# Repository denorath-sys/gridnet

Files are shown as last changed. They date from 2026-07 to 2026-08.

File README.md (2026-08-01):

<p align="center">
  
</p>

# GRIDNET — Powerline Mesh Terminal

> *Communicate over the power grid. No internet. No GSM. No servers.*


[]()
[]()
[]()
[]()

---

## What Is GRIDNET?

GRIDNET is an open hardware mesh communication terminal that uses **existing power line infrastructure** as its transmission medium. Plug the adapter into any wall outlet — the terminal connects to your neighborhood network instantly.

No internet required. No cell towers. No central servers. No accounts.

When grid power fails, the adapter runs from the Terminal's battery over a cable you plug in — the wire is still a conductor whether or not it's energised, so the network keeps working.

The Wi-Fi mesh is not a fallback for the powerline. The two carry to different places: PLC reaches **electrical** neighbours (the same distribution segment, and in practice the same phase), the mesh reaches **physical** ones (adjacent flats, through walls). A neighbour on another phase in the same building is often unreachable over the wire and one mesh hop away. Both run all the time and the router picks per destination — see [`docs/channels.md`](docs/channels.md).

```
Tether:      [Terminal] ←WiFi→ [its own PLC Adapter]      private link to your own modem
PLC:         [Adapter] ←powerline→ [Adapter]              same segment, same phase
Mesh:        [Adapter] ←ESP-NOW→ [Adapter]                physically adjacent, any phase
Outage mode: Grid is down — plug the Terminal into the adapter, network stays alive on battery
```

---

## Why Does This Exist?

Every year, earthquakes, floods, and infrastructure failures cut millions of people off from communication. The internet fails. Cell towers fail. But in most of these scenarios, one thing survives: **the physical power line wiring**.

GRIDNET turns that infrastructure into a resilient local network — inspired by Minitel (France's pre-web national terminal network), FidoNet (a global decentralized BBS built by hobbyists), and the ThinkPad design philosophy (tools built to last).

---

## Hardware Overview

The system consists of two units:

### Terminal
The user-facing device. ThinkPad-inspired clamshell form factor.

| Component | Details |
|---|---|
| **Processor** | GD32VF103CCT6 — RISC-V, 108MHz, 32KB RAM, 256KB Flash |
| **Wireless** | ESP32-C3-MINI-1U — Wi-Fi 2.4GHz mesh + Bluetooth 5.0 LE |
| **Display** | 5.0" TFT LCD, 800×480, RA8875 controller (onboard SDRAM frame buffer), 256 colors, amber-tinted backlight |
| **Keyboard** | 40-key mechanical (Kailh LP), amber LED backlight, red TrackPoint |
| **Right panel** | M1–M4 macro keys + 4×4 numeric keypad + speaker |
| **Speaker** | 1W / 8Ω + PAM8403 amplifier |
| **Storage** | 8MB SPI Flash (LittleFS) + microSD slot |
| **Battery** | 2× 18650, 3350mAh-class genuine cells (~6700mAh total), ~17h active use (screen on) / ~17.5 days standby (screen off, mesh-listen only) — see [`docs/firmware-arch.md`](docs/firmware-arch.md) Power Budget for the full breakdown |
| **Charging** | USB-C, ~4 hours |
| **Antenna** | External, ≤2.33 dBi, on a bulkhead SMA in the case wall — reached by an MHF III / W.FL pigtail from the module's own antenna jack, not by board copper (the module has no RF pad; see [`hardware/pcb/main-board`](hardware/pcb/main-board)) |
| **Dimensions** | 260 × 160 × 28mm, ~680g |
| **OS** | Zephyr RTOS, custom RISC-V BSP |

### PLC Adapter
Separate unit. Plugs directly into any wall outlet (Schuko). Connects to terminal over Wi-Fi — no cables in normal use; during a grid outage the user plugs a USB-C cable in to power it from the Terminal's battery. Replaceable independently.

| Component | Details |
|---|---|
| **PLC SoC** | ST7580 — CENELEC EN50065, OFDM/FSK (band selection under review, see [`docs/electrical-safety.md`](docs/electrical-safety.md)) |
| **Wireless** | ESP32-C3 — Wi-Fi AP for terminal connection |
| **Outage power** | USB-C inlet from the Terminal's battery + 1F supercapacitor hold-up |
| **PLC supply** | MT3608 boost, 5V → 12V for the ST7580's power amplifier |
| **Protection** | TVS P6KE250CA + MOV S20K275 (2 layers; the relay/optocoupler layer went with the inverter) |
| **Power** | HLK-5M05 SMPS, 230VAC → 5VDC |
| **Indicators** | 3× LED: Power / PLC / Wi-Fi |

**Prototype BOM cost: ~$150.22 USD** for one Terminal plus one Adapter — ~$104.35 and ~$45.87 respectively (single unit, retail component pricing). See [`hardware/bom.md`](hardware/bom.md) REV 0.10 for the full breakdown, including why the earlier ~$112 and ~$166.65 figures were both wrong.

---

## Architecture

### Communication Stack

```
┌─────────────────────────────────────────┐
│           APPLICATION LAYER             │
│   Messaging / Games / Forth Apps        │
├─────────────────────────────────────────┤
│           ROUTING LAYER                 │
│   Store-and-forward, 7-day retention    │
│   Mesh routing, automatic repeating     │
├─────────────────────────────────────────┤
│           CHANNEL LAYER                 │
│   Two interfaces, chosen per            │
│   destination by cost — not ranked      │
├─────────────────────────────────────────┤
│           PHYSICAL LAYER                │
│   ST7580 OFDM/FSK, EN 50065-1 limited   │
│   ESP32-C3 Wi-Fi 2.4GHz                 │
└─────────────────────────────────────────┘
```

### Packet Format

```
[AA AA AA][55][LEN 2B][SRC 4B][DST 4B][SEQ 4B][TYPE 1B][PAYLOAD][CRC16 2B]
 preamble  sync  len    source   dest    seq     type     data      checksum

TYPE byte:  [7] SIGNED   [6] RELAYED   [5:0] type code
```

### Addressing

Hierarchical 4-byte address — no central registry required:

```
[CITY 1B][DISTRICT 1B][BUILDING 1B][UNIT 1B]
  01         03           07          12       →  01.03.07.12
```

### Outage Operation

The wire is a conductor whether or not the grid is energising it, so PLC
signalling works during an outage. What stops is the adapter's own power:
it runs from mains, and there is no battery inside it.

So during an outage the adapter runs from the Terminal's battery over a
USB-C cable the user connects. A supercapacitor in the adapter holds it up
long enough to tell the Terminal that mains has gone, so the Terminal can
prompt for the cable. Roughly 5–6 hours of operation with the screen on,
~9 hours with it off.

Nothing is injected onto the wire, and there is no arbitration between
adapters — every node transmits normally under CSMA/CA, exactly as it does
when the grid is up.

Earlier revisions specified a 24V "inverter mode" here instead. It was
removed: it could never have run (the adapter had no power source during
an outage) and it sat 5–24× outside EN 50065-1's signal limits. See
[`docs/plc-adapter-power.md`](docs/plc-adapter-power.md) for the full
analysis, and [`docs/electrical-safety.md`](docs/electrical-safety.md) for
the compliance correction.

### Software Architecture

- **RTOS:** Zephyr (RISC-V support, tickless idle, LittleFS)
- **Boot time:** < 500ms target
- **Tasks:** CHANNEL_MONITOR (0) → PLC_RX (1) → MESH_RX (2) → ROUTER (3) → KEYBOARD (4) → UI (5) → BACKGROUND (6)
- **Filesystem:** LittleFS on 8MB Flash + microSD

Boot screen (Commodore 64 homage):
```
**** GRIDNET OS V1.0 ****
64K RAM SYSTEM  8192K FLASH  BLUETOOTH 5.0
PLC CHANNEL: ACTIVE [3 NODES FOUND]
WIFI BRIDGE: STANDBY  MICROSD: 32GB

READY.
█
```

### Forth VM — Application Platform

Users write and share applications in a sandboxed Forth interpreter (~2KB RAM). Apps are distributed peer-to-peer over the network — like the BBS era.

Security constraints: source address lock, rate limit (5 packets/sec), max 256 bytes/message, filesystem isolation per app.

Example — local market order system in ~15 lines (verified against the
reference VM in [`tools/forth-vm`](tools/forth-vm) — see that directory's
README for why `S"` and `KEY? IF KEY ...` are used instead of the shorter
but non-functional `"` / `KEY? SEND-MSG` you might expect):
```forth
: HEADER
  0 0 S" ╔═══════════════╗" WRITE
  0 1 S" ║  CORNER SHOP  ║" WRITE
  0 2 S" ╚═══════════════╝" WRITE ;

: ORDER
  HEADER
  0 4 S" 1. Bread  2. Milk" WRITE
  KEY? IF KEY S" 01.03.07.99" SEND-MSG THEN ;

: MAIN BEGIN ORDER 1000 WAIT AGAIN ;
MAIN
```

---

## Electrical Safety

GRIDNET puts a low-voltage signal on the mains through a transformer. It does not energise the wire.

- **Signal level is bounded by EN 50065-1**: 5 Vrms at 9 kHz falling to 1 Vrms at 95 kHz. The ST7580's power amplifier delivers 14 V p-p (4.95 Vrms) — ST sized the part to land on that limit — and the adapter adds a hardware current limit as a backstop.
- **PLC signals sit at 95–148.5 kHz**, roughly 2000–3000× the grid frequency. Every household power supply filters that band out; the signal is invisible to their power circuits. Same principle as HomePlug and smart metering, deployed in millions of homes for two decades.
- **Galvanic isolation is mandatory and load-bearing.** The ST7580 reaches the line only through the coupling transformer, and the HLK-5M05 is an isolated supply. The USB-C cable to the Terminal sits on that isolated secondary — the user handles it while the adapter is in a wall socket, so this barrier is what stands between them and the mains.
- **Two protection layers**: TVS (P6KE250CA) for transients, MOV (S20K275) for sustained overvoltage.

⚠️ **One open compliance item**: no EN 50065-1 conformance claim is justified until a conducted-emission sweep is run on a prototype. The band allocation itself is settled — the A-band (9–95 kHz) is reserved for electricity suppliers, so GRIDNET uses B (95–125 kHz) and C (125–140 kHz), and the hardware commits to that choice through Board 1's coupling network ([`docs/plc-coupling.md`](docs/plc-coupling.md), [`docs/protocol.md`](docs/protocol.md)). What remains is the measurement, which needs hardware that does not exist yet. See [`docs/electrical-safety.md`](docs/electrical-safety.md) REV 0.6, which also corrects an earlier claim in this project that a 24V injection was within EN 50065 limits. It was not.

---

## Use Cases

| Scenario | Description |
|---|---|
| 🏚 Disaster response | Coordinate with neighbors when grid, internet, and cell are all down |
| 🏘 Neighborhood messaging | Hyperlocal communication without internet subscriptions |
| 🛒 Local commerce | Shops write their own order systems in Forth — no cloud, no monthly fee |
| 🎮 Games | Turn-based strategy and text adventures played over the power grid |
| 🔒 No cloud | No accounts, no logs, no servers — nothing leaves the neighbourhood. Note that this is *not* the same as confidentiality: the protocol has no encryption yet, and store-and-forward means a message can sit in a relaying neighbour's device for up to 7 days in plaintext. See "Known Gaps" below |
| 👾 Retro / Hacker | Amber display, mechanical keyboard, Forth VM, RISC-V. It boots to READY. |

---

## Project Status

| Component | Status |
|---|---|
| Hardware architecture (dual-board design) | ✅ Complete |
| Communication protocol stack | 🔄 **Under revision — was marked complete, and wasn't.** Three separate design faults are now documented: it does not scale ([`docs/routing.md`](docs/routing.md) — twenty nodes on one segment spend 30.7% of the channel on routing advertisements), it has no authentication of any kind ([`docs/threat-model.md`](docs/threat-model.md)), and its channel model ranks the Wi-Fi mesh as a fallback for the powerline when the two reach different sets of nodes ([`docs/channels.md`](docs/channels.md)). Each has a decided design; none is implemented, and [`docs/protocol.md`](docs/protocol.md) still specifies the old behaviour alongside notices of what replaces it |
| PLC Adapter power architecture ([`docs/plc-adapter-power.md`](docs/plc-adapter-power.md)) | ✅ Complete — adapter runs off the Terminal's battery during an outage; the 24V inverter and its master-election protocol were removed (never able to run, and outside EN 50065-1) |
| Protection circuit (TVS + MOV) | ✅ Complete — two layers, not three: the relay/optocoupler layer went with the inverter. Parts selected ([`hardware/bom.md`](hardware/bom.md)) and now drawn — `P6KE250CA` and `S20K275` are in Board 1's schematic and placed on its PCB |
| Main Board schematic + PCB layout ([`hardware/pcb/main-board`](hardware/pcb/main-board)) | ✅ Complete — custom parts datasheet-verified, PCB placed, routed, ground-poured on both layers, DRC clean (0 violations, 0 unconnected). REV 0.7 was a pre-fab design review that caught a refdes-drift bug placing parts in each other's positions (crystal load caps 51mm from the crystal), a boost-converter switching loop spread across 63mm, and every trace at 0.2mm including a 2.4A path. REV 0.8 found the antenna path was fiction — a phantom U.FL duplicating the module's own jack, a trace nothing could drive, and an invented `ANT` symbol pin — and that the "grid of stitching vias" was nine vias in one column, because `BOX2I.Inflate()` mutates in place (now 167, worst-case return path 55mm → 16.8mm) — see that directory's README |
| PLC/Power Board (BOM's Board 1, the PLC Adapter's PCB — see [`hardware/pcb/plc-board`](hardware/pcb/plc-board)) | ✅ REV 0.3 schematic complete, ERC-clean (350 warnings, 0 errors). Power architecture: Terminal USB-C inlet, Schottky ORing, supercapacitor hold-up, 5V→12V boost feeding the ST7580's `VCC`, hardware transmit-current limit. Line coupling now built too — transmit active filter around the ST7580's own PA, receive resonant filter, and the coupling transformer into the mains. Topology from ST's AN4068, values rescaled from its A-band reference design to GRIDNET's 95–140 kHz band ([`docs/plc-coupling.md`](docs/plc-coupling.md)). PCB placement complete (REV 0.5), now a **four-layer** board: L1/L4 signals, In1.Cu GND plane, In2.Cu +5V plane. Four layers because the ST7580's nine +5V pads on a 48-pin 0.5mm-pitch package need a plane, and two two-layer copper layers are already spoken for by ground and the mains barrier — see that directory's README for the four runs that established it. The 7.96mm isolation barrier cuts all four layers and only the AC-DC module and the coupling transformer cross it; verified geometrically on every pad, track, via and filled zone. Routing (REV 0.6) runs end to end: the autorouter gets 174 nets to 4-10 and the repair step closes most of the rest, but every attempt ends holding exactly one connection. Six defects were fixed getting there — QFN power fanout, pour-before-repair ordering, netclass-aware repair, a mains column too narrow for its own clearance rule, a keepout halo that made a pad unroutable, and a footprint hanging off the board edge. |
| Case design (CAD) | 📋 Planned — only target external dimensions exist (see Hardware Overview); no CAD model |
| Software architecture (Zephyr + Forth VM) | ⚠️ Complete on paper, with one known conflict — [`docs/threat-model.md`](docs/threat-model.md) found that Ed25519's 1–2KB working set does not fit the `ROUTER` task's 2048B stack, which is why the crypto moves to the ESP32-C3 and the node's identity ends up belonging to that module |
| Electrical safety analysis | ✅ Complete |
| Protocol & Forth VM reference prototypes ([`tools/`](tools/), Python, pre-hardware validation) | ✅ Complete — 90 tests pass. Note that `protocol-sim` implements the protocol as specified today, so the routing, authentication and channel revisions above will need to land there too before they mean anything |
| **PCB fabrication / Hardware prototype** | 🔄 Next step — Main Board has been through two design-review passes and is DRC-clean. RF layout is no longer on its list: there is no RF net on the board (the antenna is a cable assembly from the module's own jack). The stackup is no longer an open decision — it is now `STACKUP` in `build_pcb.py` (1.6mm FR-4, two layers, 1oz copper) and written into the board's own design rules, which turned up that KiCad's manufacturing minimums had been left at zero all along: every "0 violations" this project reported before that had been measured against no process limit at all. The board passes the real rules unchanged. What is left before fab is a return-path review of the SPI/I2C buses and a human eye on the autorouted copper (see [`hardware/pcb/main-board`](hardware/pcb/main-board) "What's not done yet"). Board 1 is further along than "schematic complete" — it is placed, four-layer, and routed end to end but for a single connection every attempt ends holding (REV 0.6). Before it is fabricated it needs that last net closed and the mains creepage/clearance treatment the Main Board never required; before any EN 50065-1 claim it needs a conducted-emission sweep |
| Embedded firmware (Zephyr, on real hardware) | 📋 Planned — starts after PCB prototype |
| **Link-budget survey** (rides along with the prototype) | 📋 Blocking four documented decisions — cross-phase attenuation, how much of a real segment hears itself, mesh reach through actual walls, and ESP-NOW throughput for small frames. Every routing and channel figure in this project is arithmetic from datasheet-class assumptions, not evidence. This is now the cheapest thing that would tell us whether the design is right |
| Field testing | 📋 Planned |

---

## Known Gaps

Things this design does not currently do. They are listed here rather than
left for a reader to discover, because two of them affect whether the
network can be trusted in the situation it exists for.

**There is no message authentication.** `SRC` is a plaintext field in the
packet header, and on a shared broadcast medium any node can set it to any
value. The sandbox rule in [`docs/protocol.md`](docs/protocol.md) —
"source address locked, app cannot spoof sender" — constrains a Forth app
running on its own device; it says nothing about a modified node. The
consequences follow directly:

- **ROUTE poisoning.** The routing layer is distance-vector with no
  authentication, so any node can advertise `hop_count 0` for an address it
  does not own and pull that traffic to itself.
- **Forged emergency broadcasts.** `BROADCAST 0x03` is flooded to the whole
  mesh and signed by nothing.
- **Storage exhaustion.** Store-and-forward holds messages for 7 days on
  behalf of unauthenticated senders.
- **Unverified code distribution.** `APP_DATA 0x10` moves Forth applications
  peer-to-peer, from peers whose identity is not established.

Firmware updates *are* signed — Ed25519, verified by the bootloader
([`docs/firmware-arch.md`](docs/firmware-arch.md)). The network layer has
no equivalent.

A threat model now exists for closing this: [`docs/threat-model.md`](docs/threat-model.md)
scopes the adversary as a hostile neighbour on the same wire, and records
the decisions — Ed25519 identity bound to an address by trust-on-first-use,
signing tiered so that routing, broadcasts and code are always signed while
ordinary messages are opt-in, and the crypto moved to the ESP32-C3 because
Ed25519's working set does not fit the `ROUTER` task's 2KB stack. **Nothing
is implemented**; the wire format above is still the unauthenticated one.

It is also explicit about what authentication does *not* fix — a signed
route advertisement proves who said it, not that the route exists — and
about what stays out of scope: device theft, traffic analysis and jamming.

**`ROUTE` does not scale, independently of security.** Twenty nodes on one
distribution segment would spend 30.7% of a 2.4 kbps channel on routing
advertisements alone. [`docs/routing.md`](docs/routing.md) redesigns it
around a property the original missed — a PLC segment is a broadcast domain,
so one-hop neighbours can be learned passively at zero airtime cost — which
takes the same case to 1.89%. That document also states, for the first time
in this project, what topology the network is assumed to have, and flags
that the assumption has never been measured.

**Duplicate addresses are not detected.** Addresses are self-assigned with
no registry, and `docs/protocol.md` currently attributes collision
detection to CSMA/CA. That is a media-access mechanism — it detects a busy
channel, not two nodes claiming `01.03.07.12`. Nothing in the protocol
notices the duplicate, and the routing table oscillates when it happens.

**No encryption.** Message contents are plaintext on the wire and plaintext
in every relaying device's store-and-forward queue.

---

## Repository Structure

```
gridnet/
├── README.md
├── LICENSE                    (CERN-OHL-W-2.0)
├── CONTRIBUTING.md
├── hardware/
│   ├── pcb/
│   │   ├── main-board/         (Board 2 — KiCad schematic + routed, ground-poured PCB, see its README)
│   │   └── plc-board/          (Board 1 — KiCad schematic + placed PCB, see its README)
│   └── bom.md                 (bill of materials)
├── docs/
│   ├── protocol.md            (full protocol stack)
│   ├── firmware-arch.md       (Zephyr + Forth VM)
│   ├── threat-model.md        (adversary scope, attacks, auth decisions)
│   ├── routing.md             (why ROUTE doesn't scale, and the redesign)
│   ├── channels.md            (PLC vs mesh: what each actually reaches)
│   ├── electrical-safety.md   (CENELEC compliance)
│   ├── plc-adapter-power.md   (adapter power architecture + EN 50065 analysis)
│   └── plc-coupling.md        (line coupling network: AN4068 retuned for B+C)
├── firmware/
│   └── README.md              (planned structure — embedded firmware not started)
├── tools/
│   ├── protocol-sim/          (Python reference implementation of docs/protocol.md)
│   └── forth-vm/              (Python prototype of the sandboxed Forth VM)
└── media/
    ├── logo-cyan.svg
    └── logo-silver.svg
```

Note: `hardware/case/` and `hardware/schematics/` (now just a pointer to
`hardware/pcb/`) aren't in the tree above because there's nothing under
either yet worth listing — see the Project Status table above.

---

## Looking For

- Hardware engineer with embedded systems / PCB experience
- Anyone with real-world ST7580 / PLC field experience
- Zephyr RTOS developers (RISC-V BSP, driver development)
- Forth enthusiasts — help design the VM standard library
- Beta testers willing to run a node in their building

Open an Issue or email directly if you're interested in collaborating.

---

## Inspiration

**Minitel** — France's pre-web national terminal network. A whole country connected, locally, before the internet existed.

**FidoNet** — A global decentralized BBS network built by hobbyists. Store-and-forward over phone lines. No servers. No company.

**ThinkPad** — A design philosophy: every detail intentional, built to last, keyboard first.

---

## License

Hardware designs and documentation: [CERN Open Hardware Licence v2 — Weakly Reciprocal (CERN-OHL-W-2.0)](https://ohwr.org/cern_ohl_w_v2.txt)

Firmware (when released): GPL-3.0

© 2026 Yasar — Open Hardware Project

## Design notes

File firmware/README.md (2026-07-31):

# GRIDNET — Firmware

**Status: Not started.** Firmware development begins after the hardware
prototype is complete and validated — see the top-level README's Project
Status table.

Two Python prototypes already exist and inform this planned structure:
[`tools/protocol-sim/`](../tools/protocol-sim/) validates the protocol/routing stack that `src/router/`
and `src/channel/` will implement, and [`tools/forth-vm/`](../tools/forth-vm/) validates the Forth
VM that `src/forth/` will implement. Neither is a substitute for real
firmware — see their own READMEs for what's actually been tested.

## Planned Structure

```
firmware/
├── README.md              ← this file
├── CMakeLists.txt         ← Zephyr build system
├── prj.conf               ← Kconfig project configuration
├── boards/
│   └── gridnet/           ← Custom Zephyr BSP
│       ├── gridnet.dts    ← Device Tree
│       ├── gridnet_defconfig
│       └── board.cmake
├── src/
│   ├── main.c             ← Entry point, task init
│   ├── plc/               ← ST7580 driver + protocol stack
│   ├── mesh/              ← Wi-Fi mesh (ESP32-C3 interface)
│   ├── router/            ← Mesh routing, store-and-forward
│   ├── ui/                ← LCD driver, screen rendering
│   ├── keyboard/          ← Key matrix, TrackPoint
│   ├── forth/             ← Forth VM + sandbox
│   ├── storage/           ← LittleFS + microSD
│   └── channel/           ← Automatic channel switching
└── bootloader/
    ├── main.c             ← Bootloader (microSD + DFU update)
    └── crypto/            ← Ed25519 signature verification
```

Note that `bootloader/crypto/` is the only cryptography in this tree. The
protocol layer that `src/router/` and `src/plc/` will implement has no
authentication designed for it yet — see [`docs/protocol.md`](../docs/protocol.md)
"Security — What Is Not Protected" before building on it.

## Build Requirements

- Zephyr RTOS v3.x
- West (Zephyr build tool)
- RISC-V GCC toolchain
- Optional: OpenOCD (JTAG debug)

## Contributing

If you have experience with Zephyr RTOS, RISC-V, or ST7580 PLC and want to contribute, please open an Issue or see [`CONTRIBUTING.md`](../CONTRIBUTING.md).

See [`docs/firmware-arch.md`](../docs/firmware-arch.md) for full architecture documentation.

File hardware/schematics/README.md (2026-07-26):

Schematics

This directory was a placeholder before either board had real schematic
work. Both now live under `hardware/pcb/`, alongside their PCB layout
(where one exists) rather than as separate PDF exports:

- `hardware/pcb/main-board/` — Board 2 (Main Board): KiCad schematic +
  routed, DRC-clean PCB.
- `hardware/pcb/plc-board/` — Board 1 (PLC/Power Board, the PLC
  Adapter's PCB): KiCad schematic for the well-specified parts; no PCB
  layout yet, see that directory's README for what's still missing.

This directory is kept as a pointer rather than removed, in case
something still links here.

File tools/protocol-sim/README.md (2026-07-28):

# GRIDNET Protocol Simulator

A pure-Python, hardware-independent reference implementation of
[`docs/protocol.md`](../../docs/protocol.md). It exists to validate the mesh
routing and store-and-forward logic *before* the hardware prototype exists — the firmware architecture doc lists the protocol
stack as "✅ Complete," but until now that meant "specified in prose,"
not "specified and exercised by running code."

No dependencies beyond the Python 3 standard library.

## What it implements

- **Packet framing** (`gridnet_sim/packet.py`) — the exact wire format from
  `docs/protocol.md`: preamble/sync/len/src/dst/seq/type/payload/CRC16, with
  encode/decode and CRC validation.
- **Hierarchical addressing** (`gridnet_sim/address.py`) — the 4-byte
  `CITY.DISTRICT.BUILDING.UNIT` scheme, including the broadcast address.
- **A discrete-event simulator** (`gridnet_sim/simulator.py`) — simulated
  time, not wall-clock time, so a "7-day" store-and-forward expiry costs
  nothing extra to run.
- **A shared-medium / CSMA-CA model** (`gridnet_sim/medium.py`) — one
  `Medium` per PLC segment or per WiFi mesh: carrier sensing, random backoff,
  and collisions between overlapping transmissions. Simplified (no PHY-level
  bit errors, no capture effect) — it's here to exercise the *link-layer
  contention* the protocol assumes, not to model CENELEC OFDM/FSK.
- **Mesh flooding + store-and-forward** (`gridnet_sim/node.py`) — a `Node`
  that floods unknown destinations, relays each `(src, seq)` exactly once,
  and retries undelivered messages until ACKed or expired.
- **ROUTE distance-vector routing** (`gridnet_sim/node.py`) — periodic
  table advertisements (own routes, hop-incremented) per
  `docs/protocol.md`'s REV 0.5 ROUTE Packet section, converging multi-hop
  reachability + next-hop info one hop per round, RIP-style hop-count cap
  and staleness pruning included.

## Running it

```bash
cd tools/protocol-sim
python3 run_demo.py --list
python3 run_demo.py master-failover
python3 -m unittest discover -s tests -v
```

Nine scenarios are in `gridnet_sim/scenarios.py`: `basic-exchange`,
`multihop-flood`, `routing`, `store-and-forward`, `channel-fallback`. 29
unit tests in `tests/` cover packet framing, flooding loop-prevention,
store-and-forward and distance-vector route convergence — all deterministic
(seeded RNGs), run in well under a second.

## Findings — and the fixes applied for them (REV 0.5)

Building and extending this surfaced three things about the *documented*
protocol (two REV 0.4 behavioral gaps, one packet type named but never
defined) and two bugs in the simulator's own code, one found while fixing
the other. All five were fixed.

> **Note on #1–3.** These concern the inverter master election protocol,
> which has since been **removed from GRIDNET entirely** — the PLC Adapter
> turned out to have no power source during a grid outage, so it could never
> have run an inverter, and the 24V injection the protocol arbitrated sat
> well outside EN 50065-1's limits. See
> [`docs/plc-adapter-power.md`](../../docs/plc-adapter-power.md). The
> corresponding code, tests and scenarios are gone from this simulator. The
> writeups are kept because the reasoning — about jitter, listen windows and
> shared RNG state — is worth having on the record, and because #5 in
> particular is a general lesson that outlived the feature that exposed it.

### 1. FIXED — Simultaneous grid loss reliably triggered split-brain, not just as an edge case

REV 0.4's initial listen delay was a flat 2 seconds with no jitter. The most
common real-world trigger — an entire building or block losing grid power at
once — meant every device on the segment hit that 2-second timeout at the
*same instant* and every one of them tried to become master simultaneously,
every run. Split-brain detection resolved it correctly (lower address wins),
but that made split-brain the *primary* path for the most common outage
pattern, not a rare fallback — working against the doc's own rationale for
avoiding simultaneous injection ("voltage conflict... signal corruption...
excess current").

**Fix**: `grid_lost()` now uses `LISTEN_DELAY + random(0, LISTEN_JITTER)`
(2s + up to 500ms). Whichever device draws the shortest delay usually
asserts first and the others just hear it — no split-brain needed for the
common case. `scenario_master_election` demonstrates the fixed convergence;
`scenario_master_election_worst_case` / `test_split_brain_still_resolves_ties`
force an exact jitter tie to prove split-brain still works as the residual
safety net, same as REV 0.4.

### 2. FIXED — A new device could steal mastership from a stable, already-elected master

REV 0.4 stated: *"A new device always listens first. If it hears
MASTER_ALIVE, it becomes a slave."* But it used the same 2s window for
joining as for a fresh grid failure — much shorter than the 10s
MASTER_ALIVE interval, so a device joining at an arbitrary moment only had
roughly a 20% chance of its listen window actually overlapping a heartbeat.
The other ~80% of the time, it heard nothing, timed out, and declared itself
master. If its address happened to be lower than the existing master's, it
won the resulting split-brain and forced an already up-and-running master to
step down and resign — a real service interruption caused purely by unlucky
join timing, not any actual fault.

**Fix**: joining is no longer routed through the same short delay as a
self-witnessed grid failure. New method `cold_join()` — for a device
powering on or rejoining while the grid is already off, which can't assume
no master exists — uses `JOIN_LISTEN_DELAY + jitter` (12s, i.e.
`MASTER_ALIVE_INTERVAL + 2s` margin), reliably spanning a full heartbeat
cycle. `scenario_cold_join` and
`TestColdJoin.test_reliably_hears_existing_master_regardless_of_join_timing`
(swept across four join offsets spanning the heartbeat cycle) demonstrate
it now converges every time.
`test_grid_lost_is_the_wrong_call_for_joining_an_existing_segment` is kept
as a regression guard on the API distinction: calling `grid_lost()` instead
of `cold_join()` for a join still reproduces the old bug, which is correct —
that method's short delay is only safe for the scenario it's meant for.

### 3. FIXED (simulator bug, not a protocol issue) — a float-rounding edge case could permanently skip failover

While stress-testing fix #1 across many runs, `_check_master_timeout`
occasionally never triggered failover at all, even 30+ seconds after the
master went silent. Cause: it recomputed `sim.now - last_master_alive_heard
>= MASTER_TIMEOUT`, and floating-point rounding could land that a hair under
30 (observed: `29.999999999999996`), even though the callback is only ever
scheduled for exactly `last_heard + MASTER_TIMEOUT`. Since nothing else ever
rechecked it, the node just stayed `INV_SLAVE` forever, pointing at a master
that was gone. The check was redundant anyway — a matching `_inv_epoch` (the
staleness guard already used everywhere else in this file) already
guarantees no newer heartbeat arrived — so it's removed rather than patched
with an epsilon. Confirmed via a 300-run stress loop with unseeded jitter
after the fix (0 failures, previously ~35% failure rate).

### 4. FIXED (protocol gap) — ROUTE (0x04) was named but never defined

`docs/protocol.md`'s message-type table listed `ROUTE 0x04 — Routing table
update` alongside the (then-present) MASTER_ALIVE and MASTER_RESIGN types,
but unlike those two — which had full C structs — ROUTE had zero payload
definition anywhere — and "Mesh Routing" claimed every device maintains "a
neighbor table (address, hop count, last seen)" with no mechanism specified
for how a hop count beyond 1 would ever be learned. The simulator's own
flooding logic only ever produced 1-hop `known_nodes` entries
(deliberately segment-scoped) — there was no path to actual
multi-hop reachability info anywhere in this codebase either.

**Fix**: `docs/protocol.md` REV 0.5 now defines ROUTE as a distance-vector
advertisement — `{address:4B, hop_count:1B}` entries, periodic (60s, chosen
for airtime reasons — see the doc), never flooded (each device re-advertises
its own table, RIP-style propagation), with a 15-hop cap and 3-interval
staleness window. Implemented in `Node._advertise_routes` /
`Node._on_route`; `scenario_routing` and `tests/test_routing.py` demonstrate
a 4-node/3-hop chain converging to correct hop counts and next-hops in both
directions.

### 5. FIXED (simulator bug, not a protocol issue) — a shared RNG silently broke already-seeded tests

Wiring up ROUTE's periodic advertisement needed a randomized startup stagger
(so devices booting together don't broadcast in lockstep forever). The first
version drew it from `self._rng` — the same RNG `grid_lost()`/`cold_join()`
use for listen-delay jitter, and the one tests seed for reproducibility. That
extra draw at construction time shifted every subsequent draw from that
stream, silently changing the jitter values the already-passing
then-present inverter-master tests depended on — `test_simultaneous_grid_loss_no_longer_reliably_collides`
started intermittently failing (split-brain rate crept from comfortably under
20% to 23%) with no change to that code at all. Fixed by
giving the ROUTE stagger its own independent `self._route_rng` — sharing a
stateful RNG across unrelated concerns is exactly the kind of coupling that's
invisible until something downstream reads the stream differently.

## Assumptions made where the docs didn't specify a value

- **CRC16 variant**: CCITT-FALSE (poly `0x1021`, init `0xFFFF`) —
  `docs/protocol.md` says "CRC16" without naming a polynomial. Swap
  `gridnet_sim/crc16.py` if firmware settles on something else; nothing else
  depends on the specific algorithm.
- **Dedup / relay window**: 15 seconds — how long a node remembers a
  `(src, seq)` it has already relayed, so it doesn't repeat itself. Not
  specified in `docs/protocol.md`; chosen shorter than the retry interval so
  a legitimate retry isn't mistaken for a duplicate and silently dropped by
  intermediate relays.
- **Store-and-forward retry interval**: 30 seconds — not specified; the doc
  only gives the 7-day total retention.
- **ROUTE advertisement interval**: 60 seconds, hop cap 15, staleness 3
  intervals (180s) — none specified before REV 0.5; see `docs/protocol.md`'s
  ROUTE Packet section for the airtime-cost rationale behind 60s.

## Repository layout

```
tools/protocol-sim/
├── README.md              (this file)
├── run_demo.py             CLI entry point
├── gridnet_sim/
│   ├── address.py          4-byte hierarchical addressing
│   ├── crc16.py             CRC16/CCITT-FALSE
│   ├── packet.py             wire framing, encode/decode
│   ├── medium.py              shared broadcast channel, CSMA/CA, collisions
│   ├── node.py                 flooding, store-and-forward, distance-vector routing
│   ├── scenarios.py             five runnable demonstrations
│   └── simulator.py              discrete-event core
└── tests/
    ├── test_packet.py
    ├── test_flooding.py
    ├── test_routing.py
    └── test_store_and_forward.py
```

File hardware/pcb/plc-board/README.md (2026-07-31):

GRIDNET — PLC/Power Board KiCad Schematic + PCB
REV 0.6 (Board 1, the PLC Adapter's own PCB — see "Board 1 is the PLC
Adapter's PCB" below.)

What changed in REV 0.6
------------------------

**The stackup is a rule now, not a sentence.** `STACKUP` in `build_pcb.py`
is written into the board's design settings: 1.6mm FR-4, four layers, 1oz
outer copper (0.5oz inner, which does not matter here — the inner layers carry
only planes and every current-carrying trace, the 1.0mm mains nets included,
is on an outer layer), 0.2mm minimum track and clearance, 0.6mm vias on 0.3mm
drills, 0.15mm annular ring, 0.25mm hole-to-hole.

This came out of closing the same item on the Main Board, where it exposed
something worse than an undocumented assumption: KiCad's minimums default to
zero, and both boards carried `m_TrackMinWidth = 0.0` and
`m_MinClearance = 0.0` through every DRC run this project has reported. A
0.05mm trace would have passed.

It caught something here immediately. The power fanout sends each of U4's
power pads 1.6mm straight out, and those pads are on a 0.5mm pitch — so their
vias landed on a 0.5mm pitch too, which with a 0.3mm drill is 0.2mm
hole-to-hole against the 0.25mm rule. Three pairs. The fanout now checks
hole spacing and steps a crowded neighbour further out.

A routing pass. It did not finish — every run still ends one connection
short — but what it found is worth more than the routing would have been:
six separate defects stood between this board and a routed one, and each was
invisible until the router hit it.

**The QFN's power pins had no fanout.** The ST7580 puts nine +5V pads on
three edges of a 48-pin 0.5mm-pitch package. Nothing passes between adjacent
pads there, so each escapes radially, and the router then has to bring nine
radial escapes back together around the outside of eleven others. Every run
this project had made died on that. `add_power_fanout()` now gives each power
pad a 1.6mm stub and a via at build time — what a person does by hand on a
QFN and what no autorouter does for itself.

**The pour ran after the repair, so the fanout vias were islands.** Planes
are what connect those vias; until the copper is poured they are isolated
points, and the repair router was being asked to tie them together — the
exact problem the fanout removes. `route.sh` now pours before repairing. This
is not the ordering the Main Board warns about: there the danger is pouring
before *routing*, which makes the autorouter treat GND as done. With those
two changes together, +5V stopped being a holdout at all.

**The repair router ignored netclasses.** It laid 0.2mm track at 0.2mm
clearance into the `Mains` class, which is 1.0mm at 2.5mm — on the mains side
that is not a style question, it is the live-to-neutral spacing. Seven
clearance errors in one run, every one on `/AC_L`, `/AC_N` or `/PLC_LINE`,
all laid by the step meant to be finishing the job. It now reads the rules
from the same table `build_pcb.py` writes into the project file: KiCad 9's
Python binding returns `GetNetClass()` as a bare object with no accessors, so
importing the source of truth is both simpler and harder to get out of step.

**Correcting that exposed a floorplan that could not satisfy it.** Four mains
nets at 1.0mm and 2.5mm need a 3.5mm pitch — about 16.5mm of channel with
margins — and the mains column had 9.7mm once the parts were in it. The
varistor lying flat is 22mm wide and blocked the column outright. `BARRIER_X`
moved from 30 to 36, the varistor and the X1 capacitor now stand on end, and
the isolated side gave up 6mm it was no longer short of.

**And then `/AC_N` still would not route — the repair router again.** It
stamped rule areas as obstacles inflated by the netclass clearance, which for
a mains net is a 3mm halo. The isolation band starts at x = 32.02, so the halo
reached 29.02 and swallowed T1's own mains pad at 30.92: that pad was
unroutable by construction. A keepout is a boundary, not a conductor — copper
may come up to its edge, it just may not cross. Stamping it with half the
track width instead closed `/AC_N` in two segments.

**A footprint was hanging off the board.** The JTAG header was moved to the
top edge without checking its height: 13.79mm upright, centred at y = 4.6, put
a third of it past y = 0. A whole routing run went by before anything noticed,
and what noticed was the repair router reporting an unconnected item at
y = −0.58. `check_on_board()` is now one line of arithmetic at placement time.

Where that leaves routing: the autorouter gets 174 nets down to 4–10, the
repair step closes most of the rest — eleven connections in one run — and each
attempt ends holding exactly one. The holdouts are now a different ordinary
signal every time (`/PLC_LED`, `/ST_CL`, `/ST_BR0`) rather than the systematic
`+5V` cluster they were before, which is the signature of a board at the edge
of what this toolchain does rather than of a defect. A ten-attempt run was
started to let nondeterminism land it; Freerouting hung on the first attempt
for 46 minutes and the run timed out. That hang is documented in the Main
Board's README too.

The board committed here is therefore placement, not routing: 62 components,
25 thermal vias, 11 power fanouts, two keepout zones, DRC clean at 0 errors.

What changed in REV 0.5
------------------------

**This is a four-layer board now**, and not for signal density — it could very
nearly be routed on two. It is four because of what has to be *planed*.

```
  L1  F.Cu    signals, all components
  L2  In1.Cu  GND plane      (4984 mm², isolated side only)
  L3  In2.Cu  +5V plane      (4960 mm², isolated side only)
  L4  B.Cu    signals
```

The ST7580 puts nine +5V pads on three edges of a 48-pin 0.5mm-pitch package.
Nothing passes between adjacent pads there — a 0.2mm track with 0.2mm
clearance needs 0.6mm and the gap is 0.25mm — so every pin escapes radially,
and those nine have to find each other around the outside of eleven other
escapes. **Four full two-layer routing runs failed on exactly that**, and
never on the same pad twice: (52.05, 6.70), (59.45, 11.25), (59.45, 8.25),
and twice on the pin 3 / pin 48 pair that wraps the top-left corner. A fifth
run with a filled +5V island on F.Cu routed cleanly — and was then broken by
its own ground pour, which chopped the island from 413 mm² to 109 mm² and
stranded eight connections. That net wants a plane, and on two layers both
copper layers are already spoken for by ground and the mains barrier.

**The barrier goes through all four layers.** An inner plane that crossed it
would bridge mains to SELV *inside the laminate*, where no inspection would
ever find it. Both keepout rule areas are on all four copper layers and both
planes stop at `SELV_MIN`; that is checked, not assumed — the filled polygons
start at exactly x = 33.98.

Two things the layer change taught, both recorded in `route.sh` so they are
not rediscovered:

- **Do not mark the inner layers `(type power)` in the DSN.** KiCad writes
  every copper layer as `(type signal)`, and rewriting the two inner ones does
  stop Freerouting laying signals across the planes — but it also stops it
  treating those planes as connecting GND and +5V, so it routes both as
  ordinary nets on two layers and fails badly: 52 unrouted against 7 without
  the change. The planes take some cutting from inner-layer signals; each is
  ~5000 mm² and the refill after routing closes around whatever crosses them.
- **The repair router had no idea planes existed.** It indexed a two-entry
  layer tuple with whatever layer it found a track on, and threw on the first
  inner-layer track. It now ignores inner-plane copper for its F.Cu/B.Cu
  occupancy grid, and can terminate a connection with a via down to a plane
  instead of a track to another pad — which on a planed net is usually the
  correct answer and is what Freerouting itself does.

Routing is **not finished**; see "What's not done yet".

What changed in REV 0.4
------------------------

The board has a PCB. `plc-board.kicad_pcb` places all 62 components inside
the 100×80mm outline, with thermal vias under both exposed pads and the
design rules written into `plc-board.kicad_pro`. Nothing is routed yet.

The thing that shapes this layout and did not exist on the Main Board is that
**half of this board is at mains potential**:

```
  x = 0                     BARRIER_X = 30                       x = 100
  |<----- mains side ------>|<-- 7.96mm -->|<--- isolated side --->|
  | J1 mains in, TVS, MOV,  |   no copper  | ST7580 + coupling     |
  | X1 cap, series inductor |  either side | filter, ESP32, power  |
  |                         |              | tree, USB-C to the    |
  |         U1 (HLK-5M05) --+--------------+-- Terminal, LEDs      |
  |         T1 (coupling) --+--------------+                       |
```

Only two parts cross that band, and each crosses it *inside its own body*,
where the manufacturer rather than this project is responsible for the
insulation: the HLK-5M05 (AC pins one end, DC pins 33.6mm away at the other)
and the coupling transformer. **The barrier's width is not a number this
project picked**: it is what T1's own land pattern leaves between primary and
secondary once the 2.2mm pads come off the 10.16mm pitch. Würth sized that
gap for a transformer whose entire job is to sit across a mains barrier.

Three mechanisms keep it that way, because placement alone would not:

- `check_isolation_barrier()` in `kicad_gen/build_pcb.py` tests **every pad of
  every net** on the board — not just the parts someone remembered to
  classify as mains — against the band, using pad bounding boxes rather than
  centres, since it is the copper edge that matters for creepage. It also
  asserts that exactly `U1` and `T1` have pads on both sides. The build
  refuses to write a board that fails either test; that refusal was checked by
  deliberately dragging `C17` across the barrier and confirming it fired.
- **The ground pour is clipped to the isolated side.** This is the one
  function that could not be reused from the Main Board unchanged. There the
  pour is the whole board; here a full-width pour would put GND copper
  straight through the barrier, and it would do it *silently*, because a zone
  is not a track and would not show up in a routing review. The mains side
  gets no plane at all, which is also correct on its own terms — there is no
  mains-referenced ground on this board, since the Schuko earth pin is unused.
- **The stitching-via grid starts at the barrier**, not at the board edge.

What the standards ask, and what is still open: reinforced insulation from
230V mains to a user-accessible SELV circuit is usually quoted around 5mm
creepage and 3–4mm clearance (IEC 60950-1 / 62368-1, pollution degree 2,
material group IIIa), with 8mm a common industry rule of thumb that includes
margin. 7.96mm sits in that band. The insulation here has to be *reinforced*
rather than basic, because the user physically handles the USB-C cable on the
isolated side while the adapter is in a wall socket. Confirming the exact
figure against the standard itself is listed under "What's not done yet" — it
is the one number in this layout taken from convention rather than from a
document this project has read.

Two findings came out of running DRC on the first placement, neither of which
a schematic pass could have surfaced:

- **The mains connector could not meet its own clearance rule.** The 2.5mm
  L-to-N spacing in the `Mains` netclass is the standards-derived figure; the
  5.08mm-pitch terminal block leaves 2.08mm between its own pads. The part was
  the placeholder, not the rule, so `J1` is now a 7.62mm-pitch Würth block.
- **The ST7580 footprint's built-in thermal vias are 0.2mm**, under the 0.3mm
  minimum in this project's board setup and JLCPCB's standard process, which
  hardware/bom.md's PCB line assumes. All 25 came back as `drill_out_of_range`.
  `U4` now uses the plain QFN footprint and `add_thermal_vias()` lays a 4×4
  array at 0.3mm — 4×4 because that is the array AN4068 measures the part's
  50 °C/W on, not a round number.

And one the DRC could not have found, which took rendering the board and
looking at it: **the ESP32-C3-MINI-1's antenna was in the middle of the
board.** The `-1` variant has an on-module PCB antenna and a real keepout
zone in its footprint (5.4 × 13.2mm, marked "Antenna Area", blocking copper
pour, tracks and vias), and the first placement had it surrounded by circuit
on all four sides. It is now at the right edge with the antenna facing out.
Note the asymmetry with the Main Board: that one carries the `-1U`, whose
datasheet Note A says explicitly it has *no* keepout zone because its radio
leaves on a cable. Same datasheet, same pin table, opposite layout rule.

What changed in REV 0.3
------------------------

The line coupling is built. That was the last open block on this board and
the reason its PCB layout had not started: the ST7580 datasheet specifies
the PA's pins but not the network hung off them, and AN4068 — which does —
could not be retrieved from this environment. It was eventually read, and
the whole section between `TX_OUT`/`PA_OUT` and the mains now exists.

The values are **not** AN4068's. Its reference design is a CENELEC A-band
node — receive filter on 80 kHz, coupling resonance on 85 kHz, sensitivity
specified at 86 kHz — and A-band is allocated to electricity suppliers.
GRIDNET sits in B+C, 95–140 kHz, which puts our entire band on the skirt of
their filters. Each resonance was rescaled to ~117 kHz holding AN4068's own
Q values and its own ratios between corner frequency and band edge; every
resistor keeps its reference value and only the reactive parts move.
[`docs/plc-coupling.md`](../../../docs/plc-coupling.md) has the arithmetic,
the cross-checks, and what the filters still do not do.

Also settled here: the coupling transformer. AN4068 names the part
(**Würth 750510231**), and its specification sheet meets every line of
AN4068's Table 4 except the withstanding-voltage row, where it quotes
2000 VAC for 1 s against Table 4's ≥4 kV — different tests, not necessarily
a conflict, but not something to assume about a galvanic barrier to 230 V.
It carries a custom symbol with the part's real terminal numbers (primary
1–4, secondary 10–7) rather than KiCad's generic 1/2–3/4 transformer, and a
footprint built from the sheet's own recommended land pattern.

What changed in REV 0.2
------------------------

REV 0.1 left three gaps and said they needed power-electronics design
this project's docs didn't specify: no supply for the ST7580's 8–18V
`VCC`, no gate driver for the IRF540N inverter, and no defined inverter
topology. Trying to answer them turned up two problems that made the
questions themselves wrong, both written up in **docs/plc-adapter-power.md**:

1. **The adapter had no power source during an outage at all.** Its only
   supply was the HLK-5M05, which needs 90–264V AC. When the grid fails
   the adapter stops — so it could never have run an inverter, and the
   24V it was supposed to inject could not have powered a neighbouring
   adapter either. The firmware protocol had already been written against
   a battery (`MASTER_ALIVE.battery_pct`) that the BOM never contained.
2. **The 24V injection is outside EN 50065-1.** The A-band limit is
   5 Vrms at 9 kHz falling to 1 Vrms at 95 kHz; 24V is 5–24× over it. The
   ST7580's own PA delivers 14 V p-p — 4.95 Vrms — because ST sized the
   part to land on that limit.

So REV 0.2 does two things. The adapter is now **powered from the
Terminal's battery** over a detachable USB-C cable, with a supercapacitor
covering the moment of grid loss. And the **inverter is gone**, replaced
by a proper 12V rail for the power amplifier that was always going to do
the actual signalling.

Two of the three original gaps were therefore closed rather than deferred.
The third — the coupling transformer and PA output network — waited on one
specific document rather than on open design questions, and REV 0.3 closed
it too.

What this is
------------

A KiCad 9 schematic (`plc-board.kicad_sch`) for the PLC Adapter's main
board: mains input protection, the HLK-5M05 AC-DC supply, the ST7580
power-line-communication modem, an ESP32-C3-MINI-1 as Wi-Fi AP + UART
host, status LEDs, and a programming header. Like the Main Board, it's
generated by Python scripts in `kicad_gen/` (reusing that directory's
`sexp.py`/`make_symbol.py`/`pinmap.py`/`schematic.py` verbatim — they're
generic, not Main-Board-specific) rather than hand-drawn.

No PCB layout exists yet for this board — this pass is schematic only,
same staging Main Board went through (schematic, then a separate
placement pass, then routing).

Board 1 is the PLC Adapter's PCB
----------------------------------

hardware/bom.md lists both "Board 1 — PLC/Power Board" and a separate
"PLC Adapter (Separate Unit)" section, which read as two different things
at a glance. They're not: the top-level README's Hardware Overview
describes only **two** physical products, the Terminal (Board 2 — Main
Board's system) and the PLC Adapter, which talk to each other over Wi-Fi
only — the Terminal has no powerline hardware at all. Board 1's component
list (ST7580, 2x IRF540N, TVS, MOV, relay, PC817, HLK-5M05) matches the
PLC Adapter's own hardware table in the top-level README line for line.
Board 1 *is* the PCB inside the PLC Adapter housing; the BOM's two
sections just cost out the same board from two different angles (bare
PCB + parts vs. the fully assembled product including enclosure, plug,
and LEDs).

Two BOM inconsistencies fell out of confirming this and were fixed in
hardware/bom.md as part of this pass (see that file's "Design Notes — REV
History" item 6 for the full writeup):
- The PLC Adapter's enclosure was spec'd at ~80×80×40mm, too small for
  Board 1's own 100×80mm PCB — a REV 0.4 estimate that never got
  reconciled against the PCB size, unlike the other stale REV 0.4 numbers
  already caught elsewhere in the BOM. Corrected to ~110×90×30mm.
- Board 1's `J1` connector was described as a "main board interface,"
  which read as if it connected to Board 2. It doesn't — Board 1 and
  Board 2 are different products that never connect to each other. `J1`
  is this board's own connector to the Adapter's Schuko-plug wiring and
  status LEDs (not present in the current schematic pass — see below).

What this covers, and what it deliberately doesn't
-----------------------------------------------------

This board builds every part of the circuit that's fully specified by a
primary source — a datasheet section, or an unambiguous line in this
project's own docs — and stops there rather than guessing at the parts
that aren't.

### The power architecture (REV 0.2)

Three sources feed one 5V rail, ORed with Schottky diodes:

```
  mains ──► HLK-5M05 ──┐
                       ├──►┤◄── +5V ──┬──► AMS1117-3.3 ──► +3V3
  Terminal ─► USB-C ───┘              │
                                      └──► MT3608 boost ──► +12V ──► ST7580 VCC
                                 10Ω ─┴─ 1F supercap
```

- **ORing with Schottkys** (`D5`/`D6`) rather than an ideal-diode
  controller, consistent with this BOM's price point. ~0.3V drop leaves
  ~4.7V, above the boost's input minimum and still enough headroom for
  the AMS1117 at the ~100mA it supplies.
- **`J4`, the Terminal inlet**, is a USB-C receptacle strapped as a sink
  (5.1k CC pull-downs), power-only — no USB data on this board. It sits
  on the HLK-5M05's *isolated secondary*. The user handles this cable, so
  the isolation barrier docs/electrical-safety.md calls non-negotiable is
  what stands between them and the mains side.
- **`C7`, the 1F supercapacitor**, charges through `R11` (~500mA inrush
  limit) and discharges through `D7`, keeping the resistor out of the
  discharge path. Its job is not to keep the adapter running — it is to
  keep the ESP32-C3 alive long enough to tell the Terminal over Wi-Fi
  that mains has gone, so the Terminal can put "connect the adapter
  cable" on screen. 6.4J per farad between 5V and the boost's ~3.5V
  minimum; a couple of seconds of Wi-Fi is well under 1J.
- **`U5`, the MT3608 boost**, is a real KiCad library part, not a custom
  symbol. Values from its own datasheet: `VREF` = 0.6V and
  `VOUT = VREF × (1 + R1/R2)`, so 12V needs R1/R2 = 19 — 19.1k/1k gives
  12.06V. 22µH inductor (its recommended 4.7–22µH range), 22µF ceramic in
  and out, plus 100µF bulk on 12V to ride transmit bursts. It's an
  asynchronous boost, so the rectifier `D8` is external.

12V was chosen for `VCC` because it sits mid-window in the datasheet's
8/13/18V range and well clear of the 6.1–7.5V undervoltage lockout.

### Transmit current limit

The ST7580 has a hardware output-current limit set by one resistor. It
mirrors 1/`CL_RATIO` of the PA output current through `RCL` to `VSS` and,
once that voltage passes `CL_TH`, walks `TX_GAIN` down a step at a time
until it's back under (datasheet Section 5.4):

```
RCL = CL_TH × CL_RATIO / I(PA_OUT) peak     CL_TH = 2.35V, CL_RATIO = 80
```

Checked against the datasheet's own Table 8: 1 A RMS FSK is 1.41 A peak →
2.35 × 80 / 1.41 = 133 Ω, exactly the tabulated value.

`R14` = 270R sets a 500 mA RMS ceiling, bounding what the Terminal's
battery has to supply. It's a backstop, not the operating point —
firmware sets `TX_GAIN` lower still on battery. `CL_SEL`, which would
switch `RCL` between FSK and PSK crest factors, is not used; one fixed
resistor means the effective ceiling differs slightly between
modulations, which is fine for a backstop, and it's a digital output so
leaving it open is safe.

What *is* built and ERC-clean:

- Mains input (`J1`) with Layers 1-2 protection: TVS (`D_TVS`,
  P6KE250CA) and MOV (`Varistor`, S20K275) across L/N.
- HLK-5M05 AC-DC supply, isolated 5V output.
- ST7580: every digital, control, clock, and power/ground pin that the
  datasheet fully specifies — UART to the ESP32, JTAG debug header,
  baud-rate selection, reserved-pin handling, the 8MHz crystal (no
  external load caps needed, both `XIN`/`XOUT` have them integrated),
  and the complete power/ground scheme from the datasheet's own Figure 8
  (supply structure) and Figure 9 (ground scheme) — reproduced exactly,
  not approximated.
- ESP32-C3-MINI-1 (on-module PCB antenna, no antenna connector): Wi-Fi AP, UART host
  for the ST7580, a UART0 programming header (without this or a USB
  connector there'd be no way to flash the module at all — an omission
  this pass caught and fixed, not something any existing doc specified).
- Status LEDs: Power (always-on), PLC (driven directly by the ST7580's
  `PL_TX_ON`), Wi-Fi (GPIO-driven, so firmware can blink it for real
  status rather than it being a second always-on LED).
- **The line coupling (REV 0.3)**: the transmit active filter around the
  ST7580's own power amplifier (`R15`/`C12` R-C pre-filter, then a
  Sallen-Key cell on `PA_IN±`/`PA_OUT`), the receive passive filter into
  `RX_IN`, and the coupling itself — DC block, `T1`, the series inductor
  and the X1 safety capacitor into `AC_L`/`AC_N`. Topology from AN4068
  section 7.1, values rescaled from its A-band centre to GRIDNET's B+C
  band. Every number in [`docs/plc-coupling.md`](../../../docs/plc-coupling.md).

Datasheet verification
------------------------

All three custom-built symbols were checked pin-by-pin against
primary-source datasheets before being written into
`kicad_gen/build_library.py`, same
standard as the Main Board's parts:

- **ST7580** — checked against STMicroelectronics' real datasheet
  (DocID022644 Rev 2, obtained via LCSC's CDN after ST's own site and
  several mirrors were unreachable from this environment — see the
  session history for what didn't work). Figure 2 (pinout diagram) and
  Table 2 (pin description) for all 48 pins + exposed pad; Figure 8/9 for
  the power and ground scheme; Section 7 for the crystal spec. This is a
  from-scratch symbol (ST7580 isn't in any KiCad bundled or
  community library found), so every pin was being verified for the
  first time, not checked against a prior (possibly wrong) version like
  the Main Board's parts were.
- **ESP32-C3-MINI-1** — same datasheet and Table 3-1 already used to
  verify the Main Board's ESP32-C3-MINI-1U, since both modules share one
  datasheet and pin table. Pin list is identical to that symbol, full
  stop: Table 3-1's 53 pads are the same for both variants and neither
  has an RF pad. This symbol has no `ANT` pin, and neither does the Main
  Board's any more — the one it used to have was invented, and the pad it
  claimed to name does not exist on either module (see
  ../main-board/README.md's "The antenna path never touched the board").
  The difference between the variants is only where the radio goes: an
  on-module PCB antenna here, an on-module W.FL/MHF III jack on the -1U.
- **Würth 750510231** (the coupling transformer) — terminals and every
  electrical parameter checked against Würth's own specification sheet
  (rev 6E, 8/22). It exists as a custom symbol for one reason: the real
  part's terminals are **1/4** (primary) and **10/7** (secondary), while
  KiCad's `Device:Transformer_1P_1S` numbers its pins 1/2 and 3/4. Using
  the generic symbol would have put a wrong pin number into the netlist
  and shown up, if at all, on the PCB — which is exactly how this project
  has lost two passes already. Its parameters against AN4068 Table 4 are
  tabulated in [`docs/plc-coupling.md`](../../../docs/plc-coupling.md);
  six of seven rows pass outright and the seventh (withstanding voltage)
  is an open question about test methods, not a failure.
- **Footprints**: ST7580 uses a bundled KiCad `QFN-48-1EP_7x7mm_P0.5mm`
  footprint sized to the datasheet's Table 14 exposed-pad dimensions
  (5.1×5.1mm typ., closest bundled option). ESP32-C3-MINI-1 uses the
  real footprint vendored from Espressif's official KiCad library into
  `gridnet_footprints.pretty/` (CC-BY-SA 4.0), same source and process as
  the Main Board's MINI-1U footprint — see that directory's README.md.
  `T1` uses a footprint built for this project from the "recommended P.C.
  pattern" on Würth's own sheet: four ⌀1.20mm holes on a 10.16 × 7.62mm
  rectangle, 14.22mm square body, 13.48mm high.

Real KiCad library parts used as-is (same confidence as any normal KiCad
design, no custom symbol needed): `Device:D_TVS`, `Device:Varistor`,
`Converter_ACDC:HLK-5M05` (exact bundled match for the BOM part),
`Regulator_Linear:AMS1117-3.3`, `Device:FerriteBead`, `Device:Crystal`,
`Device:R`/`C`/`LED`, and generic connectors.

ERC result
----------

```
kicad-cli sch erc plc-board.kicad_sch --format json -o /tmp/erc.json
```

**350 violations, 0 errors.** (This file said 212 until REV 0.3 re-ran it.
That figure predated the REV 0.2 pass which took the board from 29 to 47
components, and nobody re-counted; the categories and the reasoning below
were unchanged by either pass, only the off-grid endpoint count, which
grows by one per new pin.) Same benign categories as the Main Board's ERC
results, for the same reasons (see that board's README for detail):
`endpoint_off_grid` (345, cosmetic), `lib_symbol_issues` (3) and
`footprint_link_issues` (2) (this headless environment doesn't have
`gridnet_parts`/`gridnet_footprints` registered as project libraries;
both load and place correctly regardless).

Two ERC categories that came up during this pass and are worth naming
explicitly, since they're not just cosmetic noise silenced by rote —
each reflects a real judgment call:

- `power_pin_not_driven` on the mains connector's `AC_L`/`AC_N` pins and
  on the ST7580's internally-generated rails (`VDD` x2, `VDD_REG_1V8`,
  `VDD_PLL`, `VCCA`, `VSSA`). Both are legitimately not driven by
  anything *on this board* — mains power comes from the wall, and those
  ST7580 pins are fed by the chip's own internal regulators from `VDDIO`
  (datasheet Section 6: "not designed to supply external circuitry...
  accessible for filtering purposes only"). Each got a `PWR_FLAG`, with
  a comment citing the specific reason, rather than being silently
  wired to something to make the warning go away.
- `pin_not_connected` on the ESP32's `IO2`/`IO3` and (before the
  programming header was added) `U0RXD`/`U0TXD` — real omissions this
  pass caught while building, not intentional simplifications. Fixed
  (see above), not just flagged.

Net plan (high level)
----------------------

- **Mains protection:** `AC_L`/`AC_N` (from `J1`) — TVS and MOV both
  shunt across the pair, not in series with it.
- **Power:** `AC_L`/`AC_N` → HLK-5M05 → `+5V` (isolated secondary,
  becomes this board's logic ground reference) → AMS1117-3.3 → `+3V3`
  for the ESP32.
- **ST7580 UART:** `TXD`/`RXD` ↔ ESP32 `IO4`/`IO5` (a secondary UART on
  spare GPIOs, not the ESP32's own `U0RXD`/`U0TXD`, which are reserved
  for flashing the ESP32 itself via the programming header).
- **ST7580 control:** `RESETN` ↔ ESP32 `IO6`, `T_REQ` ↔ ESP32 `IO7`,
  `BR0`/`BR1` strapped high for 57600 baud (Table 3 of the datasheet).
- **ST7580 power/ground:** exactly Figure 8/9 of the datasheet — see
  "What is built" above.
- **Status LEDs:** Power → `+5V` direct. PLC → ST7580 `PL_TX_ON` direct.
  Wi-Fi → ESP32 `IO8` (active-low sink).

What's not done yet
--------------------

- **A conducted-emission measurement.** The coupling network is built and
  its arithmetic checks out, but harmonic suppression is inherently weaker
  in B+C than in the A band — a 95 kHz carrier puts its second harmonic at
  190 kHz, below the Sallen-Key corner, where the 3-pole network only takes
  off ~2.7 dB. The ST7580's own transmitter linearity (0.1–0.2 % THD,
  −70 dBc typical HD3) is doing most of the work. AN4068 earns its
  compliance claim with a LISN sweep (its section 8.2); GRIDNET needs the
  same before claiming EN 50065-1 conformance. See
  [`docs/plc-coupling.md`](../../../docs/plc-coupling.md).
- **The transformer's withstanding voltage.** Würth quotes 2000 VAC for
  1 s; AN4068 Table 4 asks for ≥4 kV, which comes from EN 50065-4-2's
  impulse test. Probably compatible, not demonstrably so — confirm with
  Würth before fabrication.
- **`ZC_IN` (zero-crossing)** — deliberately not built, not merely absent.
  The datasheet calls it optional, docs/protocol.md defines no
  mains-synchronous behaviour, and during an outage there is no mains to
  synchronise to. AN4068's circuit is recorded in docs/plc-coupling.md if
  it is ever wanted; note that its Figure 14 could not be read, so the
  block cannot be built from that list alone.
- **Routing.** The pipeline runs end to end and gets close — 152 unrouted
  down to 4-8 from the autorouter, with the repair step closing most of what
  is left (`+5V`, `/ST_PA_OUT`, `/AC_N`, `/PLC_LINE`, `/ST_TMS`,
  `/ST_VDD_REG_1V8` across runs) — but no run has produced a complete board.
  Each ends holding one connection.

  Two specific things stand in the way, both in `finish_routing.py` rather
  than in the design:

  - **`drop_via_to_plane()` reports success without checking it helped.** It
    stitched the same point three times in one run: it finds a legal via site,
    returns True, DRC reports the same pair unconnected, and it stitches
    again. It also chose a site 0.1mm from pin 48's pad — same net, so it
    added nothing. It needs to verify the reported connection actually closed,
    and to stitch the endpoint that is a *pad* rather than whichever end comes
    first.
  - **U4 pin 3 (VDDIO, left edge) has no reachable via site.** The pad sits
    directly over solid +5V plane copper — confirmed, the filled polygon
    contains its coordinates — so the connection it needs is a via, not a
    track. There is no legal site within the helper's 6mm search, which is a
    congestion problem on the QFN's left edge, not a search-radius one.

  Everything else the routing pass needed is in place and verified: the DSN
  carries the barrier as a `keepout` on all four layers, the repair router
  respects rule areas, and `check_isolation_barrier()` now runs on copper —
  pads, tracks, vias and filled zone polygons — where it has already caught
  one real defect (stitching vias hanging 0.3mm into the band, because the
  grid started at `SELV_MIN` and a via has a radius).
- ~~The pour sliver past the antenna keepout~~ — closed in REV 0.5. A second
  rule area now covers the strip between `U2`'s antenna keepout and the right
  board edge, on all four layers.
- **The creepage figure itself.** 7.96mm comes from T1's land pattern and
  sits inside the range convention quotes for reinforced insulation at 230V,
  but this project has not read IEC 60950-1 or 62368-1 directly. Every other
  number in this design traces to a datasheet; this one does not yet.
- **The Layer 3 protection circuit** is not deferred any more — it is
  **deleted**. Relay, optocoupler and voltage sensing existed only to
  isolate the inverter from the line, and there is no inverter. Layers
  1–2 (TVS, MOV) remain and are built.
- ~~**Which CENELEC band, in the protocol docs.**~~ Closed. The hardware was
  never undecided — the coupling network is tuned for B+C, 95–140 kHz, and
  changing that means changing four component values — and docs/protocol.md
  now describes that band throughout. What remains is the conducted-emission
  sweep any EN 50065-1 claim depends on, which needs a prototype.
- **`J1`'s replacement**: the BOM's `J1` (Schuko-plug + LED wiring) isn't
  in this schematic pass — the mains connector here (also called `J1` in
  the generated schematic, a coincidental naming collision, not the same
  connector) stands in for wherever the Adapter's own plug wiring
  attaches, and the status LEDs are wired directly to the board's power
  rails rather than through a separate interface connector.

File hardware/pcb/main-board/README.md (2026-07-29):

GRIDNET — Main Board KiCad Schematic
REV 0.8 (matches hardware/bom.md's Board 2 — Main Board bill of materials)

What this is
------------

A KiCad 9 schematic (`main-board.kicad_sch`) for the Main Board, covering
the full circuit from hardware/bom.md's "Board 2" line items: USB-C power
input, Li-ion charge/boost/regulation, the GD32VF103CCT6 MCU with clock/
reset/boot/SWD, SPI flash + SRAM + microSD + RTC, the ESP32-C3-MINI-1U
wireless module, and the off-board connectors for the display, keyboard
controller, keyboard backlight, and speaker. There is no antenna path on
this board and no RF net — see "The antenna path never touched the board".

Alongside it, `main-board.kicad_pcb` has every part placed within the
100x80mm board outline from hardware/bom.md, **fully routed** on 2
layers (F.Cu/B.Cu) with sized power traces, and **poured with ground on
both layers**. `kicad-cli pcb drc` comes back completely clean: 0
violations of any severity, 0 unconnected items.

REV 0.8 continues the pre-fab review with two findings that the REV 0.7
pass created the conditions to see, both about things the board *claimed*
to have and did not:

1. **The antenna path never touched the board.** A phantom U.FL connector
   (`J7`) duplicating one the module already carries, a fictional `/ANT_RF`
   trace to the SMA, and an invented `ANT` symbol pin behind both. All
   three are gone, and with them the RF layout gap that headed "What's not
   done yet". See "The antenna path never touched the board".
2. **The "grid of stitching vias" was one column of nine**, because
   `BOX2I.Inflate()` mutates in place. The pours were tied together only
   down the left edge: the worst-case point on the board was 55mm from the
   nearest GND via. Now 16.8mm. See "The stitching grid was one column of
   nine vias".

REV 0.7 was the pre-fabrication design-review pass over the routed board.
Four things came out of it, in rough order of how badly they would have
bitten:

1. A **reference-designator drift bug** that had silently moved a dozen
   components into each other's board positions — including the 8MHz
   crystal's load capacitors, which ended up 51mm and 34mm away from the
   crystal. See "Reference-designator drift" below.
2. The **IP5306's switching loop spread across the whole board** — the
   boost inductor sat 63mm from the IC. See "The IP5306 switching loop".
3. **Every trace on the board was 0.2mm**, including the boost path
   rated for 2.4A. See "Trace widths".
4. **No ground plane** — every ground connection was an ordinary routed
   trace. See "Ground pours".

A fifth finding is about the tooling rather than the board: Freerouting
reports success while silently dropping connections, so the flow now
verifies with DRC and repairs what is missing. See "Routing".

An earlier revision also regenerated this PCB after it had been routed
against a *wrong* netlist: the datasheet verification pass described
below fixed real pin-numbering bugs in three of the four custom parts,
which changed which schematic pin number carries which signal for the
MCU, the ESP32-C3 module, and the IP5306, so the old copper was not just
stale but actually wrong (see "Datasheet verification results").

Neither file is hand-drawn in the KiCad GUI: both are generated by the
Python scripts in `kicad_gen/` — the schematic places components at grid
coordinates and wires them via net-label stubs (the standard label-based
wiring pattern for busy schematics, rather than long point-to-point wires
across the sheet); the PCB script places real footprints using each
part's actual courtyard geometry (measured via `pcbnew`, not guessed) so
placement is collision-free from the start. `kicad_gen/route.sh` drives
the whole sequence end to end; see "Regenerating / validating" below.

The antenna path never touched the board
-----------------------------------------

"What's not done yet" used to open with RF layout: `/ANT_RF` ran from `U9`
to a U.FL pad (`J7`) and on to the edge-mount SMA (`J8`) at whatever width
Freerouting chose, and wanted a coplanar-waveguide geometry computed for
this stackup. Working out that geometry was the plan for this pass. The
first thing that turns up on opening the board is that **`/ANT_RF` has no
`U9` pad on it at all** — the net is two connectors wired to each other,
and nothing drives it.

The ESP32-C3-MINI-1U does not bring its radio out to a castellated pad.
Datasheet v2.2 Table 3-1 lists all 53 pads: pins 1, 2, 11, 14 and 36–53
are GND, and the rest are `3V3`, `EN` and IO. There is no ANT and no RF
pad anywhere in the list. The radio leaves the module through the antenna
jack **mounted on the module itself** — that is what the "U" in `-1U`
means. So:

- `kicad_gen/build_library.py`'s symbol had a pin whose *number* was the
  string `"ANT"`, matching no pad in the footprint. That is why the
  netlist quietly produced a two-connector net instead of an error: KiCad
  ties schematic pins to footprint pads by pin number, and a pin number
  that matches nothing simply contributes nothing.
- `J7` was a second, board-mounted U.FL duplicating the module's own. The
  schematic comment beside it said as much — "U.FL pad on the
  ESP32-C3-MINI-1U module itself" — but it was placed on the PCB as a real
  footprint at (80, 35.53) anyway.
- The trace from `J7` to `J8` was therefore 19mm of copper (three
  segments, 0.2mm wide) between two connectors and nothing else, which is
  what an RF review would have been asked to impedance-match.

Worse, an edge-mount SMA soldered to the board cannot be reached by a
pigtail in the first place: its centre pin *is* a board pad. hardware/bom.md
line items 13 and 14 described exactly that — an SMA connector plus a
"U.FL-to-SMA pigtail" to connect the module to it — which cannot be
assembled as written.

**And the pigtail was the wrong connector generation.** Datasheet section
10.2 specifies the module's jack as the *third generation* connector,
compatible with Hirose **W.FL**, I-PEX **MHF III** and Amphenol **AMC**,
with a body of 2.05 x 1.7 x 1.40mm (Figure 10-3). U.FL / MHF I is the
first generation and about 2.6mm across. A U.FL plug does not mate with it.
Every mention of "U.FL" in this project's Board 2 documentation was wrong
about the part on the module, independently of everything above.

What the board looks like now: `J7` and `J8` are gone from the schematic,
from `PLACEMENT` in `build_pcb.py` and from the PCB; the `ANT` pin is gone
from the symbol; `/ANT_RF` is gone as a net. The antenna is a cable
assembly and a case feature, not copper — an MHF III/W.FL plug-to-SMA-jack
pigtail from the module's own connector to a bulkhead SMA in the enclosure
wall, with the antenna screwing onto that. hardware/bom.md REV 0.6 carries
all three as Board 2 items 13–15, with the connector and pigtail marked as
enclosure/cable parts rather than parts that get placed on this PCB — and
with the antenna itself, which REV 0.5 never listed at all.

This removes the largest item from "What's not done yet" rather than
solving it: there is no controlled-impedance net on this board, no antenna
keepout to observe (datasheet Figure 3-1 Note A: the keepout zone applies
to the PCB-antenna `-1` variant, "the latter has no antenna keepout zone"),
and no RF corridor for via placement to respect. The antenna requirements
move to the cable and the case: 2.4GHz, 50Ω, and **maximum gain 2.33 dBi**,
which is the gain of the antenna Espressif certified the module with —
exceed it and the module's existing test reports no longer cover the
product (datasheet section 10.2).

The stitching grid was one column of nine vias
------------------------------------------------

"Ground pours" below describes a 5mm grid of stitching vias placed
"wherever one fits clear of every courtyard, pad and trace". Counting them
on the finished board: **nine, all at x = 1.1mm, running down the left edge
from y = 1.1 to y = 41.1**, then stopping. Nothing else on the board.

The cause is one line of `add_stitching_vias`:

```python
if any(bb.Inflate(clear).Contains(pt) for bb in courtyards):
```

`BOX2I.Inflate()` is not a pure function. It grows the box **in place** and
returns *itself*, so every candidate point that reached a given box grew
that box by another 0.6mm before testing it. `any()` short-circuits, so
the boxes early in the list grew fastest, and after a few dozen candidates
the first courtyards it tests cover the entire board and reject everything.
The scan walks x-then-y, which is why the survivors are one partial column
at the start of the walk.

Nothing downstream could catch this. DRC does not know how many vias were
*meant* to be there, and a board with too few stitching vias is
electrically legal — just a two-layer board whose return plane is tied to
its other half only along one edge. The pour that a signal on the right
side of the board returns through had to reach the left edge to change
layers.

The fix inflates each box once, up front, outside the candidate loop:

```python
keepouts = [box for _ref, box in courtyard_boxes(board)]
keepouts += [pad.GetBoundingBox() for fp in board.GetFootprints() for pad in fp.Pads()]
for box in keepouts:
    box.Inflate(clear)
```

| | before | after |
|---|---|---|
| GND vias on the board | 22 | 180 |
| of those, on the stitch grid | 9 | 167 |
| worst-case distance from any board point to a GND via | 55.1mm | 16.8mm |

Verified after the fact, since the whole point is that DRC cannot see it:
no stitching via lands inside any footprint's courtyard, and DRC stays at
0 violations / 0 unconnected with 158 more vias on the board.

The remaining 16.8mm worst case is at (18, 58), under the display and
keyboard-controller headers' courtyards, where the grid legitimately has
nowhere to put one. The usual rule of thumb is to stitch at λ/20 for the
fastest edge present. This board's fastest are the SPI buses and USB
full-speed; a 2ns edge puts the knee at 0.5/t_r = 250MHz, and at
v_p = c/√4.3 = 1.45e8 m/s in FR-4 that is λ = 579mm, so λ/20 = 29mm.
16.8mm is inside that. 55.1mm was not. Tightening `STITCH_PITCH` below
5mm would not improve the worst case, which is set by the headers'
footprints, not by the pitch.

Reference-designator drift
---------------------------

The worst finding of this pass, and the one that explains why the other
placement problems went unnoticed: **the schematic and the PCB disagreed
about which component each reference designator named**, and nothing
checked.

`build_schematic.py` used to auto-number reference designators by the
order in which parts were placed in the file, while `build_pcb.py`'s
`PLACEMENT` dict is keyed by reference designator. Adding the IP5306's
inductor and snubber (commit 615f5d2) inserted one resistor and two
capacitors into the middle of the power tree, which renumbered every
later R and C by +1 — and `PLACEMENT` was left with the old numbering,
plus three new entries (`R14`, `C4`, `C5`) for names that were already
taken. No error, no warning: the board simply built with a dozen parts
in each other's positions.

Measured on the board as committed before this pass:

| Part | What it actually is | Where it was placed | Distance from where it belongs |
|---|---|---|---|
| `C3`, `C4` | the 8MHz crystal's 20pF load caps | by the audio amp, and in open board below the MCU | **51mm** and **34mm** from `Y1` |
| `C1`, `C2` | the IP5306's 22uF snubber and VOUT caps | flanking the crystal | **51mm** and **54mm** from `U2` |
| `R14`, `C5` | the audio PWM filter's R and C | in open board below the MCU | **61mm** and **70mm** from `U10` |
| `R9`, `R11` | BOOT1 pull-down, I2C SDA pull-up | in the RTC and ESP32 clusters | ~30mm from the pins they strap |

Crystal load capacitors 34–51mm from their crystal do not work: the
oscillator sees the trace, not the capacitor. This was a dead board, and
it looked fine.

Fixed on both sides of the door:

- `build_schematic.py` now passes an explicit `ref=` for all 48
  components, and `schematic.py`'s `place()` refuses to place anything
  without one. Refdes is now a declaration, not a side effect of file
  order. (`#PWR`/`#FLG` virtual symbols stay auto-numbered — they never
  reach the netlist's component list.)
- `PLACEMENT` entries carry the component's expected value (`"20pF"`,
  `"IP5306"`, …), and `build_pcb.py` checks every one against the
  netlist before placing anything. If the two files ever disagree again,
  the build stops and names the parts instead of quietly producing a
  wrong board.
- `build_pcb.py` also now fails on any courtyard overlap and on
  `PLACEMENT` entries for parts that are not in the netlist.

The IP5306 switching loop
--------------------------

Independent of the drift above: even under the *intended* refdes
mapping, the inductor commit put `L1`, the RC snubber and the VOUT
decoupling cap in the open band below the MCU (y=62–68mm) rather than
next to the IP5306 at (11.5, 5.8). Its stated reason — that the CR2032
holder's real 27x24mm courtyard fills the power-tree column from y=50
down — is true but solved the wrong problem: the parts did not need to
be in that column, they needed to be next to the IC.

A 1uH boost inductor 63mm from its switching node is not a boost
converter. The `SW` node loop area and its parasitic inductance are set
by exactly that distance, and everything the snubber exists to damp gets
worse with it.

Re-placed tight around `U2`, whose BAT/SW/VOUT pins (6/7/8) are all on
its right-hand side:

- `L1` immediately to its right, ~1mm courtyard gap
- `C5` (VOUT decoupling), `R14` + `C4` (the SW-node snubber) on the row
  just below

`SW1` (the PWR_KEY button) moved out to the MCU column to make room. It
is a momentary switch on a static input, so distance costs it nothing —
which is exactly what made it the right thing to displace.

Trace widths
-------------

Every net on this board was routed at the 0.2mm default, including the
IP5306 boost path — flagged for review when the inductor was added, and
fixed here. Netclasses live in `main-board.kicad_pro`, written by
`build_pcb.py`'s `NETCLASSES` table (KiCad 7+ keeps netclasses in the
project file, not the board), so the widths are in place *before* the
board goes to the autorouter rather than being retrofitted onto finished
copper.

Sizing is IPC-2221's external-layer curve at 1oz copper and a 10°C rise:
0.2mm carries 0.74A, 0.4mm 1.23A, 0.8mm 2.03A.

| Class | Nets | Width | Why |
|---|---|---|---|
| `Power_Batt` | `/VBATT`, `/IP5306_SW` | 0.8mm | The board draws 355mA at 5V (docs/firmware-arch.md REV 0.6), ~545mA battery-side, ~0.7A peak with boost ripple, plus the MCP73831's 450mA charge current on the same net. Sized towards the IP5306's own 2.4A rating instead: 0.8mm carries 2.03A at 10°C and the full 2.4A at roughly 15°C |
| `Power_5V` | `+5V`, `VBUS` | 0.4mm | 355mA system plus the PAM8403's ~500mA peak into 1W/8Ω ≈ 0.9A design maximum |
| (default) | `GND`, `/+3V3_MCU`, `/+3V3_RF`, signals | 0.2mm | see below |

**Why the battery class is not 1.0mm** (the exact 2.4A/10°C width): `U2`
is an SOP-8 whose pads are only 0.60mm across the trace direction. A
1.0mm trace would have to neck down at both ends of the shortest and
most critical segment on the net. At 0.8mm, Freerouting necks to 0.601mm
for the last 1.4mm into the pad and runs full width everywhere else,
which is the right answer.

**Why GND and the 3V3 rails deliberately have no class.** GND's current
is carried by the pours, not the traces. `+3V3_MCU` carries ~150mA and
`+3V3_RF` peaks near 350mA on ESP32-C3 transmit — both well inside
0.2mm's 0.74A. A first cut of the table gave all three 0.4mm "for
margin" and **Freerouting could not route any of them**: `U5` is an
LQFP-48 on a 0.5mm pitch, and a 0.4mm trace leaving a 0.3mm pad there
comes within 0.15mm of the neighbouring pad, under the 0.2mm clearance
rule. The MCU's own GND and 3V3 pins were the failures both times.
Wider is not automatically safer — it has to fit the escape geometry at
both ends.

Ground pours
-------------

The board had no ground plane at all: every ground connection was an
ordinary routed trace. Both copper layers now carry a GND zone inset
0.5mm from the outline (`add_gnd_zones` in `build_pcb.py`), filling
6270mm² on F.Cu and 6727mm² on B.Cu.

- **Solid pad connections, not thermal reliefs.** Thermal spokes were
  tried first and left 11 pads "starved" — fewer than the two spokes
  KiCad requires, because a 0603 pad with a trace already attached has
  no perimeter left for a second one. Solid copper costs some
  hand-soldering convenience on ground pins and buys a lower-impedance
  return everywhere; this board is reflow-assembled, so that is the
  right trade.
- **Island removal on.** Copper that ends up connected to nothing is
  dropped rather than left floating for DRC to report.
- **Zone clearance matches the board rule (0.2mm) rather than exceeding
  it**, so the pour can reach between fine-pitch escape traces instead
  of stopping short and stranding copper.
- **Vias**: the 3x3 array under `U9`'s thermal pad (pin 49), which is
  what Espressif's hardware design guidelines actually ask for, plus a
  5mm grid of stitching vias (`STITCH_PITCH`) wherever one fits clear of
  every courtyard, pad and trace — 167 of them. Earlier revisions of this
  file said "9mm grid", which matched neither the constant nor the board:
  what was actually placed was nine vias in a single column, and only the
  count made that visible. See "The stitching grid was one column of nine
  vias".

Two ordering constraints, both learned the hard way:

- **Thermal vias go in at placement time, before routing.** Given the
  space, Freerouting will run B.Cu traces straight under the module;
  vias added afterwards land on top of them (`/AUDIO_SHDN` and
  `/KBL_DRAIN` were both shorted this way).
- **The pours go in after routing, not before.** Zones present at
  DSN-export time become Specctra planes, and the router then treats GND
  as already connected and lays no GND copper at all — which leaves every
  ground connection depending on the pour reaching that exact pad. On a
  dense two-layer board it does not: routing chops the F.Cu pour into
  islands, and DRC found 16 GND fragments and pads stranded that way.
  Routing GND as ordinary traces first and pouring on top gives
  connectivity the router can guarantee, with the pour's lower impedance
  and thermal path on top of it rather than instead of it.

What the pour does *not* yet include: a deliberate return-path review of
the SPI/I2C buses, and any thermal-relief exception for hand-rework.

Per-part confidence levels
---------------------------

Real, verified KiCad library parts — pin data came directly from KiCad's
own bundled symbol libraries, copied programmatically (not retyped), so
these carry the same confidence as any normal KiCad design:

- `Regulator_Linear:AMS1117-3.3` (both LDO rails)
- `Memory_Flash:W25Q32JVSS`, relabeled `W25Q64JVSSIQ` — the whole W25Qxx
  family shares one SOIC-8 pinout across densities (Winbond datasheet
  convention), so the pin assignment is correct even though the symbol's
  base name doesn't match the BOM part number
- `Timer_RTC:DS3231M`, substituted for the BOM's `DS3231SN` — see
  "Design assumptions" below
- `Battery_Management:MCP73831-2-OT`
- `Amplifier_Audio:PAM8403D`
- `Transistor_FET:2N7002` (extends `BSS138` in KiCad's library; flattened
  into a self-contained copy — see kicad_gen/schematic.py)
- All passives (`Device:R`, `Device:C`, `Device:Crystal`), switches
  (`Switch:SW_Push`), the USB-C receptacle, microSD socket, and generic
  pin-header connectors — all real KiCad library parts

Custom-built symbols — generic rectangle body, pins placed by function
name. All four have now been checked pin-by-pin against their real
manufacturer datasheets (see "Datasheet verification results" below);
three had wrong pin numbers and have been corrected in
`kicad_gen/build_library.py` + `kicad_gen/build_schematic.py`.

| Part | Confidence | Why |
|---|---|---|
| `23LC1024` | Verified | Checked against Microchip's real 23A1024/23LC1024 datasheet (DS20005142C) — all 8 pins were already correct, no changes needed |
| `GD32VF103CCT6` | Verified, was wrong | Checked against GigaDevice's real GD32VF103 datasheet (Rev1.6), Figure 2-4 "GD32VF103Cx LQFP48 pinouts" — **35 of 48 pins (14-48) were numbered wrong** and have been corrected; see below |
| `ESP32-C3-MINI-1U` | Verified, was wrong | Checked against Espressif's real datasheet (v2.2) Table 3-1 — **nearly all pin numbers were wrong** (the symbol had numbered its 19 signal pins 1-19 sequentially; the real module is 53 pins with GND/NC scattered through that range) and have been corrected; the placeholder WROOM-02U footprint has also since been replaced with the real MINI-1U footprint, see "Real ESP32-C3-MINI-1U footprint" below |
| `IP5306` | Verified, was wrong | Checked against Injoinic's real IP5306 datasheet (V1.3) — **all 8 pins were numbered wrong**, `LED3` and `SW` were missing from the symbol entirely, and two `GND` pins were invented that don't exist (the real part's only ground is the exposed PowerPAD); corrected, see below |

Datasheet verification results
-------------------------------

Each part's real pinout was pulled from its primary-source datasheet (not
a summary site) and compared pin-by-pin against what the generated
symbol had. Three of the four were substantially wrong:

- **GD32VF103CCT6.** Pins 1-13 were already correct. From pin 14 on,
  the symbol had inserted `VSS_1`/`VDD_1` two positions early, shifting
  every following pin by +2 (and a second such insertion at pins 37-38
  shifted the rest further) — the net effect: 35 of 48 pins named the
  wrong signal. The *real* pinout, once correctly transcribed, matches
  the well-known STM32F103C8/CB LQFP48 numbering exactly (the mirroring
  claim in the old description was directionally right; the symbol just
  didn't implement it correctly pin-for-pin). Fixed in
  `kicad_gen/build_library.py`.
- **ESP32-C3-MINI-1U.** The module has 53 physical pads (mostly GND and
  NC around the perimeter); the symbol had instead numbered its 19
  functional signal pins sequentially 1-19, which matches almost none of
  them. For example the old symbol's pin 8 ("IO4") is the real module's
  `EN` pin; the old pin 17 ("U0RXD") is a real `NC` pad. Every pin was
  re-numbered against Table 3-1 of Espressif's datasheet. The footprint
  was still the WROOM-02U placeholder at this point — fixed separately,
  see "Real ESP32-C3-MINI-1U footprint" below.
- **IP5306.** All 8 numbered pins were wrong, and the symbol was missing
  two of the part's real pins outright: `LED3` (pin 4) and `SW` (pin 7,
  the DCDC switch node). It had also invented two `GND` pins (old 3 and
  6) that don't exist — the real IP5306 only has one ground reference,
  the exposed PowerPAD, which is now modeled as pin 9. Fixing this
  surfaced a real design gap, not just a labeling one: **no inductor
  existed anywhere in this design**, and without one on `SW` the boost
  path (`BAT` -> `VOUT`) can't function. This has since been fixed — see
  "IP5306 boost inductor" below.
- **23LC1024.** Checked as a control/sanity case — it was already
  correct, all 8 pins matched Microchip's datasheet exactly.

**Regenerating the PCB against this fix.** Done in a follow-up pass: netlist
re-exported, `build_pcb.py` re-run (placement is driven by reference
designator + footprint, so component *positions* didn't move, but every
pad's *net assignment* on the MCU, the ESP32-C3 module, and the IP5306
came from the corrected netlist this time), then re-routed from scratch
— the old copper was routed against the old netlist and couldn't just be
relabeled in place. See "Routing" below for how that pass went.

IP5306 boost inductor
----------------------

Fixed as a follow-up to the pin-numbering bug above. The IP5306
datasheet's own "Typical Application Schematic" (Figure 7) shows the
boost/charge inductor bridging `SW` (pin 7) directly to `BAT` (pin 6) —
**not** to `VOUT` as an earlier read of this design guessed; the
`SW`-`BAT` inductor is shared between the buck charger and the boost
discharger, and `VOUT` (pin 8) is a separate internally-switched output.
Added per that reference circuit:

- **L1, 1uH** (`Inductor_SMD:L_6.3x6.3_H3` — a generic shielded power
  inductor footprint, not a specific vendor part; the datasheet doesn't
  specify one either) between `SW` and `BAT`/`/VBATT`.
- **R14 (0.5R) + C4 (22uF) in series**, from the `SW`/`L1` junction to
  GND — the datasheet's `R4`/`C2`, a small RC snubber damping switching
  ringing on the `SW` node. This carries only transient ringing current,
  not the inductor's main current, so a standard 0603/0805 pair is fine
  even though the inductor itself is a boost-converter-current part.
- **C5, 22uF** at `VOUT`/`+5V`, directly at the IC — the datasheet's
  figure uses a 4x22uF bank there; simplified to one cap here, the same
  simplification style already used for the mono audio path elsewhere in
  this design.

All three were new components when the inductor was added, and were
first placed in the open board area below the MCU cluster rather than in
the power-tree column, on the grounds that the CR2032 holder's courtyard
fills that column from y=50 down. That reasoning is what "The IP5306
switching loop" above unpicks: it put a boost converter's switching loop
63mm across the board. They now sit tight around `U2` — see that section
for the current positions.

Real ESP32-C3-MINI-1U footprint
--------------------------------

Fixed as a follow-up to the datasheet verification pass above, which
fixed the schematic symbol's pin *numbers* but left the PCB footprint as
the same-family `RF_Module:ESP32-C3-WROOM-02U` placeholder (a different,
smaller module standing in for placement purposes only — see the old
confidence table entry). Replaced with the real thing rather than
hand-transcribing dimensions off the datasheet's land-pattern drawing
(error-prone for a 53-pad castellated footprint, and exactly the kind of
mistake this whole verification pass exists to catch): Espressif
publishes an official KiCad library at
[espressif/kicad-libraries](https://github.com/espressif/kicad-libraries)
(CC-BY-SA 4.0, the same license terms as KiCad's own official libraries),
and its `ESP32-C3-MINI-1U.kicad_mod` is vendored unmodified into
`gridnet_footprints.pretty/` — see that directory's README.md for exact
provenance. `kicad_gen/build_pcb.py` gained a small `LOCAL_FOOTPRINT_LIBS`
lookup so it can load project-local footprints alongside the ones it
already pulls from KiCad's bundled libraries.

Verified before use (not just trusted because it's "official"): 53
distinct pad numbers, with pad 49 (`GND`) present as the expected 3x3
array of thermal-pad via pads under the module — matches Table 3-1 of
the datasheet the pin list was checked against.

**Effect on the board.** The real footprint's own hole spec resolved the
`drill_out_of_range` warnings that showed up in every DRC run so far in
this document (they were the WROOM-02U placeholder's own 0.2mm holes
against KiCad's 0.3mm minimum rule — never a placement or routing
problem, but real DRC errors regardless). Regenerating placement +
routing against it: **0 DRC violations, 0 unconnected items** — the
first fully clean `kicad-cli pcb drc` run this board has had.

**Update: the remaining GND pads are now grounded** (fixed as a
follow-up to the finding above). The custom symbol only drew 2 of the
module's real ~22 `GND` pin numbers (30 physical pads once the pin-49
thermal array's 9 copper islands are counted individually); Espressif's
hardware design guidelines for this module recommend tying all of them
to the ground plane for RF and thermal performance. `kicad_gen/build_library.py`'s
`ESP32-C3-MINI-1U` symbol now draws every real `GND` pin from Table 3-1
(`1, 2, 11, 14, 36-53`, pin 49 being the 3x3 thermal-pad array —
wiring that one symbol pin to `GND` grounds all 9 physical pads, since
they share the pad number in the footprint), all wired to `GND` in
`build_schematic.py`. Only the module's 14 genuinely `NC` pads
(`4, 7, 9, 10, 15, 17, 24, 25, 28, 29, 32-35`) are still undrawn — there's
nothing to connect them to.

Regenerated schematic (ERC clean) and PCB against this: **0 DRC
violations, 0 unconnected items**, all 30 of `U9`'s `GND` pads confirmed
on the `GND` net.

At the time that left the module's pads electrically grounded through
ordinary routed traces, which satisfies connectivity but not the
thermal-performance intent of Espressif's guidance. REV 0.7 finished the
job: both layers now carry a GND pour and the thermal pad has its 3x3
via array down to it — see "Ground pours" above.

Design assumptions (things this schematic decided that the BOM/docs didn't
spell out)
------------------------------------------------------------------------

- **DS3231M substituted for the BOM's DS3231SN.** Same SCL/SDA/VBAT/
  32KHZ/INT-SQW functionality; DS3231M is the version KiCad ships a real,
  verified symbol for. If REV 0.6 of the BOM should specifically source a
  DS3231SN, the footprint/ordering part number differs but the schematic
  pinout is unaffected (compatible pin function set).
- **USB D+/D- routed to the ESP32-C3's native USB (IO18/IO19), not the
  MCU.** The GD32VF103 has no native USB peripheral, so DFU-over-USB (per
  docs/firmware-arch.md) has to come through the ESP32-C3 module instead.
  This is a design assumption, not a documented requirement — confirm it
  matches the intended firmware update path before relying on it.
- **IP5306 VIN left unconnected; MCP73831 handles charging instead.**
  IP5306 is a combined boost + charge-management IC, but this design uses
  it only for its 5V boost path (BAT -> VOUT) and handles Li-ion charging
  separately with a dedicated MCP73831. IP5306's own charge-input pin
  (VIN) is marked `no_connect` rather than wired to VBUS, to avoid two
  charge controllers fighting over the same battery. The boost path
  itself runs through `L1`, a 1uH inductor on `SW` shared with the
  charger — see "IP5306 boost inductor" above.
- **Mono audio.** PAM8403D is a stereo amplifier, but hardware/bom.md
  specs one 1W/8Ω speaker. INL, INR, and VREF are all tied to the same
  filtered PWM node, and only the left channel output (LOUT+/LOUT-) is
  wired to the speaker connector; the right channel is `no_connect`.
- **CC1/CC2 strapped 5.1k to GND.** Fixed "UFP sink" strapping so any
  USB-C charger or host offers 5V — this board doesn't negotiate USB-PD.
- **BOOT0 has both a pull-down (default: boot from Flash) and a 2-pin
  override jumper** to force it high for factory/recovery reflashing
  without needing a bodge wire.

Net plan (high level)
----------------------

- **Power:** VBUS (from USB-C) -> MCP73831 -> VBATT (battery) -> IP5306
  boost -> +5V -> two AMS1117-3.3 rails: +3V3_MCU (MCU + all digital
  logic) and +3V3_RF (ESP32-C3 module, kept separate for RF supply
  cleanliness).
- **MCU (GD32VF103CCT6):** 8MHz crystal on OSC_IN/OSC_OUT, NRST with pull-up
  + reset button, BOOT0 pull-down + override jumper, BOOT1 pull-down, SWD
  header (SWDIO/SWCLK/+3V3_MCU/GND).
- **SPI1** (SCK/MISO/MOSI shared bus): W25Q64JVSSIQ flash (FLASH_CS),
  23LC1024 SRAM (SRAM_CS), microSD (SD_CS).
- **I2C1:** DS3231M RTC (SCL/SDA, 4.7k pull-ups each), with its own CR2032
  holder on VBAT_RTC (externally-sourced net, PWR_FLAG'd — see below).
- **USART1:** MCU <-> ESP32-C3-MINI-1U (cross-connected TX/RX).
- **SPI2:** MCU <-> RA8875 display module header (SCK/MISO/MOSI/CS/RESET/
  INT).
- **USART2:** MCU <-> CH552G keyboard-controller header.
- **PWM outputs:** KBD_BACKLIGHT_PWM (via 2N7002 low-side switch, drives
  external LED array) and AUDIO_PWM (via an RC filter into PAM8403D's
  audio input).
- Every otherwise-unused MCU/ESP32/RTC/microSD/amplifier pin is explicitly
  marked `no_connect` (not left dangling) — see the bottom of
  `kicad_gen/build_schematic.py` for the full list and why each one is
  unused.

Regenerating / validating
--------------------------

The schematic and its project-local symbol library are both generated,
not hand-edited. To rebuild from scratch:

```
cd hardware/pcb/main-board/kicad_gen
python3 build_library.py     # writes ../gridnet_parts.kicad_sym
python3 build_schematic.py   # writes ../main-board.kicad_sch
```

To validate (from `hardware/pcb/main-board/`):

```
kicad-cli sch erc main-board.kicad_sch --format json -o /tmp/erc.json
kicad-cli sch export svg main-board.kicad_sch -o /tmp/render/
```

Current ERC result (after the datasheet-verification pin fixes, the
IP5306 inductor addition, the real ESP32-C3-MINI-1U footprint, and
grounding its remaining GND pads above, and removing the antenna
connectors): **368 violations, 0 errors.**
All remaining warnings are benign / expected in a headless-generated
schematic without a full project sym-lib-table registered:

- `endpoint_off_grid` (353) — cosmetic, wire/pin endpoints not snapped to
  KiCad's visual grid
- `lib_symbol_issues` (10) — artifact of validating without this
  environment's full symbol-library table registered
- `pin_to_pin` (4) — intentional: each SPI flash/SRAM's `~WP`/`~HOLD` pins
  are tied directly to its own VCC pin (both real, both correct — not a
  wiring bug)
- `footprint_link_issues` (1) — same cause as `lib_symbol_issues`: this
  headless environment doesn't have `gridnet_footprints` registered as a
  project footprint library, so ERC can't confirm the link; the footprint
  itself loads and places fine (see "Real ESP32-C3-MINI-1U footprint"
  above and the DRC result below)

The PCB is a five-stage pipeline, all of it driven by
`kicad_gen/route.sh`:

```
cd hardware/pcb/main-board/kicad_gen
FREEROUTING_JAR=/path/to/freerouting.jar JAVA=/path/to/java-25 ./route.sh
```

which runs, in this order and for the reasons given in "Ground pours"
and "Routing":

1. `build_library.py` + `build_schematic.py` — symbols and schematic
2. `kicad-cli sch export netlist` — the netlist `build_pcb.py` reads
3. `build_pcb.py` — placement, `U9`'s thermal vias, and the netclasses
   written into `main-board.kicad_pro`
4. Specctra DSN out → Freerouting → SES back in, then
   `finish_routing.py` to verify and repair
5. `build_pcb.py --pour` — GND zones, stitching vias, fill

then runs DRC and fails if anything is an error or unconnected. If the
repair step cannot close a gap it throws that routing away and runs
Freerouting again (up to `ATTEMPTS`, default 3) rather than leaving a
hand-patched board that the next regeneration would lose.

Any stage can also be run on its own; they are ordinary scripts.

Current DRC result (routed and poured board): **0 violations, 0
unconnected items** — clean at every severity, including the
`drill_out_of_range` warnings that dogged earlier revisions (those
traced to the WROOM-02U placeholder footprint's 0.2mm holes and went
away with the real footprint). 46 footprints, 86 nets, 806 tracks, 239
vias, both GND pours filled (F.Cu 6385mm², B.Cu 6955mm²).

REV 0.8's board is the REV 0.7 board minus `J7`, `J8` and the three
`/ANT_RF` tracks, plus 158 stitching vias and a refill. That was done as
a subtractive edit rather than a full `route.sh` run: nothing about the
change asks the router to solve anything, and re-autorouting would have
reshuffled all 806 tracks and — per "Routing" below — not deterministically.
`build_schematic.py`, `build_library.py` and `build_pcb.py` were updated
first, so a full regeneration produces the same board content.

Routing
-------

`main-board.kicad_pcb`'s copper (F.Cu/B.Cu) was routed by
[Freerouting](https://www.freerouting.app/) v2.2.4 (the standard
open-source autorouter for KiCad, run via its CLI in headless mode — no
GUI, no manual click-routing) rather than by hand or left unrouted. This
environment ships neither Freerouting nor a Java runtime new enough to
run it, so both were fetched for this pass: Freerouting's jar from its
GitHub releases, and a Temurin JDK 25 (Freerouting 2.2.4 requires
class-file version 69, i.e. Java 25 — the environment's stock JRE was
Java 21).

The exchange is the standard KiCad-\<->Freerouting workflow, all via the
`pcbnew` Python API (no GUI needed for either direction):

```
python3 -c "
import pcbnew
board = pcbnew.LoadBoard('main-board.kicad_pcb')
pcbnew.ExportSpecctraDSN(board, 'main-board.dsn')
"
java -jar freerouting.jar -de main-board.dsn -do main-board.ses \
    --gui.enabled=false -mp 10
python3 -c "
import pcbnew
board = pcbnew.LoadBoard('main-board.kicad_pcb')
pcbnew.ImportSpecctraSES(board, 'main-board.ses')
board.Save('main-board.kicad_pcb')
"
```

**Freerouting reports success while dropping connections.** This is the
tooling finding of REV 0.7, and it invalidates how earlier revisions of
this document read its output. Across a dozen runs on this board:

- It printed "Auto-router session completed … 0 unrouted" and returned a
  session file with `/USART2_RX` **entirely absent** — no wire for the
  net at all.
- It routed one of `J1`'s two D- pads and not the other, and called the
  net finished. `J1` is a reversible USB-C receptacle, so D+ and D- each
  land on two pads with the *other* signal's pad physically between them
  on a 0.5mm pitch; whichever pair gets routed first takes the corridor.
- Which connections it drops **varies between identical runs**. Two runs
  on the same input dropped different nets.

The response is `kicad_gen/finish_routing.py`: after importing the
session, ask KiCad's DRC what is actually unconnected and route it.
Repair is a deterministic grid maze router (A* on a 0.05mm grid, both
copper layers, Manhattan heuristic, vias costed at 12 cells so it does
not stitch gratuitously), with rip-up-and-reroute as a fallback for
connections that cannot be finished around what the autorouter already
committed to. Anything it cannot close makes `route.sh` throw that
routing away and run the autorouter again.

The repair step earns its keep — in successive runs of this pass it
closed `/USB_DN`'s stranded pad, `/BOOT0`, `/SRAM_CS` and `/USART2_RX`,
none of which the autorouter admitted to leaving open.

Things that were tried and do not work, recorded so they are not tried
again:

- **Pre-routing the awkward connections so Freerouting has to work
  around them.** Reasonable in principle and standard practice by hand;
  in practice Freerouting v2.2.4 either hangs for over nine minutes or
  dies with a `NullPointerException` in its own
  `PolylineTrace.normalize`, reliably, whenever the pre-existing wiring
  lands on `J1`'s 0.5mm-pitch pads. Repair after the fact is the only
  order that works.
- **Re-running the autorouter on the partly-routed board** to let it
  finish what it missed. It reports the missing connections as unrouted
  and still cannot place them: by then `U5` pad 40 sits in a 2 x 5.6mm
  pocket of F.Cu with no via site anywhere in it. It routed itself into
  a corner and then said it was done.

Two details of the repair router worth keeping, because both were bugs
first:

- The grid is 0.05mm, not 0.1mm. `J1`'s pad rows sit on a 0.5mm pitch
  with centres at x.x5 coordinates, so a 0.1mm grid cannot land on a pad
  centre at all — and the escape lane between two neighbouring pads is
  exactly 0.45mm, exactly the clearance a 0.2mm trace needs. Half a grid
  cell of rounding closes it.
- Pads are modelled as rectangles. An earlier version used a stadium
  (a segment grown by the pad's short half-dimension), which tucks
  inside a rectangle's corners: a via placed diagonally off a 0603 pad
  passed the check and then failed DRC by 0.03mm.

**A note on trusting the previous `/USB_DN` write-up.** Earlier
revisions of this file described finishing `/USB_DN` by hand with three
F.Cu segments jogging east around the connector, and concluded the west
corridor was full. That analysis was sound for the placement it was
made against, but the placement has since changed — see "USB-C fan-out"
below.

**USB-C fan-out.** `R1` and `R2` (the CC pull-downs) used to sit at
y=30.6, directly east of `J1` between the D+ and D- pad rows, and
`/CC1`'s diagonal run to `R1` closed the only gap the D- pair had to
cross in. They now sit above and below the fan-out band — `R2` at y=27
near its own pad at 28.85, `R1` at y=34 near its own pad at 31.85 —
which is where they belonged anyway.

**Why `/DISP_CS` routed fine this time.** The earlier investigation
(previous PCB revision, see git history for the full writeup) spent
considerable effort diagnosing why `/DISP_CS` wouldn't route, and
concluded the real blocker was `/+3V3_MCU`'s routing elsewhere on the
board. That diagnosis turned out to be moot: the datasheet verification
pass found the MCU symbol's pin 27 was mislabeled `PB12` (the schematic's
`/DISP_CS`) when the real MCU's pin 27 is `PB14` — `PB12` is actually
pin 25. So that entire investigation was against a net that was never
really `/DISP_CS` to begin with; it was whatever the old, wrong netlist
happened to assign to pad 27. On the corrected netlist, the *real*
`/DISP_CS` (pad 25) sits in a different, apparently less congested
neighborhood and Freerouting completed it without issue.

PCB placement notes
--------------------

- **Footprint sizes, not guesses.** Every part's real courtyard geometry
  was measured via `pcbnew` (`build_pcb.py`'s courtyard-center correction,
  and the shelf-packing math behind the `PLACEMENT` dict in that file)
  before any coordinates were chosen. The first hand-placed attempt at
  laying this board out — done *before* checking real footprint sizes —
  produced 7 courtyard overlaps and several pad-to-pad net-shorting
  violations, most notably because the CR2032 holder's real footprint is
  27x24mm (not the few-mm size its schematic symbol suggests). Measure
  first, place second.
- **Footprint anchors aren't always courtyard centers.** Pin headers are
  anchored at pin 1, not the row's midpoint; the SMA edge-mount connector
  (`J8`, since removed — see "The antenna path never touched the board")
  had its body anchored well off to one side of its mounting pin.
  `build_pcb.py` places every footprint once, measures where its courtyard
  actually landed, and corrects the anchor so `PLACEMENT`'s coordinates
  consistently mean "courtyard center" regardless of the footprint's own
  quirks — a real, repeatable bug (not just a cosmetic one) found and
  fixed while placing the two on-board header rows.
- **`no matching net` is expected for `J5` and `J1`.** Each has a few
  real footprint pads (shield tabs, mechanical/detect pins) with no
  counterpart in the schematic's simpler symbol — harmless. `U9` (the
  ESP32-C3-MINI-1U) used to be in this list too, for 34 unmatched pads;
  now that every real `GND` pin is drawn and wired (see "Real
  ESP32-C3-MINI-1U footprint" above), only its 14 genuinely `NC` pads
  are unmatched, which is correct — there's nothing to wire them to.

What's not done yet
--------------------

REV 0.8 closed the item that used to head this list — RF layout around
the antenna path — by establishing that there is no RF net on this board
to lay out, and re-stitching the pours that REV 0.7 only appeared to
stitch. REV 0.7 before it closed trace widths on the boost path and the
ground pour itself. What is left:

- **Return-path continuity for the SPI/I2C buses.** The pours give every
  signal a return plane, but nothing has checked that a bus does not
  cross a slot in the pour where its return current would have to detour.
- ~~A stackup decision~~ — closed. It is now `STACKUP` in `build_pcb.py`,
  written into the board's own design rules rather than into prose: 1.6mm
  FR-4, two layers, 1oz copper, 0.2mm minimum track and clearance, 0.6mm
  vias on 0.3mm drills, 0.15mm annular ring, 0.25mm hole-to-hole.

  Writing it down turned up something worse than an undocumented
  assumption. **KiCad's minimums were left at their defaults, which are
  zero.** `m_TrackMinWidth` and `m_MinClearance` both read back as 0.0mm on
  the finished, DRC-clean board — so every "0 violations" this project has
  reported was measured against no process limit at all. A 0.05mm trace, a
  via with no annular ring, two holes touching: all would have passed.

  The values above are what the board already uses, promoted from
  convention to rule, so DRC now catches anything that drifts *below* what
  the design was drawn to. The routed board passes them unchanged: 0
  violations, 0 unconnected, same as before. That is the point — the rules
  describe this board, they do not reshape it.

  Still open, and a different question: whether these minimums suit the
  manufacturer actually chosen. They are this design's own floor, not a
  claim about anyone's process.
- **A human eye on the autorouted result before fab.** DRC-clean and
  netclass-correct is not the same as well laid out. The specific things
  a review should look at: the density of the escape fan under `U5`, and
  the 16.8mm stitching hole under the top-edge headers.
- A second schematic sheet (and PCB) for the PLC/Power Board and PLC
  Adapter (see hardware/bom.md's Board 1 and "PLC Adapter" sections) — out
  of scope for this pass, which covers Board 2 (Main Board) only.

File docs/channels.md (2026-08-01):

# GRIDNET — The Two Channels

**REV 0.1**

[`protocol.md`](protocol.md) ranks the channels: powerline first, Wi-Fi mesh
second, the mesh used when "line damaged or PLC failed". The README frames
the mesh the same way — a fallback.

That framing is wrong, and [`routing.md`](routing.md) is what exposed it. If
PLC stops at the distribution transformer, the mesh is not a backup for the
powerline; it is the only thing that joins anything the powerline cannot.

This document works out what each channel actually reaches, and what the
routing layer should do with two interfaces instead of a ranked pair.

Nothing here is implemented.

## Wi-Fi is doing two unrelated jobs

The README's diagram runs them together:

```
Normal mode:  [Terminal] ←WiFi→ [PLC Adapter] ←powerline→ [neighbor's adapter] ←WiFi→ [neighbor's Terminal]
```

Both arrows say "WiFi" and they are not the same thing.

**W1 — the tether.** A Terminal reaching its *own* Adapter. The Adapter is
an access point; the Terminal associates with it. This is a private
point-to-point link to the node's own modem, conceptually a cable that
happens to be radio. It carries no one else's traffic and it is not a
network interface for routing purposes.

**W2 — the mesh.** A node reaching *other people's* nodes over ESP-NOW.
This is a genuine second routing interface, and it is the one the README
calls a fallback.

Conflating them is why the mesh reads as an emergency measure. W1 is
always in use, so "Wi-Fi" looks like it is already accounted for.

## What each channel actually reaches

**PLC reaches electrical neighbours. The mesh reaches physical neighbours.
These are not the same set, and neither contains the other.**

That is the whole point, and it is why one cannot be a fallback for the
other.

### PLC's boundaries

| Boundary | Effect |
|---|---|
| **MV/LV distribution transformer** | CENELEC-band signals are attenuated heavily crossing it. Treat a segment as isolated; this design fits no transformer coupler. |
| **Phase** | LV distribution is three-phase and households sit on one of L1/L2/L3. This Adapter couples L-to-N through a Schuko plug, so it transmits on one phase. Cross-phase coupling exists — through the transformer and through connected loads — but with substantial additional attenuation, commonly cited in the 20–40 dB range and highly variable. |

The second one matters more than the first for the use case this project
describes. A transformer district in a European city typically covers a
street or several buildings, so "my neighbourhood" is often within one
segment. But **within a single building, the three phases can partition the
network into up to three groups that barely hear each other** — and the
flats in those groups are interleaved, not separated.

### The mesh's boundary

Physical distance and walls. ESP32-C3 at 2.4 GHz with a ≤2.33 dBi antenna
reaches adjacent and vertically-stacked flats; it does not reach the far end
of a street.

### Why they compose well

The most common way PLC connectivity fails inside a building is **the
neighbour is on another phase** — and that is exactly the case where
physical adjacency holds and the mesh works. The mesh's reach is not a
weaker version of PLC's; it is orthogonal to it, and it covers PLC's
most likely gap.

## The energy argument points the same way

During a grid outage the Adapter runs from the Terminal's battery, so both
channels draw from the same 24.8 Wh. Using [`plc-adapter-power.md`](plc-adapter-power.md)'s
own figures:

| | Power | Rate | Marginal energy per bit |
|---|---|---|---|
| PLC transmit, battery, reduced `TX_GAIN` | 2.7 W (0.5 W idle → 2.2 W marginal) | 2.4 kbps | ~0.92 mJ/bit |
| ESP32-C3 with traffic | ~0.4 W, **already being spent** | ESP-NOW, unmeasured | ≲0.004 mJ/bit |

Two to three orders of magnitude, and robust to pessimistic assumptions —
even charging the mesh its full 0.4 W and assuming only 100 kbps effective
throughput, it still comes out over 200× cheaper per bit.

The reason is that **the radio is already on**. W1 keeps the Adapter's
ESP32-C3 up as an access point at ~400 mW whether or not anyone meshes over
it, and that 400 mW is already the dominant term in the Adapter's 0.5 W
idle draw. Peering with neighbouring Adapters on the same radio adds
almost nothing.

So in an outage — the scenario this project exists for — the channel the
current design treats as an emergency fallback is the cheaper one to use,
and the expensive one is the default.

## Decisions

### C1 — The mesh belongs to the Adapter, not the Terminal

Both units have an ESP32-C3. The mesh should run on the Adapter's:

- **Its position is fixed and known.** It is in a wall socket. The Terminal is carried around, closed, and switched off.
- **Its radio is already an AP and already powered** for W1.
- **It is present when the Terminal is not**, which matters for a network whose store-and-forward relays traffic for seven days.

The Terminal reaches the mesh through its own Adapter over W1 either way, so
this costs the Terminal nothing.

### C2 — All Adapters use one fixed Wi-Fi channel

ESP-NOW peers must sit on the same Wi-Fi channel, and a device acting as an
AP has its channel fixed by that role. If every Adapter picks its own
channel, W1 and W2 cannot both work: two Adapters serving their Terminals on
channels 6 and 11 cannot peer with each other.

So the Adapter's AP channel is a network-wide constant, not a per-device
choice.

The cost is real and should be stated: in a dense building every GRIDNET
Adapter contends on one 2.4 GHz channel, alongside whatever else is there.
GRIDNET's own traffic is kilobits, so this is tolerable, but it is a
deliberate trade rather than a free choice.

### C3 — Two interfaces, one router — not a priority list

This replaces `protocol.md`'s Automatic Channel Selection table.

A node has two routing interfaces, `PLC` and `MESH`. Neighbours are
discovered independently on each — passively, per [`routing.md`](routing.md)
— and a neighbour may appear on one, the other, or both. Destination
selection is per destination, by metric. There is no global ranking, and no
"the wire is damaged" state to detect: a PLC path that stops working simply
stops being advertised, and the mesh path wins on its own.

This is also what makes [`routing.md`](routing.md)'s per-interface split
horizon meaningful — there are now genuinely two interfaces for it to apply
to.
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

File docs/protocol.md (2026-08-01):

# GRIDNET — Communication Protocol Stack

## Overview

GRIDNET uses a custom lightweight protocol designed for low-bandwidth, high-latency powerline communication. Every device is both a node and a repeater.

## Physical Layer

| Parameter | Value |
|---|---|
| Technology | PLC (Powerline Communication) |
| Chip | ST7580 (STMicroelectronics) |
| Standard | CENELEC EN50065, bands B+C (A-band is utility-only, see [`electrical-safety.md`](electrical-safety.md)) |
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

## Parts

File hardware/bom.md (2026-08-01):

# GRIDNET — Bill of Materials (BOM)

**REV 0.10 — Prototype (Single Unit, Retail Pricing)**
*(revision ten, following 0.9 — not 0.1)*

> **REV 0.10 note:** `J1` is no longer an estimate. It is Würth 691311400102,
> the part the PCB footprint has been using all along
> (`TerminalBlock_Wuerth_691311400102_P7.62mm`) — WR-TBL 3114, 2-pole, 7.62mm,
> 300V / 20A (UL), $0.42 at single quantity.
>
> Pricing it surfaced a gap the estimate had been covering: **it is a
> pluggable header, and the plug that mates with it was never in the BOM.**
> Würth 691351400002, $1.25. Without it the board can be fabricated and
> populated with no way to attach the Schuko plug's L/N wires. `J1` therefore
> goes from an estimated $0.70 to a real $1.67 across two line items, and the
> total from ~$149.25 to **~$150.22**.
>
> The one-piece alternative was considered and declined for now — see the note
> under the Board 1 table.
>
> **REV 0.9 note:** this file described a system with three PCBs and two PLC
> modems. It has one of each. Board 1's schematic
> ([`pcb/plc-board/plc-board.kicad_sch`](pcb/plc-board/plc-board.kicad_sch)) carries the ESP32-C3, the
> status LEDs, the mains input and the USB-C outage inlet, which means Board 1
> *is* the PLC Adapter — but a separate "PLC Adapter (Separate Unit)" section
> billed the ST7580, the HLK-5M05, the protection layers and the outage power
> path a second time, and the PCB table ordered a 70×60mm "Adapter Board" that
> was never designed. Both are removed.
>
> Checking the other direction found the mirror-image error: five things in
> that schematic had never been costed anywhere — the ESP32-C3-MINI-1 (`U2`),
> the AMS1117-3.3 that feeds it (`U3`), the 8MHz crystal (`Y1`), the three
> status LEDs (`D2`–`D4`), and the ESP32/ST7580 programming headers (`J2`,
> `J3`). `J1` was also still costed as a 2×8 2.54mm header after DRC forced it
> to a 7.62mm mains terminal block.
>
> Board 1's line items are now keyed to the schematic's reference designators
> so the two can be checked against each other directly. Total moves from
> ~$166.65 to **~$149.25**.
>
> **REV 0.5 note:** several REV 0.4 part choices didn't hold up under review —
> either a real spec mismatch (a display resolution the driver IC can't
> produce) or a part variant that doesn't support a feature the board design
> assumes (an antenna connector with nothing behind it). See "Design Notes —
> REV History" at the bottom of this file for what changed and why.
>
> **REV 0.6 note:** the antenna chain REV 0.5 added to fix that last item was
> itself unbuildable — the wrong connector generation, a connector style that
> cannot be reached by a cable, and no antenna at all. Board 2 items 13-15
> and the totals are corrected here.
>
> **REV 0.7 note:** AN4068 was finally obtained, so Board 1's line coupling is no
> longer a placeholder. The coupling transformer has a real part number, and
> the rest of the coupling network is costed as items 11-13. Note that its
> values are not AN4068's — that reference design is an A-band node and this
> one is not; see [`docs/plc-coupling.md`](../docs/plc-coupling.md).
>
> **REV 0.8 note:** Board 1 is a four-layer board. Not for signal density — it
> could very nearly be routed on two — but because the ST7580's nine +5V pads
> on a 48-pin 0.5mm-pitch package need a plane, and on two layers both copper
> layers are spoken for by ground and the mains barrier. See
> [`hardware/pcb/plc-board/README.md`](pcb/plc-board/README.md) for the four two-layer routing runs that
> established this. The PCB line below moves from 2 to 4 layers accordingly.

## Board 1 — PLC / Power Board (100×80mm)

**This board *is* the PLC Adapter's electronics.** Everything the Adapter does
electrically happens here: mains input and protection, the AC-DC supply, the
ST7580 modem and its line coupling, the ESP32-C3 that serves the Terminal's
Wi-Fi link, the outage power path, and the status LEDs. The Adapter's only
other parts are mechanical — see "PLC Adapter — Non-PCB Parts" below. The two
products in this project are the Terminal (Board 2 + display + keyboard +
battery + clamshell) and the Adapter (this board + plug + enclosure); they
never connect to each other electrically.

Reference designators below are the ones in
[`hardware/pcb/plc-board/plc-board.kicad_sch`](pcb/plc-board/plc-board.kicad_sch), so this table can be
checked against the schematic directly.

| # | Component | Part Number | Description | Qty | Unit Cost (USD) | Total |
|---|---|---|---|---|---|---|
| 1 | PLC SoC | ST7580 | `U4` — CENELEC EN50065, OFDM/FSK, 9–148kHz | 1 | $5.70 | $5.70 |
| 2 | Wi-Fi module | ESP32-C3-MINI-1 | `U2` — Wi-Fi AP for the Terminal's link, and UART host for the ST7580. Plain MINI-1, not the "U" variant Board 2 uses: this board has no external antenna, so the on-module PCB antenna is the right choice | 1 | $0.80 | $0.80 |
| 3 | TVS Diode | P6KE250CA | `D1` — bidirectional, 250V — surge protection (Layer 1) | 1 | $0.60 | $0.60 |
| 4 | MOV | S20K275 | `RV1` — 275V varistor — overvoltage protection (Layer 2) | 1 | $0.40 | $0.40 |
| 5 | SMPS Module | HLK-5M05 | `U1` — 230VAC → 5VDC, 1A, isolated | 1 | $3.50 | $3.50 |
| 6 | Boost converter | MT3608 | `U5` — 5V → 12V for the ST7580's VCC/PA rail, 2A switch | 1 | $0.30 | $0.30 |
| 7 | LDO | AMS1117-3.3 | `U3` — 3.3V rail for the ESP32-C3 | 1 | $0.15 | $0.15 |
| 8 | Crystal | 8MHz | `Y1` — ST7580 clock reference | 1 | $0.15 | $0.15 |
| 9 | Boost inductor | 22µH, 2A saturation | `L1` — MT3608 switching inductor | 1 | $0.20 | $0.20 |
| 10 | Schottky diodes | SS34 | `D5`–`D8` — source ORing (2), supercap discharge (1), boost rectifier (1) | 4 | $0.10 | $0.40 |
| 11 | Supercapacitor | NAT 1F 5.5V | `C7` — hold-up so the ESP32 can tell the Terminal mains has gone | 1 | $1.20 | $1.20 |
| 12 | USB-C receptacle | TYPE-C-31-M-12 | `J4` (`TERMINAL_5V_IN`) — 5V inlet from the Terminal's battery during an outage | 1 | $0.40 | $0.40 |
| 13 | Coupling transformer | Würth Elektronik 750510231 | `T1` — PLC line coupling, 1:1 ±1%, 1mH, leakage ≤1µH, 30pF interwinding — the exact part AN4068 names (alternate: TDK SRW13EP-X05H002). REV 0.5 carried "WE-PLCC series, confirm against the application note"; that note has now been read, and every AN4068 Table 4 line is met except withstanding voltage, where Würth quotes 2000VAC/1s against Table 4's ≥4kV impulse figure — confirm with Würth before ordering ([`docs/plc-coupling.md`](../docs/plc-coupling.md)) | 1 | $2.00 | $2.00 |
| 14 | Coupling inductor | 12µH, ≥2A saturation, ≤0.1Ω DCR | `L3` — series element of the line coupling resonance with item 15; the saturation and DCR figures are AN4068's own selection criteria, not preferences — insertion loss and distortion into a heavily loaded line depend on them | 1 | $0.30 | $0.30 |
| 15 | X1 safety capacitor | 150nF X1 MKP, p=15mm | `C17` — series coupling into the live conductor. X1 grade is a safety requirement, not a filter one: this part sits between the board's analog ground and 230V | 1 | $0.60 | $0.60 |
| 16 | Coupling passives | 150µH + 12nF (Rx resonance), 10µF/50V X5R (DC block), 68pF/1nF C0G + 5.1k/22k/33k/10k/1k/150R (Tx active filter) | `L2`, `C15`, `C16`, `C12`–`C14` and the Tx filter resistor network — the rest of the line coupling, values rescaled from AN4068's A-band reference design to GRIDNET's 95–140kHz band, see [`docs/plc-coupling.md`](../docs/plc-coupling.md) | 1 set | $0.80 | $0.80 |
| 17 | Mains header | Würth Elektronik 691311400102 | `J1` (`MAINS_L_N`) — WR-TBL series 3114, closed vertical PCB header, 2-pole, 7.62mm pitch, 300V / 20A (UL), 1600 VAC withstanding. The pitch is not a preference: the 5.08mm placeholder left 2.08mm between its own pads against the `Mains` netclass's standards-derived 2.5mm L-to-N rule, so it failed DRC on its own connector. The current rating is irrelevant here — the HLK-5M05 draws about 30mA at 230V — the pitch is what the clearance rule buys. This is the part the PCB footprint already uses | 1 | $0.42 | $0.42 |
| 18 | Mains header mating plug | Würth Elektronik 691351400002 | Female plug for item 17 — the Schuko plug's L/N wires terminate here, and it plugs onto `J1`. **A pluggable header is only half a connector**; this part was missing from the BOM entirely through REV 0.9, so the board could have been fabricated with no way to attach mains wiring. Kept pluggable rather than swapped for a one-piece block because being able to detach mains from the board without desoldering is worth $1.25 during prototype bring-up | 1 | $1.25 | $1.25 |
| 19 | Status LEDs | — | `D2`/`D3`/`D4` — Power (green, always-on), PLC (amber, driven by the ST7580's `PL_TX_ON`), Wi-Fi (blue, GPIO-driven so firmware can show real status). On-board and wired to the rails directly, not brought out to a separate header | 3 | $0.10 | $0.30 |
| 20 | Programming / debug headers | — | `J2` (ESP32-C3 UART0 — without this there is no way to flash the module at all) and `J3` (ST7580 JTAG) | 2 | $0.20 | $0.40 |
| 21 | Passive components | — | Remaining bulk/bypass R, C, L and ferrite beads (`C1`–`C6`, `C8`–`C11`, `FB1`–`FB2`, `R1`–`R20` less the coupling network above) | — | $1.50 | $1.50 |
| | | | | | **Board 1 Total** | **~$21.37** |

> **On the one-piece alternative.** Würth 691214410002 (WR-TBL 2144, 7.62mm
> horizontal entry, rising cage clamp) would replace both items above with a
> single part at roughly $0.83–1.07, and carries a VDE rating of 450 VAC with
> 2500 VAC withstanding — the latter lining up with IEC 60664's 2500V rated
> impulse for overvoltage category II at 230V, where the 3114's published
> cULus figure is 1600 VAC. It was not adopted here because it needs a
> footprint change, a PCB regeneration and a fresh DRC pass on a board that is
> otherwise ready to fabricate. Worth revisiting before any production run —
> note also its 1.31 mm² (16 AWG) wire ceiling, which rules out 1.5 mm²
> internal wiring.

## Board 2 — Main Board (100×80mm)

| # | Component | Part Number | Description | Qty | Unit Cost (USD) | Total |
|---|---|---|---|---|---|---|
| 1 | MCU | GD32VF103CCT6 | RISC-V, 108MHz, 32KB RAM, 256KB Flash — same 48-pin package/pinout as REV 0.4's CBT6, next density step up (REV 0.4's README claimed 1MB Flash, which no GD32VF103 variant actually offers; 256KB is the real ceiling in this pin-compatible family) | 1 | $1.80 | $1.80 |
| 2 | Wi-Fi / BT Module | ESP32-C3-MINI-1U | Wi-Fi 2.4GHz mesh + Bluetooth 5.0 LE — "U" variant, has the on-module external-antenna jack REV 0.4's plain MINI-1 lacks (see items 13-14). That jack is the module's only RF output: datasheet v2.2 Table 3-1 gives the module 53 pads and none of them is an RF pad | 1 | $0.80 | $0.80 |
| 3 | SRAM | 23LC1024 | 1Mb SPI SRAM | 1 | $1.20 | $1.20 |
| 4 | Flash | W25Q64JVSSIQ | 8MB SPI NOR Flash | 1 | $0.60 | $0.60 |
| 5 | RTC | DS3231SN | I2C RTC, ±2ppm accuracy | 1 | $1.80 | $1.80 |
| 6 | RTC Battery | CR2032 | 3V coin cell | 1 | $0.30 | $0.30 |
| 7 | LiPo charger | MCP73831 | Single-cell LiPo charge controller | 1 | $0.50 | $0.50 |
| 8 | Boost converter | IP5306 | 5V boost + battery management | 1 | $0.60 | $0.60 |
| 9 | LDO | AMS1117-3.3 | 3.3V LDO regulator | 2 | $0.15 | $0.30 |
| 10 | Amplifier | PAM8403 | 3W class-D audio amplifier | 1 | $0.40 | $0.40 |
| 11 | microSD socket | — | SPI, push-push type | 1 | $0.50 | $0.50 |
| 12 | USB-C connector | — | Power input, DFU firmware update | 1 | $0.40 | $0.40 |
| 13 | SMA jack, bulkhead | — | Antenna port through the enclosure wall. Not a PCB part: an edge-mount SMA soldered to the board cannot be fed by a pigtail, because its centre pin is a board pad. REV 0.5 specified the edge-mount version and it was placed on the PCB as J8; see [`hardware/pcb/main-board/README.md`](pcb/main-board/README.md) | 1 | $0.80 | $0.80 |
| 14 | Antenna pigtail | MHF III (W.FL / AMC) plug to SMA | ~100mm, from item 2's on-module jack to item 13. Not U.FL: datasheet section 10.2 specifies the third-generation connector (2.05×1.7×1.40mm, compatible with Hirose W.FL, I-PEX MHF III, Amphenol AMC), and a U.FL/MHF I plug does not mate with it | 1 | $0.60 | $0.60 |
| 15 | 2.4GHz antenna | — | SMA male, ≤2.33 dBi, 50Ω. The gain ceiling is not a preference: 2.33 dBi is the antenna Espressif certified the module with, and exceeding it puts the product outside the module's existing test reports (datasheet section 10.2). Missing from REV 0.5 entirely — the BOM had the connector and the cable but no antenna | 1 | $1.20 | $1.20 |
| 16 | Crystal | 8MHz HC49/SMD + 2×20pF load caps | GD32VF103 HSE clock reference | 1 | $0.15 | $0.15 |
| 17 | Passive components | — | Resistors, capacitors, inductors | — | $1.50 | $1.50 |
| | | | | | **Board 2 Total** | **~$13.45** |

## Display & Input

| # | Component | Part Number | Description | Qty | Unit Cost (USD) | Total |
|---|---|---|---|---|---|---|
| 1 | LCD Display + controller | RA8875-based 800×480 TFT module (SPI, onboard SDRAM frame buffer) | 5.0" TFT, 800×480, 256-color (8bpp) mode, amber-tinted backlight — REV 0.4 specified ILI9488, which tops out at 480×320 and cannot drive this resolution at all; RA8875 modules ship with their own onboard SDRAM specifically so a small MCU with no LCD/LTDC peripheral (like the GD32VF103) never has to hold an 800×480 frame buffer itself (384KB — far beyond both the MCU's 32KB RAM and the board's 128KB SPI SRAM) | 1 | $32.00 | $32.00 |
| 2 | Keyboard controller | CH552G | USB MCU, key matrix scanning | 1 | $0.50 | $0.50 |
| 3 | Key switches | Kailh PG1350 | Low-profile mechanical, 40 pcs | 40 | $0.25 | $10.00 |
| 4 | Keycaps | — | Low-profile, custom legend | 1 set | $3.00 | $3.00 |
| 5 | Keyboard backlight | — | Amber SMD LED, 0402, 40 pcs | 40 | $0.03 | $1.20 |
| 6 | TrackPoint module | Generic analog trackpoint module (hobbyist keyboard-build market) | Analog X/Y strain-gauge output, direct-ADC-compatible — REV 0.4 said "PS/2 compatible," which is a synchronous serial protocol needing bit-banged/USART decoding, not a raw ADC read; [`docs/firmware-arch.md`](../docs/firmware-arch.md)'s own task table already says "TrackPoint ADC," so the description (not the part class) was the mismatch | 1 | $2.50 | $2.50 |
| 7 | Speaker | — | 1W, 8Ω, 28mm diameter | 1 | $1.50 | $1.50 |
| | | | | | **Display & Input Total** | **~$50.70** |

## Power System

| # | Component | Part Number | Description | Qty | Unit Cost (USD) | Total |
|---|---|---|---|---|---|---|
| 1 | Li-ion cell | Genuine 18650, 3350mAh-class (e.g. Panasonic NCR18650B) — source from an authorized distributor, not generic marketplace listings | 3.7V, 3350mAh — 2 cells in parallel = ~6700mAh total. REV 0.4 spec'd 2×2500mAh cells (=5000mAh) in the BOM while the top-level README claimed "8000mAh" — no genuine 18650 chemistry reaches 4000mAh/cell (2× would need to), and 18650s advertised at 8000-9000mAh on general marketplaces are essentially always counterfeit/overrated; 6700mAh is the real ceiling for 2 genuine cells and the closest honest match to the original target | 2 | $4.20 | $8.40 |
| 2 | Battery holder | — | 2× 18650 parallel holder | 1 | $1.50 | $1.50 |
| 3 | Protection circuit | — | Overcurrent + overvoltage PCM | 1 | $0.80 | $0.80 |
| | | | | | **Power Total** | **~$10.70** |

## Enclosure

| # | Component | Description | Qty | Unit Cost (USD) | Total |
|---|---|---|---|---|---|
| 1 | Top case | Mat black ABS-PC, clamshell lid | 1 | $8.00 | $8.00 |
| 2 | Bottom case | Mat black ABS-PC, keyboard base | 1 | $8.00 | $8.00 |
| 3 | Hinge assembly | Steel, 135° stop, ×2 | 1 set | $3.00 | $3.00 |
| 4 | Corner bumpers | TPU rubber, ×4 | 1 set | $1.00 | $1.00 |
| 5 | Screws & inserts | M2 screws + brass inserts | 1 set | $1.50 | $1.50 |
| | | | | **Enclosure Total** | **~$21.50** |

## PLC Adapter — Non-PCB Parts

Only what Board 1 does not already carry. Through REV 0.8 this section was a
second, parallel bill for the whole Adapter — see the REV 0.9 note at the top
of this file.

| # | Component | Part Number | Description | Qty | Unit Cost (USD) | Total |
|---|---|---|---|---|---|---|
| 1 | Schuko plug | — | Direct wall mount, 230V. Wires to Board 1's `J1` | 1 | $1.50 | $1.50 |
| 2 | Enclosure | Mat black ABS | Compact square, ~110×90×30mm — sized for Board 1's 100×80mm PCB plus the Schuko plug and wall clearance; REV 0.4's ~80×80×40mm estimate predates that PCB size and never got reconciled against it, unlike the other REV 0.4 numbers listed in "Design Notes — REV History" below | 1 | $3.00 | $3.00 |
| | | | | | **Adapter Non-PCB Total** | **~$4.50** |

## PCB Manufacturing (JLCPCB, 5 units each)

Two boards, not three. This project has exactly two PCBs — Board 1 (the
Adapter) and Board 2 (the Terminal). Through REV 0.8 this table also carried a
70×60mm "Adapter Board", which was the same double-count as the section above:
there is no such board and none is designed.

| Board | Size | Layers | Qty | Cost |
|---|---|---|---|---|
| Board 1 — PLC / Power Board | 100×80mm | 4 — see [`hardware/pcb/plc-board/README.md`](pcb/plc-board/README.md) | 5 pcs | ~$20.00 |
| Board 2 — Main Board | 100×80mm | 2 — 1.6mm FR-4, 1oz copper, per `STACKUP` in `build_pcb.py` | 5 pcs | ~$8.00 |
| | | | **PCB Total** | **~$28.00** |

## Cost Summary

Grouped by the two products this project actually builds.

| Module | Cost (USD) |
|---|---|
| **Terminal** | |
| Board 2 — Main Board | ~$13.45 |
| Display & Input | ~$50.70 |
| Power System | ~$10.70 |
| Enclosure (clamshell) | ~$21.50 |
| Board 2 fabrication | ~$8.00 |
| *Terminal subtotal* | *~$104.35* |
| **PLC Adapter** | |
| Board 1 — PLC / Power | ~$21.37 |
| Non-PCB parts (plug, enclosure) | ~$4.50 |
| Board 1 fabrication | ~$20.00 |
| *Adapter subtotal* | *~$45.87* |
| **TOTAL (single prototype, one of each)** | **~$150.22** |

REV 0.4 totaled ~$135.80 and the top-level README separately claimed ~$112;
REV 0.8 corrected those to ~$166.65. That figure did not survive either — it
counted the PLC Adapter twice, once as Board 1's line items and again as a
parallel "PLC Adapter" bill, plus a 70×60mm PCB that does not exist. Removing
the duplicate takes $14.60 of parts and $5.00 of fabrication off; adding the
five components Board 1's schematic has but its BOM never listed (ESP32-C3,
AMS1117-3.3, 8MHz crystal, 3 status LEDs, 2 programming headers) puts $1.80
back, and pricing `J1` as the real part plus the mating plug it needs adds
another $1.37 over the header it replaced. Net: **~$150.22**.

The display module remains the single largest line at $32.00 — more than
either PCB and its parts.

Every subtotal in this file equals the sum of its own line items, and the
total equals the sum of the subtotals.

**Note:** Costs are single-unit retail estimates. Volume pricing significantly reduces cost (per-unit ratios carried over from REV 0.4's estimate, rescaled to this total):

- 10 units → ~$118/unit
- 100 units → ~$77/unit
- 1000 units → ~$47/unit

## Where To Source

| Supplier | What To Buy |
|---|---|
| LCSC | All ICs, passives, connectors (China, fast shipping) |
| JLCPCB | PCB fabrication + optional SMT assembly |
| AliExpress | Enclosure parts, mechanical parts — **not** battery cells (see note) |
| 18650 cells | 18650BatteryStore, Illumn, or another dedicated protected-cell reseller — avoid generic marketplace listings specifically for cells; "8000mAh 18650" listings are essentially always counterfeit/overrated, real cells top out around 3500mAh per cell |
| Mouser | ST7580 (official distributor), DS3231, protection ICs, RA8875 display modules |
| DigiKey | Alternative for all major ICs |

## Design Notes — REV History

REV 0.5 replaces five REV 0.4 choices that didn't survive a component-level
review — each one reproducible from the datasheet/module spec, not a
judgment call:

1. **Display driver couldn't produce the specified resolution.** ILI9488 tops
   out at 480×320; the spec called for 800×480. Even a corrected driver IC
   needed a second property the GD32VF103 doesn't have: an LTDC/RGB display
   peripheral, or enough RAM (800×480 at 8bpp is 384KB — more than the 32KB
   on-chip RAM and the 128KB external SPI SRAM combined) to hold a frame
   buffer itself. Fix: an RA8875-based module, which ships with its own
   onboard SDRAM and talks to the host MCU over SPI a command/pixel stream
   at a time — the standard way small MCUs drive displays too large to
   buffer themselves.
2. **Wi-Fi module variant had no connector for the antenna next to it in the
   BOM.** ESP32-C3-MINI-1 has an onboard PCB antenna and no external-antenna
   connector at all; ESP32-C3-MINI-1U (same pinout/footprint) has the
   antenna jack the SMA connector needs something to plug into. Fix: swap
   the module, add the missing pigtail. (REV 0.5 called that jack "U.FL"
   and specified a U.FL pigtail and an edge-mount SMA to go with it. All
   three were wrong — see the REV 0.6 note below.)
3. **MCU flash size in the top-level README (1MB) doesn't exist in this chip
   family** — GD32VF103's real ceiling is 256KB, still in a pin-compatible
   part (CCT6 vs. the original CBT6's 128KB). Fixed the BOM to the real part
   and the README to the real number, rather than chasing a spec no variant
   of this MCU can meet.
4. **Battery capacity claim (8000mAh) doesn't match** either the BOM's actual
   2×2500mAh cells (5000mAh) or physical reality for 2 cells of any genuine
   18650 chemistry (would need 4000mAh/cell; real cells top out ~3500mAh).
   Fixed to genuine 3350mAh-class cells (~6700mAh total) — the honest
   ceiling for 2 real cells, and flagged the "8000mAh 18650" claims common
   on general marketplaces as effectively always counterfeit. (The "~5 days
   active use" runtime derived from this capacity was also wrong for
   unrelated reasons — see [`docs/firmware-arch.md`](../docs/firmware-arch.md)'s Power Budget section.)
5. **TrackPoint description said "PS/2 compatible"** (a synchronous serial
   protocol) while [`docs/firmware-arch.md`](../docs/firmware-arch.md)'s own task table already said
   "TrackPoint ADC" (raw analog reads) — these need different firmware and
   different wiring. The part class that's actually sourced for DIY
   keyboard builds is analog/ADC-compatible, matching the firmware doc; only
   the BOM's description was wrong, not the part.
6. **PLC Adapter enclosure sized for a different PCB than the one in its own
   BOM.** Board 1 (the PLC Adapter's PCB) is spec'd at 100×80mm, but the
   Adapter's enclosure line said "~80×80×40mm" — physically too small to
   hold that PCB. Unlike items 1-5 above, this one wasn't part of the
   original REV 0.5 pass; caught later, once Board 1's schematic work
   started. Fixed to ~110×90×30mm (fits the PCB plus the Schuko plug and
   wall clearance). Also clarified Board 1's `J1` connector description —
   "main board interface" read as if it connected to Board 2 (the Terminal's
   Main Board), but Board 1 and Board 2 are different products that never
   connect to each other (see the top-level README's Hardware Overview);
   `J1` is this board's own interface to the Adapter's Schuko-plug wiring
   and status LEDs.

REV 0.6 corrects the antenna chain, all of it from the ESP32-C3-MINI-1/1U
datasheet v2.2 while laying out Board 2 (see
[`hardware/pcb/main-board/README.md`](pcb/main-board/README.md)'s "The antenna path never touched the
board"):

7. **The pigtail was the wrong connector generation.** Section 10.2 specifies
   the module's jack as the third-generation connector — 2.05×1.7×1.40mm,
   compatible with Hirose W.FL, I-PEX MHF III and Amphenol AMC. U.FL /
   MHF I is the first generation, ~2.6mm across, and does not mate with it.
   Every "U.FL" in REV 0.5's Board 2 items and design notes was wrong about
   the part on the module.
8. **The SMA was specified edge-mount, which the pigtail cannot reach.** An
   edge-mount SMA's centre pin is a pad on the PCB, so it has to be fed by
   board copper — and the module has no RF pad to feed it from (Table 3-1:
   53 pads, all GND, 3V3, EN or IO). It is now a bulkhead jack in the
   enclosure wall, which is what a pigtail actually terminates in, and it
   is no longer a PCB part.
9. **There was no antenna in the BOM.** Items 13 and 14 bought a connector and
   a cable to nowhere. Added, with the gain ceiling the module's
   certification depends on (≤2.33 dBi).

Also added two REV 0.4 omissions that would have blocked fabrication
regardless: an explicit crystal for the GD32VF103's clock (was silently
folded into a generic "passives" line with no frequency specified), and a
named component family for the PLC coupling transformer (was a bare "—"
with no part reference at all — still needs confirming against ST7580's
application note before ordering, this isn't a fully closed item).

---

Last updated: 2026 — REV 0.10

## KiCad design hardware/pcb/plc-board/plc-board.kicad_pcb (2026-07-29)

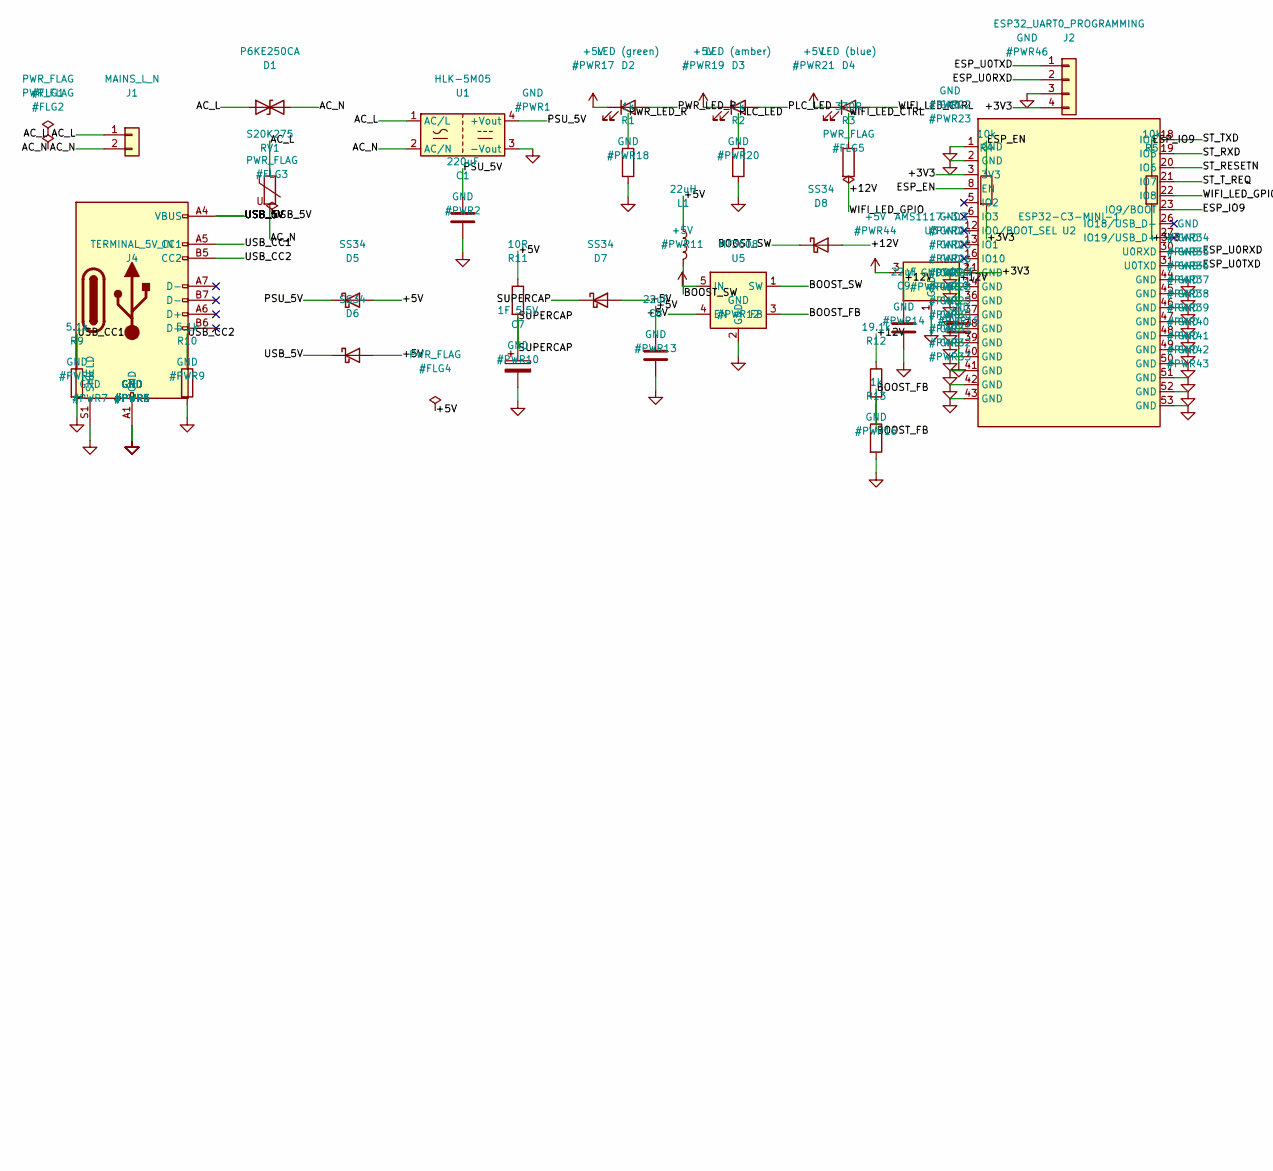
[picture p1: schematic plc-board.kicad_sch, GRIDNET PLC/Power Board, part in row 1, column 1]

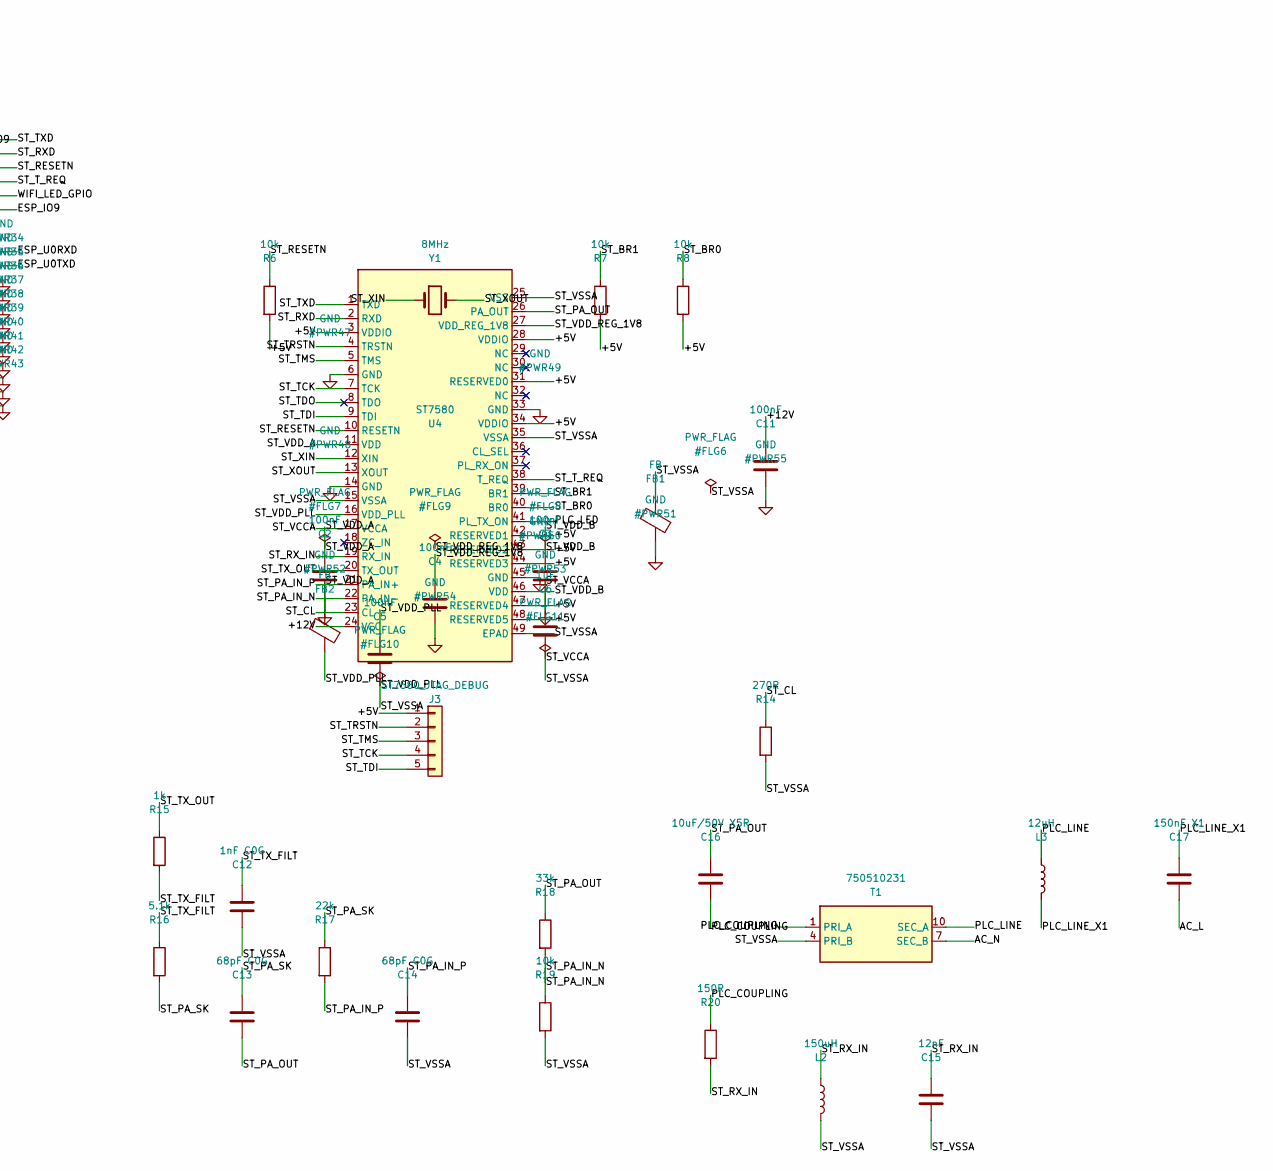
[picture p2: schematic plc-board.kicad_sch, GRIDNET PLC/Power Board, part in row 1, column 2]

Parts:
C1: 220uF; CP_Radial_D8.0mm_P3.50mm
C2, C3, C4, C5, C11: 100nF; C_0603_1608Metric
C6: 1uF; C_0805_2012Metric
C7: 1F 5.5V; CP_Radial_D10.0mm_P5.00mm
C8, C9: 22uF; C_1206_3216Metric
C10: 100uF; CP_Radial_D6.3mm_P2.50mm
C12: 1nF C0G; C_0603_1608Metric
C13, C14: 68pF C0G; C_0603_1608Metric
C15: 12nF; C_0603_1608Metric
C16: 10uF/50V X5R; C_1210_3225Metric
C17: 150nF X1; C_Rect_L16.5mm_W5.0mm_P15.00mm_MKT
D1: P6KE250CA; D_5W_P10.16mm_Horizontal
D2: LED (green); LED_D5.0mm
D3: LED (amber); LED_D5.0mm
D4: LED (blue); LED_D5.0mm
D5, D6, D7, D8: SS34; D_SMA
FB1, FB2: FB; L_0805_2012Metric
J1: MAINS_L_N; TerminalBlock_Wuerth_691311400102_P7.62mm
J2: ESP32_UART0_PROGRAMMING; PinHeader_1x04_P2.54mm_Vertical
J3: ST7580_JTAG_DEBUG; PinHeader_1x05_P2.54mm_Vertical
J4: TERMINAL_5V_IN; USB_C_Receptacle_HRO_TYPE-C-31-M-12
L1: 22uH; L_6.3x6.3_H3
L2: 150uH; L_1210_3225Metric
L3: 12uH; L_7.3x7.3_H4.5
R1, R2: 1k; R_Axial_DIN0207_L6.3mm_D2.5mm_P10.16mm_Horizontal
R3: 330R; R_Axial_DIN0207_L6.3mm_D2.5mm_P10.16mm_Horizontal
R4, R5, R6, R7, R8, R19: 10k; R_0603_1608Metric
R9, R10, R16: 5.1k; R_0603_1608Metric
R11: 10R; R_1206_3216Metric
R12: 19.1k; R_0603_1608Metric
R13, R15: 1k; R_0603_1608Metric
R14: 270R; R_0603_1608Metric
R17: 22k; R_0603_1608Metric
R18: 33k; R_0603_1608Metric
R20: 150R; R_0603_1608Metric
RV1: S20K275; RV_Disc_D21.5mm_W7.5mm_P10mm
T1: 750510231; Transformer_Wuerth_750510231
U1: HLK-5M05; Converter_ACDC_Hi-Link_HLK-5Mxx
U2: ESP32-C3-MINI-1
U3: AMS1117-3.3; SOT-223-3_TabPin2
U4: ST7580; QFN-48-1EP_7x7mm_P0.5mm_EP5.1x5.1mm
U5: MT3608; SOT-23-6
Y1: 8MHz; Crystal_SMD_HC49-SD

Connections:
+5V: C8.1, D2.1 (K), D3.1 (K), D4.1 (K), D5.2 (A), D6.2 (A), D7.2 (A), J3.1, L1.1, R6.2, R7.2, R8.2, R11.1, U3.3 (VI), U4.3 (VDDIO), U4.28 (VDDIO), U4.31 (RESERVED0), U4.34 (VDDIO), U4.42 (RESERVED1), U4.43 (RESERVED2), U4.44 (RESERVED3), U4.47 (RESERVED4), U4.48 (RESERVED5), U5.4 (EN), U5.5 (IN)
/+3V3: J2.4, R4.2, R5.2, U2.3 (3V3), U3.2 (VO)
/AC_L: C17.2, D1.1 (A1), J1.1, RV1.1, U1.1 (AC/L)
/AC_N: D1.2 (A2), J1.2, RV1.2, T1.7 (SEC_B), U1.2 (AC/N)
/BOOST_FB: R12.2, R13.1, U5.3 (FB)
/BOOST_SW: D8.1 (K), L1.2, U5.1 (SW)
/ESP_EN: R4.1, U2.8 (EN)
/ESP_IO9: R5.1, U2.23 (IO9/BOOT)
/ESP_U0RXD: J2.2, U2.30 (U0RXD)
/ESP_U0TXD: J2.1, U2.31 (U0TXD)
/PLC_COUPLING: C16.2, R20.1, T1.1 (PRI_A)
/PLC_LED: D3.2 (A), R2.1, U4.41 (PL_TX_ON)
/PLC_LINE: L3.1, T1.10 (SEC_A)
/PLC_LINE_X1: C17.1, L3.2
/PSU_5V: C1.1, D5.1 (K), U1.4 (+Vout)
/PWR_LED_R: D2.2 (A), R1.1
/ST_BR0: R8.1, U4.40 (BR0)
/ST_BR1: R7.1, U4.39 (BR1)
/ST_CL: R14.1, U4.23 (CL)
/ST_PA_IN_N: R18.2, R19.1, U4.22 (PA_IN-)
/ST_PA_IN_P: C14.1, R17.2, U4.21 (PA_IN+)
/ST_PA_OUT: C13.2, C16.1, R18.1, U4.26 (PA_OUT)
/ST_PA_SK: C13.1, R16.2, R17.1
/ST_RESETN: R6.1, U2.20 (IO6), U4.10 (RESETN)
/ST_RXD: U2.19 (IO5), U4.2 (RXD)
/ST_RX_IN: C15.1, L2.1, R20.2, U4.19 (RX_IN)
/ST_TCK: J3.4, U4.7 (TCK)
/ST_TDI: J3.5, U4.9 (TDI)
/ST_TDO: U4.8 (TDO)
/ST_TMS: J3.3, U4.5 (TMS)
/ST_TRSTN: J3.2, U4.4 (TRSTN)
/ST_TXD: U2.18 (IO4), U4.1 (TXD)
/ST_TX_FILT: C12.1, R15.2, R16.1
/ST_TX_OUT: R15.1, U4.20 (TX_OUT)
/ST_T_REQ: U2.21 (IO7), U4.38 (T_REQ)
/ST_VDD_A: C2.1, FB2.1, U4.11 (VDD)
/ST_VDD_B: C3.1, U4.46 (VDD)
/ST_VDD_REG_1V8: C4.1, U4.27 (VDD_REG_1V8)
/ST_XIN: U4.12 (XIN), Y1.1
/ST_XOUT: U4.13 (XOUT), Y1.2
/SUPERCAP: C7.1, D7.1 (K), R11.2
/USB_5V: D6.1 (K), J4.A4 (VBUS), J4.A9 (VBUS), J4.B4 (VBUS), J4.B9 (VBUS)
/USB_CC1: J4.A5 (CC1), R9.1
/USB_CC2: J4.B5 (CC2), R10.1
/WIFI_LED_CTRL: D4.2 (A), R3.1
GND: C1.2, C2.2, C3.2, C4.2, C7.2, C8.2, C9.2, C10.2, C11.2, FB1.2, J2.3, J4.A1 (GND), J4.A12 (GND), J4.B1 (GND), J4.B12 (GND), J4.S1 (SHIELD), R1.2, R2.2, R9.2, R10.2, R13.2, U1.3 (-Vout), U2.1 (GND), U2.2 (GND), U2.11 (GND), U2.14 (GND), U2.36 (GND), U2.37 (GND), U2.38 (GND), U2.39 (GND), U2.40 (GND), U2.41 (GND), U2.42 (GND), U2.43 (GND), U2.44 (GND), U2.45 (GND), U2.46 (GND), U2.47 (GND), U2.48 (GND), U2.49 (GND), U2.50 (GND), U2.51 (GND), U2.52 (GND), U2.53 (GND), U3.1 (GND), U4.6 (GND), U4.14 (GND), U4.33 (GND), U4.45 (GND), U5.2 (GND)

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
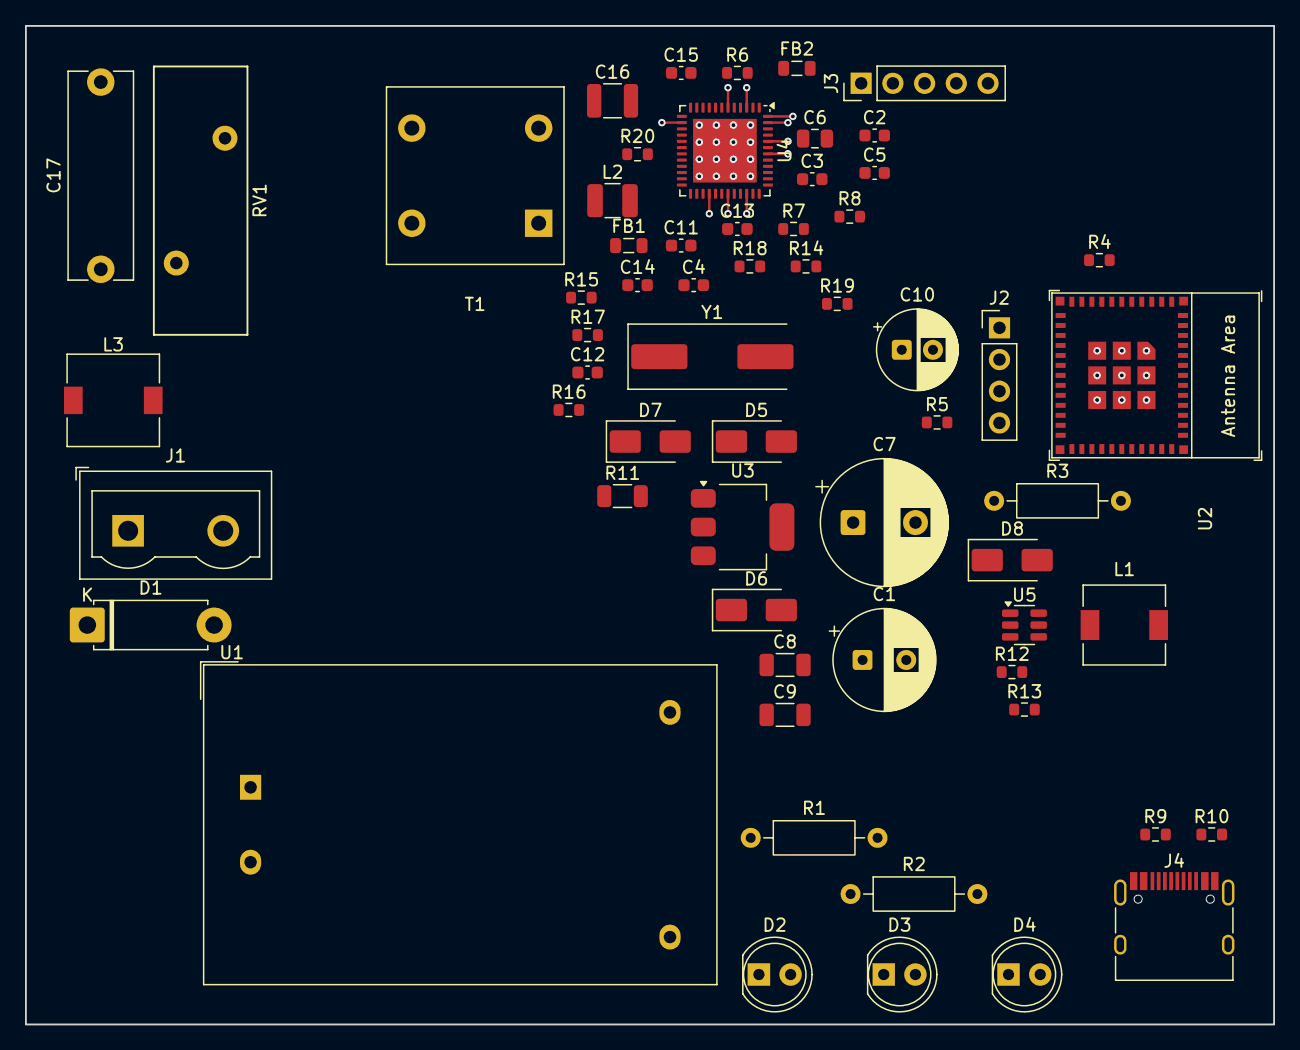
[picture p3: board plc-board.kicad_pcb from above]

Board: 4 copper layers, 100.0 x 80.0 mm, 62 parts (0 on the bottom side), 50 nets.

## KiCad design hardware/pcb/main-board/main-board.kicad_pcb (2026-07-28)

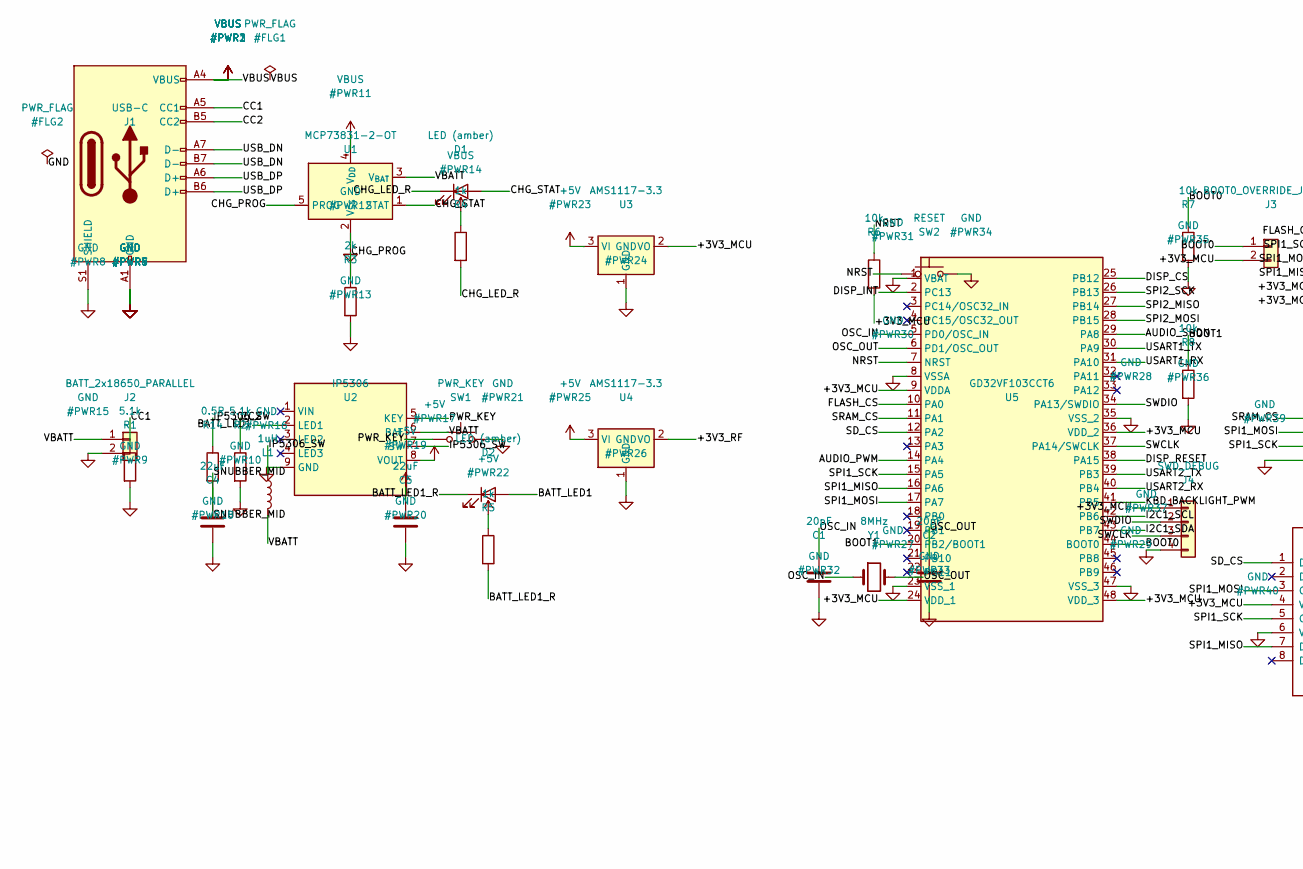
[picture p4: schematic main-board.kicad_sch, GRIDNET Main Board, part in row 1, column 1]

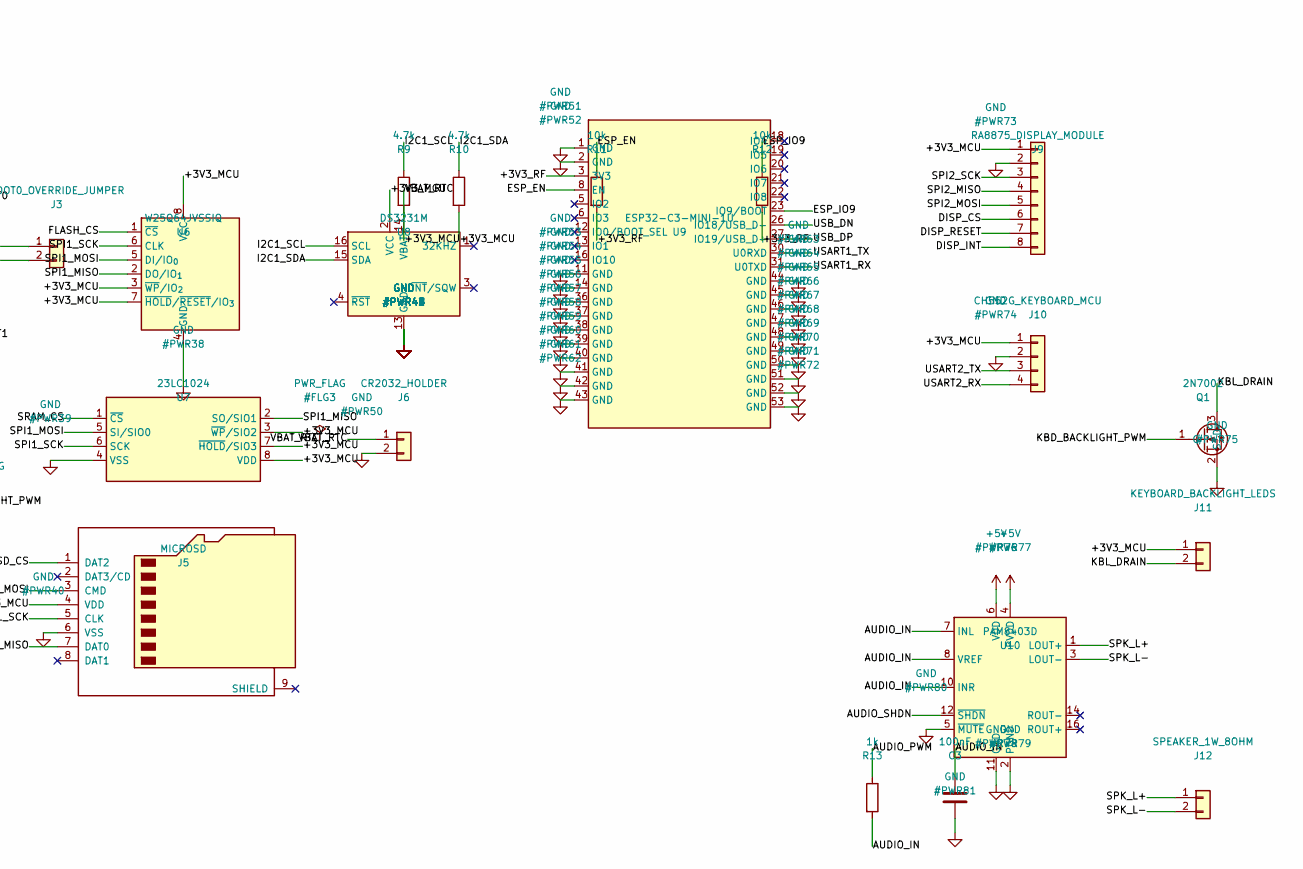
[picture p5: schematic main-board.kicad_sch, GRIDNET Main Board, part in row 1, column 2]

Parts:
C1, C2: 20pF; C_0603_1608Metric
C3: 100nF; C_0603_1608Metric
C4, C5: 22uF; C_0805_2012Metric
D1, D2: LED (amber); LED_0603_1608Metric
J1: USB-C; USB_C_Receptacle_HRO_TYPE-C-31-M-12
J2: BATT_2x18650_PARALLEL; JST_PH_B2B-PH-K_1x02_P2.00mm_Vertical
J3: BOOT0_OVERRIDE_JUMPER; PinHeader_1x02_P2.54mm_Vertical
J4: SWD_DEBUG; PinHeader_1x04_P2.54mm_Vertical
J5: MICROSD; microSD_HC_Molex_104031-0811
J6: CR2032_HOLDER; BatteryHolder_MYOUNG_BS-07-A1BJ001_CR2032
J9: RA8875_DISPLAY_MODULE; PinHeader_1x08_P2.54mm_Vertical
J10: CH552G_KEYBOARD_MCU; PinHeader_1x04_P2.54mm_Vertical
J11: KEYBOARD_BACKLIGHT_LEDS; PinHeader_1x02_P2.54mm_Vertical
J12: SPEAKER_1W_8OHM; PinHeader_1x02_P2.54mm_Vertical
L1: 1uH; L_6.3x6.3_H3
Q1: 2N7002; SOT-23
R1, R2: 5.1k; R_0603_1608Metric
R3: 2k; R_0603_1608Metric
R4, R5, R13: 1k; R_0603_1608Metric
R6, R7, R8, R11, R12: 10k; R_0603_1608Metric
R9, R10: 4.7k; R_0603_1608Metric
R14: 0.5R; R_0603_1608Metric
SW1: PWR_KEY; SW_PUSH_6mm_H4.3mm
SW2: RESET; SW_PUSH_6mm_H4.3mm
U1: MCP73831-2-OT; SOT-23-5
U2: IP5306; SOP-8_3.9x4.9mm_P1.27mm
U3, U4: AMS1117-3.3; SOT-223-3_TabPin2
U5: GD32VF103CCT6; LQFP-48_7x7mm_P0.5mm
U6: W25Q64JVSSIQ; SOIC-8_5.3x5.3mm_P1.27mm
U7: 23LC1024; SOIC-8_3.9x4.9mm_P1.27mm
U8: DS3231M; SOIC-16W_7.5x10.3mm_P1.27mm
U9: ESP32-C3-MINI-1U
U10: PAM8403D; SOP-16_3.9x9.9mm_P1.27mm
Y1: 8MHz; Crystal_SMD_HC49-SD

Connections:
+5V: C5.1, R5.1, U2.8 (VOUT), U3.3 (VI), U4.3 (VI), U10.4 (PVDD), U10.6 (VDD), U10.13 (PVDD)
/+3V3_MCU: J3.2, J4.1, J5.4 (VDD), J9.1, J10.1, J11.1, R6.2, R9.2, R10.2, U3.2 (VO), U5.9 (VDDA), U5.24 (VDD_1), U5.36 (VDD_2), U5.48 (VDD_3), U6.3 (~WP/IO_{2}), U6.7 (~HOLD/~RESET/IO_{3}), U6.8 (VCC), U7.3 (~WP/SIO2), U7.7 (~HOLD/SIO3), U7.8 (VDD), U8.2 (VCC)
/+3V3_RF: R11.2, R12.2, U4.2 (VO), U9.3 (3V3)
/AUDIO_IN: C3.1, R13.2, U10.7 (INL), U10.8 (VREF), U10.10 (INR)
/AUDIO_PWM: R13.1, U5.14 (PA4)
/AUDIO_SHDN: U5.29 (PA8), U10.12 (~SHDN)
/BATT_LED1: D2.2 (A), U2.2 (LED1)
/BATT_LED1_R: D2.1 (K), R5.2
/BOOT0: J3.1, R7.1, U5.44 (BOOT0)
/BOOT1: R8.1, U5.20 (PB2/BOOT1)
/CC1: J1.A5 (CC1), R1.1
/CC2: J1.B5 (CC2), R2.1
/CHG_LED_R: D1.1 (K), R4.2
/CHG_PROG: R3.1, U1.5 (PROG)
/CHG_STAT: D1.2 (A), U1.1 (STAT)
/DISP_CS: J9.6, U5.25 (PB12)
/DISP_INT: J9.8, U5.2 (PC13)
/DISP_RESET: J9.7, U5.38 (PA15)
/ESP_EN: R11.1, U9.8 (EN)
/ESP_IO9: R12.1, U9.23 (IO9/BOOT)
/FLASH_CS: U5.10 (PA0), U6.1 (~CS)
/I2C1_SCL: R9.1, U5.42 (PB6), U8.16 (SCL)
/I2C1_SDA: R10.1, U5.43 (PB7), U8.15 (SDA)
/IP5306_SW: L1.1, R14.1, U2.7 (SW)
/KBD_BACKLIGHT_PWM: Q1.1 (G), U5.41 (PB5)
/KBL_DRAIN: J11.2, Q1.3 (D)
/NRST: R6.1, SW2.1, U5.7 (NRST)
/OSC_IN: C1.1, U5.5 (PD0/OSC_IN), Y1.1
/OSC_OUT: C2.1, U5.6 (PD1/OSC_OUT), Y1.2
/PWR_KEY: SW1.1, U2.5 (KEY)
/SD_CS: J5.1 (DAT2), U5.12 (PA2)
/SNUBBER_MID: C4.1, R14.2
/SPI1_MISO: J5.7 (DAT0), U5.16 (PA6), U6.2 (DO/IO_{1}), U7.2 (SO/SIO1)
/SPI1_MOSI: J5.3 (CMD), U5.17 (PA7), U6.5 (DI/IO_{0}), U7.5 (SI/SIO0)
/SPI1_SCK: J5.5 (CLK), U5.15 (PA5), U6.6 (CLK), U7.6 (SCK)
/SPI2_MISO: J9.4, U5.27 (PB14)
/SPI2_MOSI: J9.5, U5.28 (PB15)
/SPI2_SCK: J9.3, U5.26 (PB13)
/SPK_L+: J12.1, U10.1 (LOUT+)
/SPK_L-: J12.2, U10.3 (LOUT-)
/SRAM_CS: U5.11 (PA1), U7.1 (~CS)
/SWCLK: J4.3, U5.37 (PA14/SWCLK)
/SWDIO: J4.2, U5.34 (PA13/SWDIO)
/USART1_RX: U5.31 (PA10), U9.31 (U0TXD)
/USART1_TX: U5.30 (PA9), U9.30 (U0RXD)
/USART2_RX: J10.4, U5.40 (PB4)
/USART2_TX: J10.3, U5.39 (PB3)
/USB_DN: J1.A7 (D-), J1.B7 (D-), U9.26 (IO18/USB_D-)
/USB_DP: J1.A6 (D+), J1.B6 (D+), U9.27 (IO19/USB_D+)
/VBATT: J2.1, L1.2, U1.3 (V_{BAT}), U2.6 (BAT)
/VBAT_RTC: J6.1, U8.14 (VBAT)
GND: C1.2, C2.2, C3.2, C4.2, C5.2, J1.A1 (GND), J1.A12 (GND), J1.B1 (GND), J1.B12 (GND), J1.S1 (SHIELD), J2.2, J4.4, J5.6 (VSS), J6.2, J9.2, J10.2, Q1.2 (S), R1.2, R2.2, R3.2, R7.2, R8.2, SW1.2, SW2.2, U1.2 (V_{SS}), U2.9 (GND), U3.1 (GND), U4.1 (GND), U5.1 (VBAT), U5.8 (VSSA), U5.23 (VSS_1), U5.35 (VSS_2), U5.47 (VSS_3), U6.4 (GND), U7.4 (VSS), U8.5 (GND), U8.6 (GND), U8.7 (GND), U8.8 (GND), U8.9 (GND), U8.10 (GND), U8.11 (GND), U8.12 (GND), U8.13 (GND), U9.1 (GND), U9.2 (GND), U9.11 (GND), U9.14 (GND), U9.36 (GND), U9.37 (GND), U9.38 (GND), U9.39 (GND), U9.40 (GND), U9.41 (GND), U9.42 (GND), U9.43 (GND), U9.44 (GND), U9.45 (GND), U9.46 (GND), U9.47 (GND), U9.48 (GND), U9.49 (GND), U9.50 (GND), U9.51 (GND), U9.52 (GND), U9.53 (GND), U10.2 (PGND), U10.5 (~MUTE), U10.11 (GND), U10.15 (PGND)
VBUS: J1.A4 (VBUS), J1.A9 (VBUS), J1.B4 (VBUS), J1.B9 (VBUS), R4.1, U1.4 (V_{DD})

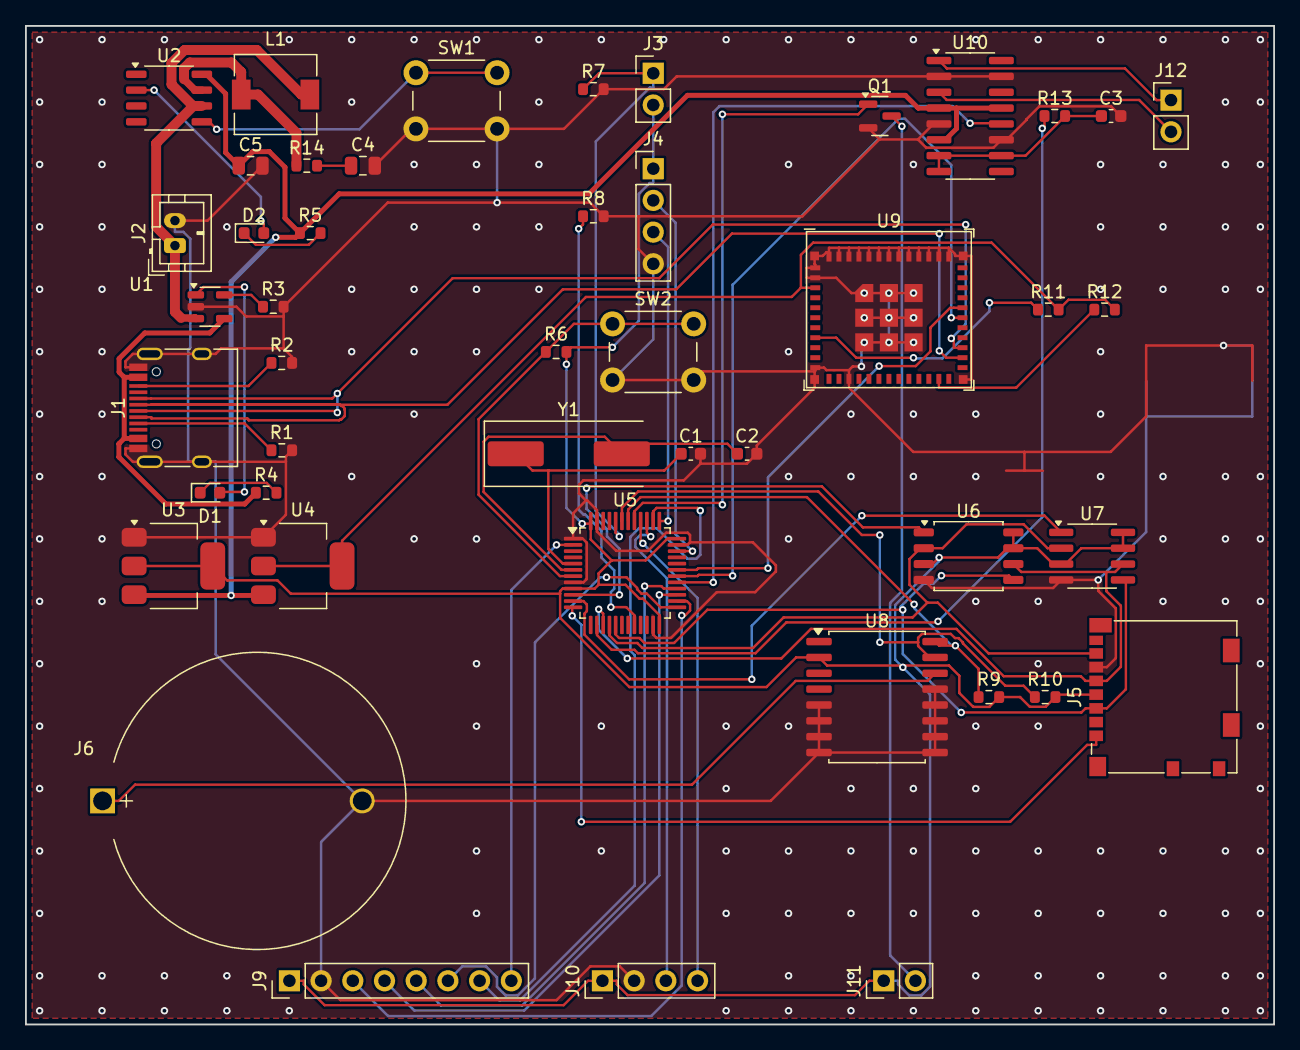
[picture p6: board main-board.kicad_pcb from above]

Board: 2 copper layers, 100.0 x 80.0 mm, 46 parts (0 on the bottom side), 53 nets.

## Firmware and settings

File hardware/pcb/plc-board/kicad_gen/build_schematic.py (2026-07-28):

"""Build hardware/pcb/plc-board/plc-board.kicad_sch -- the PLC/Power Board
(BOM's "Board 1", the PLC Adapter's PCB) schematic, wired per the net plan
in this directory's README.md.

Scope (see README.md's "What this covers, and what it deliberately
doesn't" for the reasoning): mains protection (TVS + MOV), the AC-DC
supply (HLK-5M05), the Terminal power inlet and source ORing, the
supercapacitor hold-up, the 5V->12V boost feeding the ST7580's VCC, the
ST7580's fully-datasheet-specified digital/control/clock/ground pins and
its output current limit, the ESP32-C3-MINI-1 host, and the status LEDs
+ connectors.

The inverter that earlier revisions deferred is not deferred any more --
it is gone. docs/plc-adapter-power.md has the reasoning: the 24V
injection sits well outside EN 50065-1's limits, and its other job
(powering neighbouring adapters) is now done by the Terminal over a
cable. What is left of it is a properly-supplied ST7580 power amplifier.

Still deliberately unbuilt: the PA output network and line coupling.
That now waits on one specific document (ST's AN4068 reference coupling
circuit) rather than on open design questions.
"""

from __future__ import annotations

import schematic
from schematic import Schematic

PROJECT = "plc-board"


def build() -> Schematic:
    lib_text = open("../gridnet_parts.kicad_sym", encoding="utf-8").read()
    sch = Schematic("GRIDNET PLC/Power Board", lib_text, project_name=PROJECT)

    # ------------------------------------------------------------------ #
    # Mains input + protection (Layers 1-2 of docs/electrical-safety.md's
    # three-layer protection circuit -- Layer 3, the relay + optocoupler
    # that isolates the *inverter* from the line, is deferred along with
    # the inverter itself; see README.md)
    # ------------------------------------------------------------------ #

    mains = sch.place(
        "Connector_Generic:Conn_01x02", "J", "MAINS_L_N", 30, 30,
        footprint_override="TerminalBlock:TerminalBlock_Wuerth_691311400102_P7.62mm",
        ref="J1",
    )
    sch.pwr_flag(mains, "1", "AC_L")  # externally sourced from the wall outlet
    sch.pwr_flag(mains, "2", "AC_N")

    tvs = sch.place("Device:D_TVS", "D", "P6KE250CA", 55, 25, footprint_override="Diode_THT:D_5W_P10.16mm_Horizontal", ref="D1")
    sch.net(tvs, "1", "AC_L")
    sch.net(tvs, "2", "AC_N")

    # S20K275: "S20" = 20mm disc; closest real KiCad footprint is the
    # 21.5mm/10mm-pitch one (no exact-20mm option in the bundled library).
    mov = sch.place("Device:Varistor", "RV", "S20K275", 55, 40, footprint_override="Varistor:RV_Disc_D21.5mm_W7.5mm_P10mm", ref="RV1")
    sch.net(mov, "1", "AC_L")
    sch.net(mov, "2", "AC_N")

    # ------------------------------------------------------------------ #
    # AC-DC supply: HLK-5M05, isolated 230VAC -> 5VDC. -Vout becomes this
    # board's logic ground (GND) -- galvanically separate from AC_L/AC_N,
    # per docs/electrical-safety.md's "no direct electrical connection"
    # requirement (isolation is inside the HLK module itself).
    # ------------------------------------------------------------------ #

    psu = sch.place(
        "Converter_ACDC:HLK-5M05", "U", "HLK-5M05", 90, 30,
        footprint_override="Converter_ACDC:Converter_ACDC_Hi-Link_HLK-5Mxx",
        ref="U1",
    )
    sch.net(psu, "1", "AC_L")
    sch.net(psu, "2", "AC_N")
    sch.net(psu, "4", "PSU_5V")
    sch.power_pin(psu, "3", "GND")
    psu_cout = sch.place("Device:C", "C", "220uF", 90, 45, footprint_override="Capacitor_THT:CP_Radial_D8.0mm_P3.50mm", ref="C1")
    sch.net(psu_cout, "1", "PSU_5V")
    sch.power_pin(psu_cout, "2", "GND")

    # ------------------------------------------------------------------ #
    # Terminal power inlet + source ORing (see docs/plc-adapter-power.md)
    #
    # This adapter has no battery. When the grid fails the HLK-5M05 stops,
    # so the Terminal supplies 5V over a detachable USB-C cable instead --
    # see that document for why the energy store lives in the Terminal
    # rather than here, and what that costs.
    #
    # The two sources are ORed with Schottky diodes rather than an
    # ideal-diode controller, consistent with this BOM's price point. The
    # ~0.3V drop leaves ~4.7V, above the boost's input minimum and still
    # enough headroom for the AMS1117 at the ~100mA it supplies.
    #
    # Safety note: this connector sits on the HLK-5M05's isolated secondary,
    # which is also this board's GND. The user handles this cable, so the
    # isolation barrier docs/electrical-safety.md calls non-negotiable is
    # what stands between them and the mains side.
    # ------------------------------------------------------------------ #

    usb = sch.place(
        "Connector:USB_C_Receptacle_USB2.0_14P", "J", "TERMINAL_5V_IN", 30, 60,
        footprint_override="Connector_USB:USB_C_Receptacle_HRO_TYPE-C-31-M-12",
        ref="J4",
    )
    sch.pwr_flag(usb, "A4", "USB_5V")  # externally sourced -- the Terminal's +5V rail
    for p in ("B4", "A9", "B9"):
        sch.net(usb, p, "USB_5V")
    for p in ("A1", "B1", "A12", "B12", "S1"):
        sch.power_pin(usb, p, "GND")
    # Fixed 5.1k "UFP sink" strapping, same as the Terminal's own inlet.
    # This port only ever takes power; there is no USB data on this board.
    cc1 = sch.place("Device:R", "R", "5.1k", 20, 75, footprint_override="Resistor_SMD:R_0603_1608Metric", ref="R9")
    sch.net(usb, "A5", "USB_CC1")
    sch.net(cc1, "1", "USB_CC1")
    sch.power_pin(cc1, "2", "GND")
    cc2 = sch.place("Device:R", "R", "5.1k", 40, 75, footprint_override="Resistor_SMD:R_0603_1608Metric", ref="R10")
    sch.net(usb, "B5", "USB_CC2")
    sch.net(cc2, "1", "USB_CC2")
    sch.power_pin(cc2, "2", "GND")
    for p in ("A6", "B6", "A7", "B7"):
        sch.no_connect(usb, p)  # D+/D- -- power-only inlet, no USB data on this board

    or_psu = sch.place("Device:D_Schottky", "D", "SS34", 70, 60, footprint_override="Diode_SMD:D_SMA", ref="D5")
    sch.net(or_psu, "1", "PSU_5V")
    sch.net(or_psu, "2", "+5V")
    or_usb = sch.place("Device:D_Schottky", "D", "SS34", 70, 70, footprint_override="Diode_SMD:D_SMA", ref="D6")
    sch.net(or_usb, "1", "USB_5V")
    sch.net(or_usb, "2", "+5V")
    # +5V used to be driven straight off the HLK-5M05's output pin. Now both
    # sources reach it through the ORing diodes, which are passive, so no
    # power-output pin sits on the net any more even though it is genuinely
    # driven from two directions. Flagged rather than left as a false error.
    sch.bare_pwr_flag(85, 80, "+5V")

    # ------------------------------------------------------------------ #
    # Supercapacitor hold-up
    #
    # Its job is not to keep the adapter running -- it is to keep the
    # ESP32-C3 alive long enough to tell the Terminal over Wi-Fi that mains
    # has gone, so the Terminal can put "connect the adapter cable" on
    # screen. Usable energy between the 5V rail and the boost's ~3.5V input
    # minimum is 1/2*C*(5^2 - 3.5^2) = 6.4J per farad; a couple of seconds
    # of Wi-Fi activity is well under 1J.
    #
    # It charges through R11 (~500mA inrush limit at 5V) and discharges into
    # the rail through D7, so the resistor is not in the discharge path.
    # ------------------------------------------------------------------ #

    sc_r = sch.place("Device:R", "R", "10R", 100, 60, footprint_override="Resistor_SMD:R_1206_3216Metric", ref="R11")
    sch.net(sc_r, "1", "+5V")
    sch.net(sc_r, "2", "SUPERCAP")
    supercap = sch.place(
        "Device:C_Polarized", "C", "1F 5.5V", 100, 72,
        footprint_override="Capacitor_THT:CP_Radial_D10.0mm_P5.00mm",
        ref="C7",
    )
    sch.net(supercap, "1", "SUPERCAP")
    sch.power_pin(supercap, "2", "GND")
    sc_d = sch.place("Device:D_Schottky", "D", "SS34", 115, 60, footprint_override="Diode_SMD:D_SMA", ref="D7")
    sch.net(sc_d, "1", "SUPERCAP")
    sch.net(sc_d, "2", "+5V")

    # ------------------------------------------------------------------ #
    # 5V -> 12V boost for the ST7580's VCC rail
    #
    # The ST7580 needs 8-18V on VCC for its power amplifier and internal
    # analog regulator (datasheet DocID022644 Rev 2: 8/13/18 V min/typ/max,
    # UVLO 6.1-7.5V). 12V sits mid-window and well clear of the lockout.
    #
    # MT3608 is a real KiCad library part, not a custom symbol. Values come
    # from its own datasheet: VREF = 0.6V and VOUT = VREF*(1 + R1/R2), so 12V
    # needs R1/R2 = 19 -- 19.1k/1k gives 12.06V. Recommended inductor is
    # 4.7-22uH with 22uF ceramic in and out. It is an asynchronous boost, so
    # the rectifier (D8) is external.
    # ------------------------------------------------------------------ #

    boost = sch.place("Regulator_Switching:MT3608", "U", "MT3608", 140, 60, ref="U5")
    sch.power_pin(boost, "5", "+5V")   # IN
    sch.power_pin(boost, "2", "GND")   # GND
    sch.net(boost, "4", "+5V")         # EN -- tied to VIN for automatic startup, per the datasheet pin table
    sch.net(boost, "1", "BOOST_SW")
    boost_l = sch.place("Device:L", "L", "22uH", 130, 50, footprint_override="Inductor_SMD:L_6.3x6.3_H3", ref="L1")
    sch.net(boost_l, "1", "+5V")
    sch.net(boost_l, "2", "BOOST_SW")
    boost_d = sch.place("Device:D_Schottky", "D", "SS34", 155, 50, footprint_override="Diode_SMD:D_SMA", ref="D8")
    sch.net(boost_d, "1", "BOOST_SW")
    sch.net(boost_d, "2", "+12V")
    # +12V reaches the rail through D8, a passive part, so nothing on this
    # sheet looks like a power *output* to ERC even though the rail is
    # genuinely driven. Flagged rather than left as a false error.
    sch.bare_pwr_flag(160, 40, "+12V")
    boost_cin = sch.place("Device:C", "C", "22uF", 125, 70, footprint_override="Capacitor_SMD:C_1206_3216Metric", ref="C8")
    sch.net(boost_cin, "1", "+5V")
    sch.power_pin(boost_cin, "2", "GND")
    boost_cout = sch.place("Device:C", "C", "22uF", 170, 65, footprint_override="Capacitor_SMD:C_1206_3216Metric", ref="C9")
    sch.net(boost_cout, "1", "+12V")
    sch.power_pin(boost_cout, "2", "GND")
    # Bulk on the 12V rail rides transmit bursts so the supply is sized for
    # average draw rather than the PA's peak -- see docs/plc-adapter-power.md.
    boost_bulk = sch.place(
        "Device:C", "C", "100uF", 180, 65,
        footprint_override="Capacitor_THT:CP_Radial_D6.3mm_P2.50mm", ref="C10",
    )
    sch.net(boost_bulk, "1", "+12V")
    sch.power_pin(boost_bulk, "2", "GND")
    fb_top = sch.place("Device:R", "R", "19.1k", 165, 75, footprint_override="Resistor_SMD:R_0603_1608Metric", ref="R12")
    sch.net(fb_top, "1", "+12V")
    sch.net(fb_top, "2", "BOOST_FB")
    fb_bot = sch.place("Device:R", "R", "1k", 165, 85, footprint_override="Resistor_SMD:R_0603_1608Metric", ref="R13")
    sch.net(fb_bot, "1", "BOOST_FB")
    sch.power_pin(fb_bot, "2", "GND")
    sch.net(boost, "3", "BOOST_FB")   # FB

    # ------------------------------------------------------------------ #
    # Status LEDs (Power / PLC / Wi-Fi, per hardware/bom.md's PLC Adapter
    # line items)
    # ------------------------------------------------------------------ #

    pwr_led = sch.place("Device:LED", "D", "LED (green)", 120, 25, footprint_override="LED_THT:LED_D5.0mm", ref="D2")
    pwr_led_r = sch.place("Device:R", "R", "1k", 120, 35, footprint_override="Resistor_THT:R_Axial_DIN0207_L6.3mm_D2.5mm_P10.16mm_Horizontal", ref="R1")
    sch.power_pin(pwr_led, "1", "+5V")
    sch.net(pwr_led, "2", "PWR_LED_R")
    sch.net(pwr_led_r, "1", "PWR_LED_R")
    sch.power_pin(pwr_led_r, "2", "GND")

    plc_led = sch.place("Device:LED", "D", "LED (amber)", 140, 25, footprint_override="LED_THT:LED_D5.0mm", ref="D3")
    plc_led_r = sch.place("Device:R", "R", "1k", 140, 35, footprint_override="Resistor_THT:R_Axial_DIN0207_L6.3mm_D2.5mm_P10.16mm_Horizontal", ref="R2")
    sch.net(plc_led_r, "1", "PLC_LED")
    sch.net(plc_led, "2", "PLC_LED")
    sch.power_pin(plc_led, "1", "+5V")
    sch.power_pin(plc_led_r, "2", "GND")

    # Wi-Fi LED is GPIO-driven (ESP32 IO8), not hardwired, so firmware can
    # blink it for real Wi-Fi status -- unlike Power (always-on) and PLC
    # (driven directly by the ST7580's own activity pin).
    wifi_led = sch.place("Device:LED", "D", "LED (blue)", 160, 25, footprint_override="LED_THT:LED_D5.0mm", ref="D4")
    wifi_led_r = sch.place("Device:R", "R", "330R", 160, 35, footprint_override="Resistor_THT:R_Axial_DIN0207_L6.3mm_D2.5mm_P10.16mm_Horizontal", ref="R3")
    sch.net(wifi_led_r, "1", "WIFI_LED_CTRL")
    sch.net(wifi_led, "2", "WIFI_LED_CTRL")
    sch.power_pin(wifi_led, "1", "+5V")
    sch.net(wifi_led_r, "2", "WIFI_LED_GPIO")

    # ------------------------------------------------------------------ #
    # ESP32-C3-MINI-1 -- Wi-Fi AP for the Terminal connection, UART host
    # for the ST7580, and GPIO control for the status LEDs
    # ------------------------------------------------------------------ #

    esp = sch.place("gridnet_parts:ESP32-C3-MINI-1", "U", "ESP32-C3-MINI-1", 200, 55, ref="U2")
    sch.net(esp, "3", "+3V3")
    for p in ("1", "2", "11", "14", "36", "37", "38", "39", "40", "41", "42",
              "43", "44", "45", "46", "47", "48", "49", "50", "51", "52", "53"):
        sch.power_pin(esp, p, "GND")
    en_r = sch.place("Device:R", "R", "10k", 185, 40, footprint_override="Resistor_SMD:R_0603_1608Metric", ref="R4")
    sch.net(esp, "8", "ESP_EN")
    sch.net(en_r, "1", "ESP_EN")
    sch.net(en_r, "2", "+3V3")
    boot_r = sch.place("Device:R", "R", "10k", 215, 40, footprint_override="Resistor_SMD:R_0603_1608Metric", ref="R5")
    sch.net(esp, "23", "ESP_IO9")
    sch.net(boot_r, "1", "ESP_IO9")
    sch.net(boot_r, "2", "+3V3")

    ldo = sch.place("Regulator_Linear:AMS1117-3.3", "U", "AMS1117-3.3", 175, 55, ref="U3")
    sch.power_pin(ldo, "3", "+5V")
    sch.power_pin(ldo, "1", "GND")
    sch.net(ldo, "2", "+3V3")

    # ESP32 <-> ST7580 UART (host side)
    sch.net(esp, "18", "ST_TXD")   # IO4, ESP RX <- ST7580 TXD
    sch.net(esp, "19", "ST_RXD")   # IO5, ESP TX -> ST7580 RXD
    sch.net(esp, "20", "ST_RESETN")  # IO6
    sch.net(esp, "21", "ST_T_REQ")   # IO7

    sch.net(esp, "22", "WIFI_LED_GPIO")  # IO8, sinks current to light WIFI_LED (active-low)
    for p in ("12", "13", "16", "5", "6"):
        sch.no_connect(esp, p)  # IO0/BOOT_SEL, IO1, IO10, IO2, IO3 -- spare GPIOs
    for p in ("26", "27"):
        sch.no_connect(esp, p)  # IO18/USB_D-, IO19/USB_D+ -- no USB connector on this board

    # UART0 (U0RXD/U0TXD) flashing header -- without this or a USB
    # connector, there would be no way to program the ESP32 at all. Minimal
    # 4-pin header (TX/RX/GND/3V3); putting IO9 (BOOT) into download mode
    # for a first flash is done externally (jumper to GND during power-up),
    # same as most bare ESP32 module carrier boards.
    prog = sch.place(
        "Connector_Generic:Conn_01x04", "J", "ESP32_UART0_PROGRAMMING", 200, 20,
        footprint_override="Connector_PinHeader_2.54mm:PinHeader_1x04_P2.54mm_Vertical",
        ref="J2",
    )
    sch.net(esp, "31", "ESP_U0TXD")
    sch.net(prog, "1", "ESP_U0TXD")
    sch.net(esp, "30", "ESP_U0RXD")
    sch.net(prog, "2", "ESP_U0RXD")
    sch.power_pin(prog, "3", "GND")
    sch.net(prog, "4", "+3V3")

    # ------------------------------------------------------------------ #
    # ST7580 -- well-specified pins only (digital control, clock, all
    # power/ground rails per the datasheet's own Figure 8/9 scheme). The
    # PA/AFE/line-coupling section (PA_OUT, PA_IN+/-, TX_OUT, RX_IN, CL,
    # CL_SEL, ZC_IN) and VCC itself are deliberately left unconnected --
    # see README.md's "What this covers, and what it deliberately doesn't".
    # ------------------------------------------------------------------ #

    st = sch.place("gridnet_parts:ST7580", "U", "ST7580", 300, 90, ref="U4")

    # UART to ESP32
    sch.net(st, "1", "ST_TXD")
    sch.net(st, "2", "ST_RXD")
    sch.net(st, "10", "ST_RESETN")
    sch.net(st, "38", "ST_T_REQ")
    reset_r = sch.place("Device:R", "R", "10k", 270, 60, footprint_override="Resistor_SMD:R_0603_1608Metric", ref="R6")
    sch.net(reset_r, "1", "ST_RESETN")
    sch.net(reset_r, "2", "+5V")  # VDDIO-referenced pull-up; VDDIO == +5V on this board

    # UART baud rate select: BR1=1, BR0=1 -> 57600 (Table 3 of the datasheet)
    br1_r = sch.place("Device:R", "R", "10k", 330, 60, footprint_override="Resistor_SMD:R_0603_1608Metric", ref="R7")
    sch.net(st, "39", "ST_BR1")
    sch.net(br1_r, "1", "ST_BR1")
    sch.net(br1_r, "2", "+5V")
    br0_r = sch.place("Device:R", "R", "10k", 345, 60, footprint_override="Resistor_SMD:R_0603_1608Metric", ref="R8")
    sch.net(st, "40", "ST_BR0")
    sch.net(br0_r, "1", "ST_BR0")
    sch.net(br0_r, "2", "+5V")

    # PL_TX_ON drives the PLC status LED directly (High-Z reset state,
    # digital output, matches the LED's forward current at 5V through 1k)
    sch.net(st, "41", "PLC_LED")
    sch.no_connect(st, "37")  # PL_RX_ON -- one PLC activity signal (TX) is enough, see README.md

    # JTAG debug header, mirroring the Main Board's SWD header pattern
    jtag = sch.place(
        "Connector_Generic:Conn_01x05", "J", "ST7580_JTAG_DEBUG", 300, 140,
        footprint_override="Connector_PinHeader_2.54mm:PinHeader_1x05_P2.54mm_Vertical",
        ref="J3",
    )
    sch.net(jtag, "1", "+5V")
    sch.net(st, "4", "ST_TRSTN")
    sch.net(jtag, "2", "ST_TRSTN")
    sch.net(st, "5", "ST_TMS")
    sch.net(jtag, "3", "ST_TMS")
    sch.net(st, "7", "ST_TCK")
    sch.net(jtag, "4", "ST_TCK")
    sch.net(st, "9", "ST_TDI")
    sch.net(jtag, "5", "ST_TDI")
    sch.net(st, "8", "ST_TDO")
    sch.no_connect(st, "8")  # TDO left off the 5-pin header (debug-in only); see README.md

    # Reserved pins, per the datasheet's own pin table
    for p in ("31", "42", "43", "44", "48"):
        sch.net(st, p, "+5V")  # "pull up to VDDIO" -- tied directly, same net either way
    sch.net(st, "47", "+5V")  # "connect to VDDIO"
    for p in ("29", "30", "32"):
        sch.no_connect(st, p)  # NC

    # Power/ground scheme -- Figure 8 (supply structure) + Figure 9
    # (ground scheme) of the datasheet, reproduced exactly.
    for p in ("3", "28", "34"):
        sch.net(st, p, "+5V")  # VDDIO x3
    for p in ("6", "14", "33", "45"):
        sch.power_pin(st, p, "GND")  # GND x4 (digital ground)

    # VSSA/VSS/exposed-pad analog-ground island, bridged to digital GND
    # through a ferrite bead (Figure 9) rather than tied directly.
    sch.net(st, "15", "ST_VSSA")
    sch.net(st, "35", "ST_VSSA")
    sch.net(st, "25", "ST_VSSA")  # VSS
    sch.net(st, "49", "ST_VSSA")  # exposed pad
    fb1 = sch.place("Device:FerriteBead", "FB", "FB", 340, 100, footprint_override="Inductor_SMD:L_0805_2012Metric", ref="FB1")
    sch.net(fb1, "1", "ST_VSSA")
    sch.power_pin(fb1, "2", "GND")
    # ST_VSSA is a real ground (bridged to GND above), just not via a power
    # symbol ERC recognizes on this net directly -- flagged so ERC doesn't
    # read ST7580's own analog-ground pins as "undriven".
    sch.bare_pwr_flag(350, 95, "ST_VSSA")

    # VDD / VDD_REG_1V8 -- internally generated from VDDIO, each pin is a
    # local filter tap only ("external connections between all VDD pins
    # are not required" -- datasheet Section 6). Three independent nets,
    # each with its own decoupling cap, exactly per that section.
    vdd_a_c = sch.place("Device:C", "C", "100nF", 280, 110, footprint_override="Capacitor_SMD:C_0603_1608Metric", ref="C2")
    sch.net(st, "11", "ST_VDD_A")
    sch.net(vdd_a_c, "1", "ST_VDD_A")
    sch.power_pin(vdd_a_c, "2", "GND")
    vdd_b_c = sch.place("Device:C", "C", "100nF", 320, 110, footprint_override="Capacitor_SMD:C_0603_1608Metric", ref="C3")
    sch.net(st, "46", "ST_VDD_B")
    sch.net(vdd_b_c, "1", "ST_VDD_B")
    sch.power_pin(vdd_b_c, "2", "GND")
    vdd_reg_c = sch.place("Device:C", "C", "100nF", 300, 115, footprint_override="Capacitor_SMD:C_0603_1608Metric", ref="C4")
    sch.net(st, "27", "ST_VDD_REG_1V8")
    sch.net(vdd_reg_c, "1", "ST_VDD_REG_1V8")
    sch.power_pin(vdd_reg_c, "2", "GND")
    # ST_VDD_A/B/REG_1V8 are all fed by ST7580's own internal 1.8V LDO (from
    # VDDIO) -- "not designed to supply external circuitry... accessible
    # for filtering purposes only" (datasheet Section 6). Flagged so ERC
    # doesn't read these internally-generated rails as undriven.
    sch.bare_pwr_flag(280, 105, "ST_VDD_A")
    sch.bare_pwr_flag(320, 105, "ST_VDD_B")
    sch.bare_pwr_flag(300, 105, "ST_VDD_REG_1V8")

    # VDD_PLL: ferrite bead from VDD (pin 11's local rail) + its own
    # decoupling cap referenced to VSSA (both per Figure 8).
    fb2 = sch.place("Device:FerriteBead", "FB", "FB", 280, 120, footprint_override="Inductor_SMD:L_0805_2012Metric", ref="FB2")
    sch.net(fb2, "1", "ST_VDD_A")
    sch.net(st, "16", "ST_VDD_PLL")
    sch.net(fb2, "2", "ST_VDD_PLL")
    vdd_pll_c = sch.place("Device:C", "C", "100nF", 290, 125, footprint_override="Capacitor_SMD:C_0603_1608Metric", ref="C5")
    sch.net(vdd_pll_c, "1", "ST_VDD_PLL")
    sch.net(vdd_pll_c, "2", "ST_VSSA")
    sch.bare_pwr_flag(290, 130, "ST_VDD_PLL")  # fed from ST_VDD_A through FB2, same reasoning

    # VCCA: local decoupling to VSSA only, no external drive (internally
    # generated from VCC, which this design doesn't supply -- see below).
    vcca_c = sch.place("Device:C", "C", "1uF", 320, 120, footprint_override="Capacitor_SMD:C_0805_2012Metric", ref="C6")
    sch.net(st, "17", "ST_VCCA")
    sch.net(vcca_c, "1", "ST_VCCA")
    sch.net(vcca_c, "2", "ST_VSSA")
    sch.bare_pwr_flag(320, 125, "ST_VCCA")  # internally generated from VCC, same reasoning
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

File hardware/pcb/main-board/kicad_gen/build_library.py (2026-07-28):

"""Assemble hardware/pcb/main-board/gridnet_parts.kicad_sym — the
project-local symbol library for the Main Board schematic.

Combines:
  (a) exact symbol blocks copied programmatically from KiCad's own bundled
      libraries (no hand-retyping -> no transcription risk) for parts that
      have a real or pin-compatible match there, and
  (b) custom-built generic-rectangle symbols (see make_symbol.py) for parts
      with no library match, each explicitly flagged for datasheet
      verification before this design is used for real layout/fab.

See README.md in this directory for the per-part confidence/rationale
writeup this file's choices are based on.
"""

from __future__ import annotations

import re

import sexp
from make_symbol import Pin, build_symbol

KICAD_SYMBOLS_DIR = "/usr/share/kicad/symbols"

HEADER = """(kicad_symbol_lib
\t(version 20241209)
\t(generator "gridnet_build_library")
\t(generator_version "9.0")
"""
FOOTER = ")\n"


def load(lib_file: str) -> str:
    return open(f"{KICAD_SYMBOLS_DIR}/{lib_file}.kicad_sym", encoding="utf-8").read()


def extract_real(lib_file: str, symbol_name: str, rename_to: str | None = None) -> str:
    text = load(lib_file)
    block = sexp.find_symbol_block(text, symbol_name)
    if rename_to and rename_to != symbol_name:
        # Only rename the top-level symbol name and its two sub-unit names
        # (name_0_1 / name_1_1), not any unrelated occurrence of the string.
        block = block.replace(f'(symbol "{symbol_name}"', f'(symbol "{rename_to}"', 1)
        block = block.replace(f'"{symbol_name}_0_1"', f'"{rename_to}_0_1"')
        block = block.replace(f'"{symbol_name}_1_1"', f'"{rename_to}_1_1"')
        # Update the Value property text (2nd property block) to match
        block = block.replace(f'(property "Value" "{symbol_name}"', f'(property "Value" "{rename_to}"', 1)
    return sexp.indent(block, 1)


def extract_flatten_extends(lib_file: str, symbol_name: str) -> str:
    """For a symbol defined via `(extends "BASE")` -- KiCad's way of
    inheriting a base symbol's graphics/pins -- build a fully self-contained
    copy instead: this symbol's own properties + the base's graphical
    sub-units, `extends` reference dropped. Simpler and more robust than
    keeping the extends relationship consistent once symbol names get
    requalified inside a schematic's lib_symbols cache (which is exactly
    where this bit us: a renamed derived symbol's `(extends "BASE")` no
    longer matched the base's own renamed cache entry)."""
    text = load(lib_file)
    derived = sexp.find_symbol_block(text, symbol_name)
    m = re.search(r'\(extends "([^"]+)"\)', derived)
    if not m:
        return sexp.indent(derived, 1)
    base_name = m.group(1)
    base = sexp.find_symbol_block(text, base_name)
    base_sub_0 = sexp.find_symbol_block(base, f"{base_name}_0_1").replace(
        f'"{base_name}_0_1"', f'"{symbol_name}_0_1"', 1
    )
    base_sub_1 = sexp.find_symbol_block(base, f"{base_name}_1_1").replace(
        f'"{base_name}_1_1"', f'"{symbol_name}_1_1"', 1
    )
    derived_no_extends = re.sub(r'\n\s*\(extends "[^"]+"\)\n', "\n", derived, count=1)
    body = derived_no_extends.rstrip()
    assert body.endswith(")")
    body = body[:-1]  # drop the final closing paren -- we'll re-add it after splicing in the base's graphics
    flattened = body + sexp.indent(base_sub_0, 2) + "\n" + sexp.indent(base_sub_1, 2) + "\n\t)\n"
    return sexp.indent(flattened, 1)


def main() -> None:
    parts = []

    # --- Real / pin-compatible library parts, copied exactly ---------- #

    # AMS1117-3.3 extends AP1117-15 in KiCad's library -- flattened to a
    # single self-contained symbol, see extract_flatten_extends().
    parts.append(extract_flatten_extends("Regulator_Linear", "AMS1117-3.3"))

    # W25Q series shares one SOIC-8 pinout across densities (Winbond
    # datasheet family) -- reuse W25Q32JVSS's real, verified pin layout,
    # relabeled to our actual BOM part (W25Q64JVSSIQ, 8MB).
    parts.append(extract_real("Memory_Flash", "W25Q32JVSS", rename_to="W25Q64JVSSIQ"))

    # DS3231M substituted for the BOM's original DS3231SN -- see README.md:
    # same SCL/SDA/VBAT/32KHZ/INT-SQW/RST functionality, smaller/cheaper
    # package, real KiCad library part with a verified pinout.
    parts.append(extract_real("Timer_RTC", "DS3231M"))

    parts.append(extract_real("Battery_Management", "MCP73831-2-OT"))
    parts.append(extract_real("Amplifier_Audio", "PAM8403D"))

    # --- Custom generic-rectangle symbols (NEEDS DATASHEET VERIFICATION) #

    parts.append(
        build_symbol(
            name="23LC1024",
            reference="U",
            footprint="Package_SO:SOIC-8_3.9x4.9mm_P1.27mm",
            description="Microchip 1Mbit SPI serial SRAM, SOIC-8 -- pinout verified against the real Microchip 23A1024/23LC1024 datasheet (DS20005142C)",
            datasheet="https://ww1.microchip.com/downloads/en/DeviceDoc/20005142C.pdf",
            verified=True,
            pins=[
                Pin("1", "~{CS}", "in", "left"),
                Pin("5", "SI/SIO0", "bidi", "left"),
                Pin("6", "SCK", "in", "left"),
                Pin("4", "VSS", "pwr", "left"),
                Pin("2", "SO/SIO1", "bidi", "right"),
                Pin("3", "~{WP}/SIO2", "bidi", "right"),
                Pin("7", "~{HOLD}/SIO3", "bidi", "right"),
                Pin("8", "VDD", "pwr", "right"),
            ],
        )
    )

    parts.append(
        build_symbol(
            name="IP5306",
            reference="U",
            footprint="Package_SO:SOP-8_3.9x4.9mm_P1.27mm",
            description="Boost converter + Li-ion charge/battery management IC (common power-bank IC) -- pinout verified against the real Injoinic IP5306 datasheet (V1.3): VIN/LED1/LED2/LED3/KEY/BAT/SW/VOUT + PowerPAD-as-GND, eSOP8",
            datasheet="https://datasheet.lcsc.com/lcsc/2304140030_INJOINIC-IP5306_C181692.pdf",
            verified=True,
            pins=[
                Pin("1", "VIN", "pwr", "left"),  # 5V charge input
                Pin("2", "LED1", "out", "left"),
                Pin("3", "LED2", "out", "left"),
                Pin("4", "LED3", "out", "left"),
                Pin("5", "KEY", "in", "right"),  # push-button control
                Pin("6", "BAT", "pwr", "right"),
                Pin("7", "SW", "pas", "right"),  # DCDC switch node -- external inductor to VOUT
                Pin("8", "VOUT", "pwr_out", "right"),  # 5V boost output
                Pin("9", "GND", "pwr", "left"),  # exposed PowerPAD, not a numbered lead -- see README.md
            ],
        )
    )
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

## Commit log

2026-07-17 protocol: add reference simulator, fix inverter-master REV 0.5
    tools/protocol-sim/ is a pure-Python, hardware-independent discrete-event
    reference implementation of docs/protocol.md and docs/inverter-master.md:
    packet framing, mesh flooding/store-and-forward, and the full inverter
    master election state machine, with 8 runnable scenarios and 28 tests.
    Running it surfaced two real protocol gaps in REV 0.4, not simulator bugs:
    - A flat 2s listen delay with no jitter made split-brain the common case
    for segment-wide outages (every device timed out at the same instant),
    not a rare fallback.
    - A new device joining an existing segment reused that same 2s window,
    giving it only ~20% odds of h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
2026-07-17 firmware: add core Forth VM prototype
    tools/forth-vm/ is the language-semantics prototype for the sandboxed
    Forth VM described in docs/firmware-arch.md and docs/protocol.md's
    Forth Application Protocol — core language only for now (stacks,
    dictionary, arithmetic, control flow, variables), no screen/keyboard/
    sandbox words yet.
    Deliberate scope choices, documented in forth_vm/vm.py's module docstring:
    colon definitions compile to nested Python tuples rather than linear
    threaded code with branch offsets (easier to get right and test; the
    embedded port will need the flat form for its ~2KB RAM budget), and word
    calls resolve by dictionary lookup at execution time rather than binding
    at compil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
2026-07-18 hardware: fix five BOM part mismatches, REV 0.5
    Component-level review of hardware/bom.md turned up five REV 0.4 choices
    that don't hold up against their own datasheets/module specs:
    1. Display: ILI9488 tops out at 480x320 and cannot drive the specified
    800x480 resolution at all. Even a corrected driver needs a second fix —
    GD32VF103 has no LTDC/RGB peripheral and nowhere near enough RAM (32KB
    on-chip + 128KB SPI SRAM vs. 384KB needed) to hold an 800x480 frame
    buffer itself. Replaced with an RA8875-based module, which carries its
    own onboard SDRAM and talks to the host over SPI a command at a time.
    2. Wi-Fi module: ESP32-C3-MINI-1 has an onboard PCB antenna and no
    connec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
2026-07-18 docs: fix stale/broken content on the main README
    Verified every factual claim on the repo's main page against the actual
    codebase and file tree; five things didn't hold up:
    - The flagship Forth example didn't run at all: bare `" ..."` string
    literals aren't valid in the actual VM (only `."` and `S"` are — see
    tools/forth-vm), so calling ORDER failed with `? "` (unknown word).
    Confirmed by executing the exact snippet against tools/forth-vm before
    and after the fix. Also fixed `KEY? SEND-MSG`, which doesn't work either
    — KEY? is a boolean check, not "the key pressed" — to the working
    `KEY? IF KEY ... SEND-MSG THEN` (already correct in tools/forth-vm's own
    README, just nev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
2026-07-18 docs: correct Project Status — PCB layout and case design aren't done
    Verified against the repo's actual git history: the entire repo traces
    back to a single initial commit (50ebecf) that never included a
    hardware/pcb/ or hardware/case/ directory, and no PCB/CAD file (KiCad,
    Gerber, .step, .stl, or otherwise) has ever existed anywhere in this
    repo. hardware/schematics/README.md already says schematics are "in
    preparation" — layout can't be done without a schematic to route from,
    so "PCB layout plan: Complete" was never coherent regardless of file
    presence. The BOM's board sizes and the README's case dimensions are
    cost-estimate targets, not outputs of an actual layout/CAD process.
    Chang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
2026-07-18 hardware: add KiCad schematic for the Main Board
    Programmatically generated (kicad_gen/), ERC-clean (423 benign
    warnings, 0 errors) schematic covering the full Board 2 circuit from
    hardware/bom.md: power tree, GD32VF103CCT6 MCU with clock/reset/boot/
    SWD, SPI flash + SRAM + microSD + RTC, ESP32-C3-MINI-1U wireless with
    antenna path, and off-board connectors for display/keyboard/backlight/
    speaker.
    README.md documents per-part confidence (real KiCad library parts vs.
    four custom-built symbols still needing datasheet pin verification),
    design assumptions, the net plan, and how to regenerate/validate.
    Claude-Session: https://claude.ai/co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
    [main-board.kicad_sch]
2026-07-19 hardware: add PCB component placement for the Main Board
    Adds main-board.kicad_pcb: every part from the schematic placed within
    the 100x80mm board outline (hardware/bom.md's Board 2 spec), on the
    correct nets (full ratsnest), courtyard-overlap/shorting/clearance clean
    per kicad-cli pcb drc. No copper routing yet -- that's manual follow-on
    work in the KiCad GUI (no autorouter available here).
    Placement (kicad_gen/build_pcb.py) is computed from each footprint's real
    measured courtyard geometry via pcbnew, not guessed -- a first hand-placed
    attempt produced 7 courtyard overlaps once real sizes were checked (the
    CR2032 holder alone is 27x24mm). Also fixes a footprint-anchor bug found
    along the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
    [main-board.kicad_pcb, main-board.kicad_sch]
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2026-07-25 hardware: diagnose the /DISP_CS routing holdout, rule out the LQFP pitch
    Followed up on Freerouting's one unrouted net with an independent
    clearance-aware pathfinder to double-check its "stuck" verdict rather
    than just re-running the autorouter. Result: the LQFP48 pin pitch
    (the obvious suspect) isn't actually the blocker — real clearance
    there is a tight but valid ~0.05mm once modeled correctly. The real
    blocker is /+3V3_MCU branching somewhere else on the board, which
    means finishing this trace needs KiCad's interactive router, not a
    single-segment nudge.
2026-07-25 hardware: fix real pin-number bugs found by datasheet verification
    Checked all four custom part symbols (23LC1024, GD32VF103CCT6,
    ESP32-C3-MINI-1U, IP5306) against their primary-source datasheets.
    23LC1024 was already correct. The other three were substantially
    wrong, not just unverified:
    - GD32VF103CCT6: 35 of 48 pins (14-48) numbered wrong -- two spurious
    power-pin insertions shifted everything after them.
    - ESP32-C3-MINI-1U: the symbol numbered its 19 signal pins 1-19
    sequentially; the real 53-pad module has GND/NC scattered through
    that range, so almost nothing lined up.
    - IP5306: all 8 pins wrong, plus LED3 and SW (the boost converter's
    inductor node) were missing entirely, and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
    [main-board.kicad_sch]
2026-07-25 hardware: regenerate the Main Board PCB against the corrected netlist
    The previous PCB was routed against the pre-datasheet-fix netlist, so
    its net-to-pad assignments on the MCU, ESP32-C3 module, and IP5306
    were wrong, not just stale. Regenerated from scratch: fresh netlist
    export, fresh placement (build_pcb.py), fresh Freerouting pass.
    Freerouting completed 170 of 171 nets; the one holdout was /USB_DN
    (J1's two D- pins, 1mm apart with /USB_DP's pad physically between
    them) rather than /DISP_CS this time -- /DISP_CS routed cleanly once
    it was routing the pad that's actually /DISP_CS now (pad 25, not the
    old netlist's pad 27). Finished /USB_DN by hand: the west side of the
    connector was alre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
    [main-board.kicad_pcb]
2026-07-26 hardware: add the IP5306's missing boost inductor
    Datasheet verification (previous commit) found the IP5306's SW pin
    (the boost converter's switch node) was wired to nothing -- the boost
    path (BAT -> VOUT) couldn't function without an inductor there, and
    none existed anywhere in this design.
    Fixed per the IP5306 datasheet's own "Typical Application Schematic"
    (Figure 7): a 1uH inductor (L1) bridges SW to BAT directly, not to
    VOUT as an earlier read of this design assumed -- it's shared between
    the buck charger and boost discharger. Added the reference circuit's
    RC snubber (R14 0.5R + C4 22uF) on the SW node and a VOUT decoupling
    cap (C5, simplified from the datasheet's 4-cap bank to one).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
    [main-board.kicad_pcb, main-board.kicad_sch]
2026-07-26 hardware: replace the ESP32-C3-MINI-1U placeholder with its real footprint
    The datasheet verification pass (two commits back) fixed the schematic
    symbol's pin numbers but left the PCB footprint as the same-family
    RF_Module:ESP32-C3-WROOM-02U placeholder. Rather than hand-transcribe
    a 53-pad castellated land pattern off the datasheet's dimension
    drawing -- error-prone, and exactly the kind of mistake this whole
    verification effort exists to catch -- vendored the real footprint
    from Espressif's official KiCad library (CC-BY-SA 4.0, same terms as
    KiCad's own libraries) into a new gridnet_footprints.pretty/, with
    build_pcb.py gaining a small local-footprint-library lookup to load
    it. Verified be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
    [main-board.kicad_pcb, main-board.kicad_sch]
2026-07-26 hardware: ground the ESP32-C3-MINI-1U's remaining GND/thermal pads
    The real footprint swapped in last commit has ~22 GND pin numbers
    (30 physical pads once the pin-49 thermal array's 9 copper islands
    are counted), but the schematic symbol only drew and wired 2 of them
    -- flagged as a follow-up rather than fixed at the time.
    Fixed: kicad_gen/build_library.py's ESP32-C3-MINI-1U symbol now draws
    every real GND pin from the datasheet's Table 3-1 (1, 2, 11, 14,
    36-53), wired to GND in build_schematic.py. Only the module's 14
    genuinely NC pads stay undrawn -- there's nothing to connect them to.
    Espressif's hardware design guidelines recommend grounding all GND
    pads (not just a couple) for this mo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
    [main-board.kicad_pcb, main-board.kicad_sch]
2026-07-26 hardware: add the PLC/Power Board schematic (Board 1)
    First schematic pass for Board 1 -- confirmed with the user first that
    this is the same PCB as the PLC Adapter (hardware/bom.md lists them as
    separate line items, but the top-level README's Hardware Overview only
    describes two products, and Board 1's component list matches the
    Adapter's hardware table exactly). Fixed two BOM inconsistencies this
    surfaced: the Adapter's enclosure was sized for a smaller PCB than
    Board 1 actually is, and J1's "main board interface" description read
    as if it connected to Board 2 (it doesn't -- the two boards never
    connect to each other).
    Datasheet-verified the two custom parts before building anything, same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
    [plc-board.kicad_sch]
2026-07-26 hardware: pre-fab design review of the Main Board, REV 0.7
    Ran the design-review pass the Project Status table has been calling the
    next step. Four findings on the board and one on the tooling.
    Reference-designator drift. build_schematic.py auto-numbered refdes by
    call order while build_pcb.py's PLACEMENT dict is keyed by refdes, so
    adding the IP5306's inductor and snubber (615f5d2) renumbered every
    later R and C by +1 and silently built a dozen parts into each other's
    board positions. Measured on the committed board: the 8MHz crystal's
    20pF load caps were 51mm and 34mm from the crystal, the IP5306's 22uF
    snubber and VOUT caps were ~50mm from the IC, the audio filter's R and C
    were 61mm and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
    [main-board.kicad_pcb, main-board.kicad_sch]
2026-07-28 hardware: power the PLC Adapter from the Terminal, remove the inverter
    Board 1's remaining gaps were meant to be a power-electronics design task:
    supply the ST7580's 8-18V VCC, drive the IRF540N inverter, define its
    topology. Two findings made those questions the wrong ones.
    The adapter had no power source during an outage. Its only supply is the
    HLK-5M05, which needs 90-264V AC. When the grid fails the adapter stops --
    so it could never have run an inverter, and the 24V it was supposed to
    inject could not have powered a neighbouring adapter either, despite
    docs/inverter-master.md stating that a slave "listens on the wire powered
    by the master's 24V injection". hardware/bom.md gives Board 1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
    [plc-board.kicad_sch]
2026-07-28 hardware: remove the Main Board's antenna path, fix the stitching grid
    This pass set out to do the item that headed the Main Board's "What's not
    done yet": controlled-impedance layout for the 2.4GHz antenna path. There
    is no antenna path. `/ANT_RF` has no `U9` pad on it -- the net was two
    connectors wired to each other, with nothing driving them.
    The ESP32-C3-MINI-1U does not bring its radio out to a castellated pad.
    Datasheet v2.2 Table 3-1 lists all 53: pins 1, 2, 11, 14 and 36-53 are
    GND, the rest are 3V3, EN and IO. The radio leaves through the antenna
    jack mounted on the module -- that is what the "U" in -1U means. So:
    - build_library.py's symbol carried a pin whose *number* was the s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
    [main-board.kicad_pcb, main-board.kicad_sch, plc-board.kicad_sch]
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2026-07-29 hardware: make Board 1 four layers, and build the routing pipeline
    Board 1 is a four-layer board, and not for signal density -- it could very
    nearly be routed on two. It is four because of what has to be planed.
    L1 F.Cu signals, all components
    L2 In1.Cu GND plane (4984 mm2, isolated side only)
    L3 In2.Cu +5V plane (4960 mm2, isolated side only)
    L4 B.Cu signals
    The ST7580 puts nine +5V pads on three edges of a 48-pin 0.5mm-pitch package.
    Nothing passes between adjacent pads there -- a 0.2mm track with 0.2mm
    clearance needs 0.6mm and the gap is 0.25mm -- so every pin escapes radially
    and those nine have to find each other around the outside of eleven other
    escapes. Fou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
    [plc-board.kicad_pcb, plc-board.kicad_sch]
2026-07-29 hardware: a routing pass on Board 1, and six defects it found
    Routing does not finish. Every run still ends one connection short. What the
    pass found is worth more than the routing would have been: six separate
    defects stood between this board and a routed one, and each was invisible
    until the router hit it.
    The QFN's power pins had no fanout. The ST7580 puts nine +5V pads on three
    edges of a 48-pin 0.5mm-pitch package; nothing passes between adjacent pads
    there, so each escapes radially and the router then has to bring nine radial
    escapes back together around the outside of eleven others. Every run this
    project had made died on that -- with planes declared up front it was the
    top-left corn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
    [plc-board.kicad_pcb, plc-board.kicad_sch]
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2026-08-01 docs: a threat model, and the three things authentication won't fix
    The protocol had no authentication and no statement of what that cost.
    This writes down who GRIDNET defends against, who it does not, and the
    decisions that follow. Nothing is implemented -- protocol.md still
    specifies the unauthenticated wire format.
    Scope is deliberately narrow: a hostile neighbour on the same wire.
    Someone in the building who flashes their own firmware and transmits
    arbitrary frames. Device theft, a resourceful targeted adversary,
    confidentiality, traffic analysis and jamming are all out of scope and
    each is listed with the consequence of leaving it there, because
    "undefended" is only an honest position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
2026-08-01 docs: ROUTE doesn't scale, and the medium was already telling us why
    A full-size ROUTE advertisement is 913ms on air at 2.4 kbps, and every
    device broadcasts its own full table every 60 seconds. Twenty nodes on
    one distribution segment therefore spend 30.4% of the channel on routing
    before a single message is sent -- and CSMA/CA collapses well before
    100% offered load, so that is not 30% of capacity, it is most of it.
    Signatures are not the cause. Adding them takes 20 nodes from 30.4% to
    37.6%. A 255-byte table on a 60s timer over a 2.4 kbps link is the cause.
    Working out the fix turned up that this project has never written down
    what topology it is designing for. That assumption is load-b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
2026-08-01 docs: the mesh isn't a fallback, and the phases were never counted
    protocol.md ranked the channels -- powerline first, WiFi mesh second,
    used when the "line [is] damaged or PLC failed". The README says the
    same. Working out how segments join showed that ranking is the wrong
    model entirely.
    PLC reaches electrical neighbours. The mesh reaches physical ones.
    Neither set contains the other, so neither can be the other's fallback.
    The sharp edge is phase, which no document in this project had
    mentioned. LV distribution is three-phase and households sit on one of
    L1/L2/L3; this Adapter couples L-to-N through a Schuko plug, so it
    transmits on one phase. Cross-phase coupling exists through the
    tra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
2026-08-01 docs: Project Status said the protocol stack was complete
    It wasn't, and this project's own documents now say so in three separate
    places. Leaving a green tick above them is the same class of error the
    rest of this work has been correcting -- a status table describing an
    intention rather than the state.
    - Communication protocol stack: complete -> under revision, naming all
    three faults and linking each to the document that establishes it. It
    does not scale (routing.md), it has no authentication (threat-model.md),
    and its channel model ranks the mesh as a fallback for the powerline
    when the two reach different sets of nodes (channels.md). Each has a
    decided design and none is imple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
2026-08-01 docs: SEQ becomes 4 bytes, and the ROUTE wrapper restated its own header
    Two wire-format items, settled before the format freezes.
    SEQ was 2 bytes, sized for duplicate suppression during flooding -- a
    window measured in seconds. It wraps far faster than anything that
    outlives that window:
    5 packets/s (the Forth app rate limit) 3.6 hours
    10 packets/min 4.6 days
    Store-and-forward retains messages for 7 days. At any plausible send
    rate a stored message outlives the counter that identifies it, so its
    SEQ may have been reused before delivery. That breaks ordering and makes
    a replay indistinguishable from a legitimate retransmission -- a
    correctness problem b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
2026-11-09 hardware: WIP -- why Board 1's routing always ended one connection short
    Not verified yet; a full route.sh run with these changes is in progress.
    - finish_routing.py stopped at the first pair it could not repair, so
    "one connection short" was the first hard gap, not the last: the board
    behind one such report still had nine. Hard pairs are now set aside and
    retried after progress, and every remaining gap is listed on failure.
    - Its neighbourhood rip-up only looked around the pair's second end; on
    every REV 0.6 run the stranded end was the first (U4 pins 39 and 41).
    Both ends are tried now, pad first. Planed neighbours (GND, +5V) lose
    only their local copper instead of being re-ro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
2026-11-09 hardware: WIP -- refill zones from a fresh board load
    After items are removed, KiCad 9's binding returns board.Zones() as bare
    SwigPyObjects and the process segfaults on exit; refill from a reload.
    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
2026-11-09 hardware: WIP -- move R6 and C15 off U4's top-edge escape band
    R6 sat 0.4mm above U4's pins 3-8, leaving 1.35mm for two fanout vias and
    the five JTAG signals plus RESETN heading for J3; every attempt on that
    placement ended with one of those six unrouted. C15 sat across pins 9-12,
    far from the Rx tank it belongs to (RX_IN is pin 19, on the left edge).
    R6 moves up and left of the pins; C15 moves beside R20 and L2. Placement
    DRC: no errors. Also fixes the BR0/BR1 comment (right edge, not top).
    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
2026-11-09 hardware: WIP -- experiment flag to skip fanout on pads between two signals
    FANOUT_SKIP_SANDWICHED=1 leaves a lone planed pad with signal pads on both
    sides to the router: its in-line via traps a neighbour that must cross the
    stub (U4 pin 4, /ST_TRSTN, beside pin 3's +5V via). Off by default; being
    measured.
    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
2026-11-09 hardware: WIP -- measure the edge from Edge.Cuts; count progress as fewer gaps
    GetBoardEdgesBoundingBox() includes the outline's line width and sits
    0.075mm outside the real edge, so a Freerouting track 0.465mm from the top
    passed the strip and the repair router itself laid track 0.45mm from it.
    The outline now comes from the Edge.Cuts shapes (0,0)-(100,80); on the
    stuck board that strips twelve offending segments.
    A repair that reports success but leaves its gap in DRC used to count as
    progress, clear the set-aside list and re-run every rip-up behind it (six
    times in one run for /ST_VDD_A). Progress is now fewer gaps than ever
    before, and such a gap is set aside.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
2026-11-09 hardware: WIP -- a 0.15mm escape rule around U4, and only there
    At 0.2/0.2 U4's signals cannot leave the package: pins 4 and 5 sit between
    fanout vias whose copper is 0.9mm apart and two tracks need 1.0mm, and
    adjacent pins cannot fan out at 45 degrees (0.354mm against 0.4mm). Every
    attempt ended with one to four of U4's signals unrouted, only ever U4's.
    - A named rule area U4_ESCAPE (courtyard + 3mm) and a custom DRC rule in
    plc-board.kicad_dru drop clearance to 0.15mm inside it. Verified: 0.15mm
    inside passes, the same pair far outside fails against 0.2mm.
    - U4's signal nets form an Escape netclass: 0.15mm wide, 0.2mm clearance.
    PA_OUT and VSSA stay at Default width; they carry the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
2026-11-09 hardware: WIP -- dogleg fanout into an NC row; stitch orphan pour islands
    With the escape rule, run G's first attempt routed every U4 signal and
    ended on one gap: U4 pin 33 (GND), which got no fanout and sat in a 3.3mm2
    F.Cu pour island with no via.
    - Fanout: when straight out fails, a lone pad may dogleg into a neighbour
    row that carries no net -- out past the pad end, 45 degrees across half
    or one pitch, out to the via. Pin 33 sits between pin 31's and pin 34's
    +5V stubs, 1.5mm apart; its via now lands midway, by NC pin 32's row.
    All 13 of U4's power pads have a fanout (10 vias). Legs that cross a
    row are checked against every pad.
    - Repair: an orphan pad whose island has no leg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
2026-11-09 hardware: WIP -- route through other copper and lift only what is crossed; clean up
    The neighbourhood rip-up re-routes every neighbour from scratch, and around
    U4 it kept failing on one neighbour that could not get back in (/ST_VSSA,
    then /ST_RESETN). Two changes:
    - Neighbours with more than six pads (/ST_VSSA: the exposed pad and every
    analog decoupling cap) are cut locally like the planes, not re-routed.
    - lift_route(): A* that treats other nets' unlocked copper as passable at a
    cost, then lifts exactly the segments the route comes within clearance
    of; their cut ends are repaired as ordinary gaps. Planed nets try a via
    to their plane first. On run I's stuck board (/ST_TMS) this cl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
2026-11-09 hardware: route Board 1 end to end -- DRC 0 errors, 0 unconnected
    The routed board, produced by route.sh from placement in one pass on the
    code in this branch: 742 track segments and 174 vias on F.Cu/B.Cu, both
    planes poured, DRC 0 errors and 0 unconnected, isolation barrier clean on
    copper. The two remaining DRC warnings are U4 exposed-pad thermal vias on
    /ST_VSSA, which land on no plane -- a design question, recorded as such.
    Also adds plc-board.kicad_dru (the U4 fine-pitch escape rule) and the
    Escape netclass in the project file, and records REV 0.7 in the board
    README and the top-level status table. Produced with KiCad 9.0.3 and
    Freerouting 2.2.4; the schematic is unchanged.
    Co-Authore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

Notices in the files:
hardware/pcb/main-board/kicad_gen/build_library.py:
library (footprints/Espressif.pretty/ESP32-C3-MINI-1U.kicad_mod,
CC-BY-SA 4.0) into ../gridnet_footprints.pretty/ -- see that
